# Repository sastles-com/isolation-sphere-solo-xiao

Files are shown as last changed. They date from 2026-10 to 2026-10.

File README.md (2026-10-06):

# isolation-sphere solo (XIAO ESP32S3 版)

> M5AtomS3R 版 ([isolation-sphere-solo](https://github.com/sastles-com/isolation-sphere-solo)) から分岐した、
> **XIAO ESP32S3 向けのリポジトリ**。LCD・本体ボタン・M5 ライブラリを持たない。本体の操作は iPhone の
> Web UI と IMU のトリプルシェイクで行い、今後は北極のホール素子をボタンにする (計画)。
> 共通部品の修正は AtomS3R 版から手動で取り込む。

球体 LED ディスプレイのファームウェア。**server なし (solo) と server あり (配信) の両方を 1 つの
バイナリで動かす**。

- **solo**: ESP32-S3 が SoftAP を立て、LittleFS に保存した 1 本の動画 (320×160 / 10fps) を電源投入だけで
  自動ループ再生する。動画の差し替えと再生操作は、個体シールの QR から iPhone を接続して
  Web UI (`http://192.168.4.1/`) で行う。MQTT ブローカー・配信 server・ルーター・インターネットは不要。
- **server モード** (`config.json` の `wifi{}` を有効にする、または Web UI の「サーバ接続 ON」): 同じ
  ファームが配信 server の P2P 網にも STA で入り、UDP で届く JPEG を優先して表示し、MQTT で操作を
  受ける。配信が 2 秒途切れると本体の動画に戻る。AP と Web UI はどちらのモードでも使える。

IMU による姿勢補正は描画側で動作し、球体を回しても映像の向きが保たれる。

> 派生元: [sastles-com/sastle-isolation-sphere](https://github.com/sastles-com/sastle-isolation-sphere)
> (server + core 構成)。本リポジトリは core の後継 (superset)。IMU スタック・OTA パーティション・
> 起動耐性は本リポジトリの方が新しく、MQTT / UDP のプロトコルは派生元の Python server と互換
> (server 側の変更は不要)。

---

## クイックスタート

```bash
# 1. ファームウェアと LittleFS を書き込む (初回は USB 必須: パーティション表を更新する)
pio run -e xiao_esp32s3 -t upload
pio run -e xiao_esp32s3 -t uploadfs

# 2. 動画を変換する (ffmpeg / ffprobe が必要)
tools/make_solo_video.sh input.mp4 video.mjpg -q 6

# 3. 電源投入 -> 個体シールの QR (tools/make_wifi_qr.py) を iPhone のカメラで読む -> AP に接続
#    -> 自動で開く画面、または Safari で http://192.168.4.1/ を開く
#    -> video.mjpg をアップロード
```

以降は電源を入れるだけで自動再生する (iPhone も PC も不要)。

## 動作の流れ

```
                  ┌──────────────── ESP32-S3 (XIAO) ────────────────────┐
                  │                                                      │
 iPhone ──Wi-Fi──▶│ SoftAP  ─▶ httpd (Web UI / アップロード)  [Core 0]    │
   │              │              │                                       │
   │ シールの QR   │              ▼                                       │
   └──個体シール───│         LittleFS  /video.mjpg                        │
                  │              │                                       │
 server ──STA────▶│ UDP (JPEG チャンク) ─▶ キュー   MQTT (操作/telemetry)  │
 (任意)           │              │                                       │
                  │    FramePump (1 タスク: 配信優先 / 100ms 締切) [Core 0] │
                  │      UDP 再構成 or ファイル読み ─▶ JPEG デコード ─▶ RGB565│
                  │              │                                       │
                  │      トリプルバッファ (display/ready/decode)           │
                  │              │                                       │
                  │    LEDManager (IMU 姿勢で毎パス再マッピング) [Core 1]   │
                  │              ▼                                       │
                  │        WS2812 ×800 (5ストリップ, RMT 並列出力)         │
                  └──────────────────────────────────────────────────────┘
```

- 再生は 10fps 固定。描画は ~50-60Hz で連続駆動し、IMU (100Hz) の最新姿勢で毎パス再マッピングする
  ため、動画のフレームレートと追従性は独立している。
- 締切は単調クロック (`esp_timer`) で管理し、遅れた締切は捨てる (遅延を溜め込まない)。

## リポジトリ構成

```
platformio.ini            ビルド設定 (xiao_esp32s3 / *_ota / native)
partitions.csv            フラッシュ配分 (OTA 2MB×2 + LittleFS 3.94MB)
src/                      ファームウェア
  main.cpp                起動順・タスク構成・loop (OTA / ネットワーク / MQTT / ログ)
  FramePump.{h,cpp}       フレーム供給の単一タスク (UDP 再構成 or ローカル再生 → デコード)
  SourceArbiter.h         配信 / ローカルの調停ポリシー (純粋、PC でテスト)
  SoloPlayer.{h,cpp}      ローカル MJPEG 再生の状態管理と 1 フレーム供給
  UdpReceiver.{h,cpp}     AsyncUDP → PSRAM キュー / FrameReassembler.h (16B ヘッダのチャンク再構成)
  DeviceController.{h,cpp} 操作の共通窓口 (HTTP / MQTT / コンソールが呼ぶ。γ2.2 明るさ、NVS 保存)
  SoloWebServer.{h,cpp}   Web UI・制御 API・アップロード・キャプティブポータル
  MQTTManager.{h,cpp}     MQTT (PubSubClient)。CommandHandler / Telemetry / TimeSync / RemoteLog
  MjpegReader.{h,cpp}     raw MJPEG の逐次読み出しと全件検証
  JpegScan.h              JPEG マーカー追跡によるフレーム境界判定 (PC でテスト可)
  ImageManager.{h,cpp}    JPEG デコード + トリプルバッファ
  LEDManager.{h,cpp}      球面 UV マッピング (SphereMap.h) / IMU 再投影 / FastLED 出力
  IMUManager.{h,cpp}      BNO055 (imu/*.h: 化け値検出・平滑・診断) 100Hz
  NetworkManager.{h,cpp}  SoftAP + STA (NVS の LAN > config の P2P 網)、Wi-Fi QR 文字列
  ...                     ConfigManager, Settings (NVS), FileManager, GestureManager, SoundManager, OtaManager
data/                     LittleFS に書き込む内容 (config.json, LED レイアウト CSV)
test/                     PC 上の単体テスト (JPEG 境界 / MJPEG 組み立て / IMU / 球面写像 / 調停 / 再構成)
tools/                    動画変換 / QR 生成 / OTA (ota.sh) / UDP 配信テスト (stream_to_sphere.py)
docs/solo_mode.md         設計と運用の詳細 (仕様・API・実機チェック手順)
docs/handoff.md           実装依頼時の仕様書
```

## 対応ボード

| env | ボード | 構成 |
| --- | --- | --- |
| `xiao_esp32s3` (既定) | Seeed XIAO ESP32S3 | 5ストリップ×160 LED (GPIO 1/2/3/4/44)、ブザー (GPIO43)、外部 BNO055、LCD なし。接続案内の QR は個体シール。ピンは `src/BoardConfig.h` に集約 |

## 動画の要件

- raw MJPEG: Baseline JPEG (SOF0) を区切りなしで連結したもの
- 320×160、10fps、音声なし、1 フレーム 64KiB 以下
- progressive JPEG・解像度違い・途中で切れたファイルは受理しない

`tools/make_solo_video.sh` が ffmpeg で変換し、ffprobe で解像度・フレーム数・最大フレームサイズを検査する。

容量: LittleFS 3.94MB のうち動画に使えるのは約 3.8MB。平均 10KiB/フレームなら約 38 秒。

## 操作

| 手段 | できること |
| --- | --- |
| Web UI (`http://192.168.4.1/`) | 状態確認、再生/一時停止/停止、明るさ、動画の変換とアップロード/削除、表示パターン、IMU 平滑、映像ソース、サーバ接続 ON/OFF、LAN 接続、再起動 |
| HTTP API | `GET /api/status`、`POST /api/play|pause|stop`、`/api/brightness`、`/api/led`、`/api/imu`、`/api/source`、`/api/server`、`/api/power`、`/api/wifi`、`/api/video`、`/api/video/delete`、`/api/reboot` |
| MQTT (server モード) | `sphere/all|<id>/command/{params,playback,led,system}` を受信、`sphere/<id>/{status,state,imu,log,gesture}` を送信 (派生元と同じ) |
| シリアルコンソール (115200) | `help` / `status` / `play` / `pause` / `stop` / `led sphere|test|off` / `bri N` / `server on|off` / `ap on|off` / `ap idle N` / `msleep on|off` / `power` (AP 切替) / `reboot` |

設定は `data/config.json` (`solo.ap.*`、`wifi{}` = server の P2P 網と broker、`source{}` = 調停、
`spheres[]` = MAC → 自機 ID / 固定 IP)。書き込みは `pio run -t uploadfs` (USB)。**サーバ接続の ON/OFF
だけは Web UI / コンソールから球体上の config.json を書き換えて再起動できる** (OTA では LittleFS を
更新できないため)。明るさ・軸表示・IMU 平滑・LAN の資格情報は NVS に保存される。

`solo.ap.ssid` は SSID の接頭辞です。実際の SSID は基板の MAC を付けた
`isolation-sphere-F09E9E3267D0` のような名前になり、複数台でも区別できます。
最大 32 bytes に収まるよう接頭辞を短縮し、Web 画面にも同じ名前を使います。
更新後は新しい SSID に接続し直してください。server モードの機器 ID・固定 IP は
`spheres[]` の MAC 登録で割り当てるため、追加基板には重複しない ID と IP を登録してください。

## 省電力 (AP / モデム)

球体の消費電力は WS2812 800 個が支配的ですが、デモ中は AP が不要なので止められるようにしてあります。
**電源投入時は常に AP 起動** で始まります。

| 機能 | 内容 |
| --- | --- |
| AP 自動停止 | 接続端末が 0 台のまま設定時間 (既定 10 分。しない/5/10/30/60) が経つと AP を止める。LAN (STA) が無ければ無線ごと止まる。設定は NVS に保存 |
| AP の ON/OFF | Web UI の「今すぐ停止」、`ap on|off`、MQTT `system` の `ap` |
| モデム省電力 | STA 接続中のビーコン間スリープ (WIFI_PS_MIN_MODEM)。既定 OFF。**AP だけの構成ではほぼ効かない** (AP は眠れない)。ON だと応答が鈍り UDP 映像を取りこぼしうる |
| トリプルシェイク | AP の ON/OFF を切り替える。従来の UI モード (回転アクション) は未実装だったため置き換え |

AP が止まっても再生は続きます。復帰は、シェイク / シリアル / MQTT / 電源の入れ直しのいずれかです。

## 開発

```bash
pio run -e xiao_esp32s3      # ビルド
pio test -e native            # 単体テスト 67 件 (実機不要)
pio device monitor            # シリアルログ (115200)
pio run -e xiao_esp32s3_ota -t upload   # OTA 書き込み (先に PC を AP へ接続)
tools/ota.sh                  # LAN / P2P 網経由の OTA (STA の IP を解決して直指定)
python3 tools/stream_to_sphere.py --target <STA の IP> --fps 15   # UDP 配信テスト (Pillow が必要)
```

詳細・設計判断・実機チェック手順は [docs/solo_mode.md](docs/solo_mode.md) を参照。

Mac で AP 経由の OTA を行う場合は、インターネット接続中に `xiao_esp32s3` をビルドし、
`tools/ota-ap.command` をダブルクリックしてください。ターミナルの案内に従って対象 core の
AP に接続し、Enter を押すとビルド済みファームを転送します。転送中のインターネット接続は不要です。
再起動後は新しい SSID に接続して Enter を押すと起動状態を確認できます。

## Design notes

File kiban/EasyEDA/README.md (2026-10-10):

# Isolation Sphere 電源システム — 基板A / 基板B

## 目的

次期 Isolation Sphere 電源システムの基本アーキテクチャを定義する。
別の LLM / 技術者がチャット履歴から判断を再構成せずに、EasyEDA で回路図と PCB を実装できるようにするためのパッケージである。

2026-10-07、本パッケージを電源系の正式案として採用した。
`kiban/power-2s`（IP2326 + MP1584、5V LED）は参考資料扱いとする。

設計は意図的に、40 mm × 40 mm の基板2枚を重ねる構成としている。

- **基板A — システム電源 / mother-ring インターフェース**
- **基板B — 電池 / 充電 / BMS**

基板Aは上側で MCU / 北極側を向く。基板Bは下側で LiPo パックを向く。

## システム要件

- 電池：**2S LiPo、2000 mAh × 2 直列**（40 × 40 × 10 mm を北と南に 1 個ずつ。重ね順は `docs/easyeda_workflow.md` §5.5、実機で収納確認済み）
  - 公称電圧：7.4 V（`VSYS` の公称値もこれに従う）
  - 満充電：8.4 V
  - 容量は 2000 mAh のまま（公称約 14.8 Wh）
- 充電入力：**南極のマグネット充電端子から 5〜12 V（推奨 12 V）**（`docs/hardware_spec.md` §3）
- 充電中の動作：**必須**
- 表示：アドレス指定型 LED 約 800 個
- 使用 LED：**WS2812C-2020-V6**（確定）を **3.3 V LED レール**で駆動
- LED レール：**想定 3 A、システムとして 4 A を確保。変換器は余裕のある品種を選ぶ**
- MCU レール：独立した **3.3 V レール**、**1〜2 A クラス**
- MCU：北極付近の別基板上の ESP32-S3（XIAO ESP32S3）
- 主制御バス：MCU 側からの I²C
- 基板サイズ：**各 40 mm × 40 mm**（基板Aは左右にソケット用の張り出し。基板Bは 37 mm 角または隅を面取りする案を検討中。`docs/easyeda_workflow.md` §5.5）
- 基板Aは両面実装可
- **基板Bの裏面は部品禁止**（LiPo パウチに面するため）
- 基板Bと LiPo の間に電気的・機械的な絶縁フィルムを挟む
- LiPo 側の面では、突起・露出パッド・鋭い基板角・不要な露出ビアを避ける

## 現在の基本アーキテクチャ

### 基板A — システム電源

mother-ring へ配る電源レールを生成し、電源 ON/OFF 制御を行う。

主な機能：

- LTC2954-1 電源 ON/OFF コントローラ
- 北極ホール起動センサ用の常時オン低 Iq レギュレータ
- LED 用 3.3 V 降圧コンバータ（4 A 必須、5〜6 A クラス推奨）
- MCU 用 3.3 V 降圧コンバータ（1〜2 A クラス）
- mother-ring との接続：1×6、2.54 mm コネクタ 2 個
- ESP32 からの `LED_EN` で LED 降圧を制御
- MCU 降圧は LTC2954 が制御
- ESP32 からの `PWR_KILL` で通常シャットダウン
- DRV5032FC からの `HALL_WAKE` で起動 / ハードウェア長押しを行う

### 基板B — 電池 / 充電 / BMS

2S LiPo と充電インターフェースに直結する。

主な機能：

- BQ25792 2S 充電 / パワーパス IC（昇降圧、入力 3.6〜24 V、LCSC C2862876）
- BQ28Z620 1〜2S 残量計 + パック保護 + セルバランス（BQ28Z610-R1 の後継、ピン互換）
- BQ28Z620 リファレンス設計どおりの外付け保護 FET と電流検出シャント
- 2S 電池接続：セルごとに JST XH 2P。直列接続とセル中点（BM）は基板B上で作る
- 南極マグネット充電端子からの充電入力
- 基板Aへの保護済み / システム電池出力
- 基板A / mother-ring 経由で ESP32 と I²C 接続

### 置き換え対象の旧モジュール

以下は現行 / 旧ハードウェアのもので、**新設計の基本構成ではない**。

- IP2326 充電モジュール
- BQ25883（旧案。12 V 入力に対応できないため BQ25792 に変更）
- XR-2S-30A BMS 基板
- MP1584 5 V 変換モジュール
- MAX16054 電源スイッチコントローラ
- MAX17049 残量計

実績のある動作や特性は検証時の参考にしてよいが、新設計はゼロベースで行う。

## 北極のデバイス

北極には以下がある。

- **DRV5032FC**：常時オンのデジタルホールスイッチ（全極性・オープンドレイン・20 Hz）。電源 ON と、LTC2954 へのハードウェア長押し経路に使う。
- **WS2812C-2020-V6 ×1**：北極の LED。XIAO の D5 から直接駆動する 6 本目のストリップ（1 個）。電源は `3V3_MCU` なので、`LED_EN` と関係なく起動・状態表示に使える。
- 動作確認用の赤 LED：DRV5032FC が磁石を検出している間だけ点く（`3V3_AON` から約 1.4 mA。確認後は抵抗を外す）。

北極基板（`kiban/core-XIAO-04` の north-pole-04）と MCU 基板の間は 5 本（`3V3_AON`、`HALL_WAKE`、GND、`LED_D6`、`3V3_MCU`）。
I²C は北極へ行かない。ジェスチャ（通常 OFF を含む）は磁石ではなく、MCU 基板の IMU（BNO055）によるシェイクで判定する（2026-10-10 決定。TMAG5273 は廃止）。
- 任意の小型インジケータ LED：ホール / コマンドの受付表示のためだけに追加してよい。OFF 中に動作する必要は**ない**。

## 電源制御の動作

### 電源 ON

1. システムは OFF。
2. DRV5032FC は `3V3_AON` で常時動作している。
3. 北極に磁石を近づけて保持する。
4. LTC2954 が長押し（約 2 秒）を確認し、MCU 降圧を有効にする。
5. ESP32-S3 が起動する。
6. 表示電源が必要になった時点で、ESP32 が明示的に `LED_EN` をアサートする。

ON のために近づけた磁石を保持し続けても、OFF 操作とは扱わない。LTC2954 は起動後 512 ms は PB を無視し、その後は「一度離してから再び押す」ことで初めて OFF シーケンスを開始する。

### 通常の電源 OFF

1. システムは ON。
2. ESP32 が IMU（BNO055）で、OFF 用のシェイク動作を検出する。
3. ESP32 がブザーや北極 LED で予告し、取り消しがなければ OFF に進む。
4. ESP32 が最初に `LED_EN` をデアサートする。
5. ESP32 が必要な状態保存 / 終了処理を行う。
6. ESP32 が `PWR_KILL` を Low にして LTC2954 へ伝える。
7. LTC2954 が MCU システム電源を切る。

### 強制 OFF

ESP32 がハングしていても、磁石を十分長く保持すれば、LTC2954 の独立したハードウェアタイマでシステム電源を強制的に切れなければならない。

タイミングは LTC2954 データシートの式から以下とする（詳細は `docs/hardware_spec.md` §5）。

| 操作 | コンデンサ | 公称 | 部品ばらつき込みの範囲 |
| --- | --- | ---: | ---: |
| ON 長押し | C_ONT = 0.33 µF | 約 2.15 s | 約 1.5〜2.8 s |
| 強制 OFF 長押し | C_PDT = 1.2 µF | 約 7.8 s | 約 5.5〜10 s |

正式リリース前に実機で確認する。

## mother-ring 接続

基板Aには mother-ring と接続する **1×6、2.54 mm コネクタ**が左右に1個ずつある。

論理ピン割り当ては `docs/interfaces.md` にまとめている。

最大約 4 A の LED 電流が 1 本のピンに集中しないよう、LED 電源は左右の2系統に分けて給電する。

## 実装状況

アーキテクチャと各基板の役割は、回路図作成を始められる程度に確定している。ただし、部品レベルではまだ最新のデータシートとリファレンス設計との照合が必要な項目がある。それらは `docs/handoff.md` と `docs/hardware_spec.md` にまとめている。

回路図、パワーパス構成、保護構成、ピン割り当て、EasyEDA ライブラリ部品のレビューが終わるまで、製造用ファイルは作らない。

## 本パッケージのファイル

- `README.md`：プロジェクト概要と確定アーキテクチャ
- `docs/handoff.md`：実装担当（LLM / 技術者）への指示
- `docs/hardware_spec.md`：電気・機械・安全要件
- `docs/interfaces.md`：ネット、コネクタ、信号方向、電源ドメイン、ファームウェア要件
- `docs/design_spec.yaml`：スクリプト / 整合性チェック用の機械可読サマリ
- `docs/sources.md`：一次データシートへのリンクと確認チェックリスト
- `docs/easyeda_workflow.md`：EasyEDA での設計の進め方、基板間接続、LiPo 接続、コア内の収納検討
- `docs/cad/`：配置検討に使ったコアの STL と説明

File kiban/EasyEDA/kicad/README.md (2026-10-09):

# kicad/ — 回路図の KiCad 版（自動生成）

**このフォルダの回路図は自動生成物。手で編集しない。** 正本は EasyEDA Pro のプロジェクト `power-2s-xiao`。
KiCad で回路図を見る・レビューするためのスナップショット。

| フォルダ | 親シート | 子シート |
| --- | --- | --- |
| `boardA/` | `boardA.kicad_sch`（1 枚、`kicad_flat.py` で生成） | なし |
| `boardB/` | `boardB.kicad_sch`（1 枚に統合） | なし |

KiCad で `boardA/boardA.kicad_pro`（または `.kicad_sch`）を開き、親シートの四角をダブルクリックして各ページへ入る。

## 作り直し方

EasyEDA で回路図を変えたら、ブリッジを起動して EasyEDA を接続した状態で：

```sh
python3 tools/kicad/kicad_export.py          # 両方の基板
```

1. 各ページを開いて保存し、全要素を取り出す（`dump_<PAGE>.json`）
2. KiCad 10 形式の階層回路図に変換する
3. **kicad-cli で KiCad 本体にネットリストを書き出させ、EasyEDA のネットリストとピン集合で比べる**。`✅ ネットリスト一致` が出ることを毎回確認する

作業中は EasyEDA のタブを切り替えない（別のページを取り出してしまう）。

## 変換の仕組み

| 項目 | 内容 |
| --- | --- |
| 接続 | EasyEDA の「ネット名を付けた線」を、つながった線の島ごとに KiCad のラベルへ置き換える |
| ラベルの種類 | 2 ページ以上に出てくるネット（`VSYS`、`GND`、`I2C_SDA` など）はグローバルラベル、それ以外はローカルラベル |
| シンボル | EasyEDA と同じピン位置を持つ矩形のシンボルを生成する（抵抗もジグザグにならない） |
| 文字・枠 | 注釈の文字と破線の枠をそのまま移す。ネット名を表すための文字は、ラベルと重複するので移さない |
| 座標 | EasyEDA 回路図 1 単位 = 0.254 mm。KiCad の標準グリッドに一致する |
| 部品の情報 | `LCSC`、`MPN` フィールドに保持する |

道具は `tools/kicad/`。座標変換・シンボル生成は、FPC-isolation-sphere の power-2S-02 で作った変換ツール（`eda2kicad_core.py`）を取り込んだもの。

## LCSC のシンボル・フットプリント（`kicad/lib/`）

`easyeda2kicad` で、LCSC 番号からシンボル・フットプリント・3D モデルを取得して使う。

```sh
pipx install --backend pip easyeda2kicad      # 初回だけ
python3 tools/kicad/lcsc_lib.py                # 未取得の部品を取得して整える
python3 tools/kicad/kicad_export.py            # 取得したシンボルで作り直す
```

- `kicad/lib/lcsc.kicad_sym`、`lcsc.pretty/` は Git に入れる。`lcsc.3dshapes/`（1 部品 2〜3 MB）は入れない。必要なら `lcsc_lib.py` で取得し直す
- 各プロジェクトの `sym-lib-table` / `fp-lib-table` に `lcsc` ライブラリを登録済み
- 取得したシンボルは、EasyEDA の回路図とピン位置が一致する向き（0/90/180/270°）を自動で探して使う。合わない部品と未取得の部品は、従来の矩形シンボルにする
- **EasyEDA の API は、続けて 30 部品ほど取得すると 403 を返す**（一時的なブロック）。時間を置いて `lcsc_lib.py` を再実行すると、未取得の部品だけを取得する

## 限界

- 未取得の部品は矩形シンボルで、フットプリントは空
- **ERC は通らない。** 電源フラグ（`PWR_FLAG`）がないため
- 取得したフットプリント（特に QFN の熱パッドとピン番号）は、データシートと照合していない

## 検証結果（2026-10-08）

| 基板 | 部品 | 2 ピン以上のネット | 結果 |
| --- | ---: | ---: | --- |
| 基板A | 44 | 23 | ✅ 一致 |
| 基板B | 67 | 43 | ✅ 一致 |

## 基板B は KiCad 側で統合した（2026-10-09）

基板B の回路図は、CHARGER と PROTECTION を手で 1 枚（`boardB/boardB.kicad_sch`）に統合し、**KiCad 側が元データ**になった。
EasyEDA からの自動生成（`kicad_export.py boardB`）は、統合前の 2 枚構成を作り直して上書きするので、**もう実行しない**。
フットプリントと LCSC 品番の割り当ては `python3 tools/kicad/assign_footprints.py`（L2 は `lcsc_lib.py` で C87572 を取得してから）。

## 基板A も 1 枚にした（2026-10-09）

基板A は、EasyEDA のダンプとネットリストから、基板B と同じ書き方で 1 枚の回路図に作り直した。

```
python3 tools/kicad/kicad_flat.py      # → kicad/boardA/boardA.kicad_sch、refmap.json
```

- ルール：階層なし 1 枚（A3）、機能ごとの点線の枠と日本語の見出し、接続は短い線 + グローバルラベル、GND は部品ごとに GND 記号、
  標準の抵抗・コンデンサ・インダクタ記号、通し番号の部品名（旧名は `refmap.json` と、部品の `EasyEDA` プロパティ）
- 生成の直後に kicad-cli のネットリストを、EasyEDA のネットリスト（`outputs/schematic/boardA_nets.txt`）と照合する
- 基板A の元データは EasyEDA のまま。回路を変えたら、EasyEDA を直し、ダンプとネットリストを更新して、`kicad_flat.py` を実行する。
  KiCad 側で手直しすると、次の生成で上書きされる（基板B と違い、基板A は KiCad を元データにはしていない）

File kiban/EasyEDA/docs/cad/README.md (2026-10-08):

# コアの STL（配置検討に使ったもの）

`tools/fit_check.py` が基板とセルの収まりを調べるときに読む STL。2026-10-08 に保存した。

| ファイル | 内容 | 三角形数 | SHA-256 |
| --- | --- | ---: | --- |
| `core-north-03_fixed.stl` | コア北半球（z = 0.8〜35.9） | 128,060 | `1618eacb0b87b0c43ef1db8b81d28fb9e6e38664ddcd4a09068b4914f9f9daea` |
| `core-south-03_fixed.stl` | コア南半球（z = 0.8〜44.9） | 139,892 | `1d71c652ab1ce8d9f98553ca6e833371c4f80c63eadead569d67c85ce4b5a66a` |

- 元のファイル：`FPC-isolation-sphere/shell-cad/output/` の同名ファイル（2026-06-17 / 06-18 作成）。
  元のリポジトリではこのフォルダ全体が `.gitignore`（`*`）で除外されているため、ここに保存しないと再現できない。
- 単位は mm、バイナリ STL。北半球・南半球とも、軸を z、極側を +z としてモデル化されている。
  南半球は赤道軸まわりに 180° 回して（y → −y、z → −z）南側に置く。
- mother-ring の STL は使っていない（作り直すため）。現行の `kiban/mother-ring/kiban-mother-ring.stl` は別にある。

## 断面が「島状」になるとは

コアを z 一定の平面で切ると、断面は 1 本の輪ではなく、円周に沿って並んだ**ばらばらの小さな塊**になる（`outputs/fit/section_z*.svg` の黒い線）。
塊は柱やボス（ねじ止め用の突起）で、塊と塊のあいだは空いている。さらに左右（±x）には、U 字の溝や四角い塊がある。

そのため、基板やセルが収まるかは、「軸から最も近い塊までの距離」ではなく、**塊の一つひとつに当たるか**で調べる必要がある。

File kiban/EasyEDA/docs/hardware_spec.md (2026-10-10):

# ハードウェア仕様

## 1. 機械的制約

### 基板A

- サイズ：40 mm × 40 mm
- 位置：上側。MCU / 北極 / mother-ring に近い側
- 部品：両面実装可
- 1×6、2.54 mm の mother-ring コネクタ 2 個を対向する辺に配置
- 大電流の 3.3 V 出力を基板Aから mother-ring へ配る

### 基板B

- サイズ：40 mm × 40 mm
- 位置：下側。LiPo パウチの直上
- **裏面：部品禁止**
- 裏面の突起、テストピン、露出したはんだ盛り、鋭い機械的形状を避ける
- LiPo 側の面のビアは、可能な範囲でテンティングする
- 基板の角を丸め、LiPo 付近の鋭いエッジを避ける
- 基板と LiPo の間に薄い絶縁 / 保護フィルムを入れる
- 損失の大きい充電・FET・シャント部品は部品面に置き、可能ならパウチ中央直上の最も熱い領域を避ける

## 2. 電池

- 2S LiPo
- 1 セル 2000 mAh を 2 直列
- 公称 7.4 V
- 満充電 8.4 V
- 公称エネルギー 約 14.8 Wh
- セル中点（`BM`）は取り出し可能で、現行設計でも使用している
- 接続：セルごとに JST XH 2P。直列接続と中点は基板B上で作る（`easyeda_workflow.md` §5）
- 放電終止：1 セル 3.2 V 以上（パック 6.4 V 以上）。XH の 3 A を超えないための条件
- 配置：セルは北と南に 1 個ずつ。重ね順（北から）MCU – セル – mother-ring – セル – 基板A – 基板B は、実機で収納を確認済み（`easyeda_workflow.md` §5.5）

## 3. 充電

要件：

- 南極のマグネット充電端子から入力
- 充電中もシステムが動作できること
- 充電 / システムのパワーパスがパック保護を迂回しないこと
- 小型の球体筐体であるため熱制限を考慮すること
- MCU が OFF でも充電できること
- 充電電流はセル仕様・入力電力の予算・熱性能から決める。IC が対応しているからといって 2 A を前提にしない

充電 IC：**BQ25792**（BQ25792RQMR、LCSC C2862876、2026-10-08 確定）

| 項目 | 値 |
| --- | --- |
| 方式 | 昇降圧、NVDC パワーパス、FET 4 個と BATFET を内蔵 |
| 入力動作範囲 | 3.6〜24 V（絶対最大 30 V）。入力過電圧保護の初期値は 26 V |
| 充電電流 | 最大 5 A（10 mA 刻み） |
| 電池からの放電電流 | 6 A RMS 連続、10 A ピーク（1 s 以内） |
| 電池のみで動作中の静止電流 | 17 µA typ（ADC 無効時） |
| I²C アドレス | 0x6B |
| パッケージ | VQFN-29（4 mm × 4 mm） |
| 互換品 | BQ25798（MPPT とバックアップ機能を追加、ピン配置は同じ） |

選定理由（比較は §3.3）：

- 5 V と 12 V のどちらの入力でも充電できる
- PROG ピンの抵抗で 2 セルを選ぶと、ホストなしで 8.4 V・1 A の充電を開始する（初期値）。MCU が OFF でも充電できる
- 入力過電圧保護の初期値が 26 V なので、12 V 入力でもホストの設定なしで充電が始まる
- BATFET の連続放電 6 A は、`VSYS` 最大約 3.1 A に十分な余裕がある

実装時の注意：

- PROG ピン：2 セルの抵抗値を使う（1.5 MHz なら 6.04 kΩ、750 kHz なら 8.2 kΩ）。周波数はインダクタの大きさと効率で決める
- ILIM_HIZ ピン：入力電流の上限を分圧抵抗で決める（`V = 1 V + 0.8 Ω × IINDPM`）。使う充電器の定格に合わせる
- ウォッチドッグ：初期値は 40 s。ファームから設定を変える場合は定期的に更新するか、ウォッチドッグを無効にする。放置すると設定が初期値に戻る
- 2 系統の入力切り替え（ACFET / RBFET）は使わない。入力は VAC1 / VBUS の 1 系統とする
- TS ピン：103AT-2（10 kΩ NTC）を推奨

実装は最新の TI データシートとリファレンス回路（BQ25792EVM）に従うこと。

### 3.1 電力予算

| 項目 | 値 |
| --- | ---: |
| LED 出力 3.3 V × 4 A | 13.2 W |
| MCU 出力 3.3 V × 1 A | 3.3 W |
| 出力合計 | 16.5 W |
| `VSYS` 入力（降圧効率 90% と仮定） | 約 18.3 W |

`VSYS` の公称は 7.4 V とする。電流は電池電圧に反比例するため、コネクタ・FET・銅箔は最低電圧で見積もる。

| `VSYS` | 電流（18.3 W） |
| --- | ---: |
| 8.4 V（満充電） | 約 2.2 A |
| 7.4 V（公称） | 約 2.5 A |
| 6.0 V（放電終止付近） | 約 3.1 A |

基板A↔B 間のコネクタ、BQ28Z620 の保護 FET、シャント、充電 IC の SYS/BATFET 経路は **3 A 以上の連続電流**を前提に選定する。
全負荷時の連続動作時間は 14.8 Wh ÷ 18.3 W ≈ **約 48 分**（変換損失以外の余裕は見ていない）。

### 3.2 充電入力電圧

全負荷で動作しながら 1 A（8.4 V）で充電するには、充電器の入力として概算で以下が必要になる。

- システム負荷：18.3 W ÷ 充電器効率 93% ≈ 19.7 W
- 充電：8.4 W ÷ 93% ≈ 9.0 W
- 合計：**約 29 W**

| 入力電圧 | 必要電流（29 W） | 判断 |
| --- | ---: | --- |
| 5 V | 約 5.8 A | 全負荷中の充電は不可。マグネット接点にも厳しい |
| 9 V | 約 3.2 A | 接点の定格次第で可 |
| 12 V | 約 2.4 A | 現実的 |

**方針**：BQ25792 は 3.6〜24 V を受けられるため、入力は **5〜12 V 対応、推奨 12 V** とする。

- 5 V の充電器も使える。ただし入力電力が小さいため、全負荷時は電池から不足分を補い、電池は減り続ける。充電が進むのは表示負荷が小さいときだけ。
- 12 V の充電器なら、全負荷中も充電できる。
- 12 V から 8.4 V へ下げるときの損失は約 1.5 W（効率 95% と仮定）。基板Bの熱設計に含める。

未決事項：

- 南極のマグネット接点と配線の電流定格を、12 V × 2.5 A で確認する
- 12 V の供給方法（12 V アダプタ、または USB-PD トリガ）
- ILIM_HIZ で設定する入力電流の上限

### 3.3 充電 IC の比較（2026-10-08）

| 項目 | BQ25883（旧案） | **BQ25792（採用）** | BQ25798 | MP2762A（MPS） |
| --- | --- | --- | --- | --- |
| 方式 | 昇圧のみ | 昇降圧 | 昇降圧 | 昇降圧（2 相） |
| 入力 | 3.9〜6.2 V | 3.6〜24 V | 3.6〜24 V | 約 4〜21 V（5.75〜8.5 V は不可） |
| 12 V 入力 | 不可 | 可 | 可 | 可 |
| 充電電流 | 2 A | 5 A | 5 A | 6 A |
| MPPT / バックアップ | なし | なし | あり（不要） | なし |
| 入力過電圧保護の初期値 | — | 26 V | 26 V | — |
| パッケージ | QFN-24 4×4 | QFN-29 4×4 | QFN-29 4×4 | QFN-30 4×5、インダクタ 2 個 |
| LCSC | C544362 | C2862876 | C2876593 | 在庫を確認できず |
| LCSC 100 個単価 | $2.10 | $1.35 | $2.00 | $2.4〜4.2（他の代理店） |

不採用の理由：

- BQ25883：12 V 入力に対応できず、5 V では入力が約 15 W に制限される
- BQ25798：BQ25792 の機能に MPPT とバックアップを加えたもの。本設計では不要で、価格が高い。ピン配置が同じなので、必要になれば差し替えられる
- MP2762A：インダクタが 2 個必要で、40 mm 角の基板Bでは面積が不利。LCSC の在庫を確認できない
- BQ25790（同系統）：入力過電圧保護の初期値が 7 V のため、12 V 入力ではホストが設定するまで充電しない

## 4. パック保護 / 残量計

残量計 / 保護 IC：**BQ28Z620**（BQ28Z620DRZR、VSON-12、2026-10-08 確定）

このサブシステムに求める機能：

- 1〜2S の残量計測
- パック保護
- 設定したしきい値による過電圧 / 低電圧 / 過電流 / 短絡保護
- シャントによる電流測定
- IC / リファレンス設計が対応する範囲でのセルバランス
- ESP32 への I²C 報告

外付けの保護 FET、電流検出シャント、サーミスタ、各種設定は、リファレンス設計（BQ28Z620EVM）の指示どおりに用意する。

このサブシステムは、旧構成の XR-2S-30A + MAX17049 を置き換える。

重要：ESP32 が OFF またはクラッシュしていても、保護は自律的に働くこと。

### 4.1 BQ28Z610 / BQ28Z610-R1 / BQ28Z620 の違い

| 項目 | BQ28Z610（無印） | BQ28Z610-R1 | **BQ28Z620（採用）** |
| --- | --- | --- | --- |
| 位置づけ | 初版 | 無印の I²C タイムアウト不具合をシリコンで修正。ファームウェアは無印と互換なし | R1 の後継。TI が新規設計に推奨 |
| パッケージ | VSON-12（DRZ） | 同じ | 同じ（ピン互換） |
| I²C | — | — | 1.2 V ロジックの I/O。VIH 0.78 V、SDA/SCL 推奨上限 5.5 V なので 3.3 V プルアップで使える |
| その他（620 の変更点） | — | — | 保護 FET のゲート駆動に 5.75 V を追加（SLEEP 時の消費電流を削減）、1 mΩ 未満のシャントに対応、BTP 機能を削除 |
| LCSC / JLC | C157573（在庫あり） | 見つからない | **C20345237**（LCSC、64 個）。JLC 登録 C22395771 は購入不可 |

無印は新規設計に推奨されないため使わない。フットプリントは 3 品種で共通なので、入手経路が決まらなくても回路図と PCB の作業は進められる。

### 4.2 設定の注意

- **ブロードキャスト（Master Mode）は無効にする。** スマートチャージャー向けに充電電流・電圧を I²C で送る機能で、BQ25792 は受け取らない。データシートの設計例では有効になっている
- 低電圧保護（CUV）は 3200 mV / セル以上にする（XH の電流定格のため、§2）
- I²C バスが約 2 秒 Low に保持されると、BQ28Z620 はバスを解放する（ハードウェアの初期値）
- 2S の設定、容量、化学特性（Chem ID）は bqStudio で書き込む。手順は BQ28Z620 テクニカルリファレンスマニュアルに従う

## 5. システム電源制御

基本構成：**LTC2954-1 + DRV5032FC**

### LTC2954（選定：LTC2954-1）

- 基板Aに配置
- `VSYS` から直接給電（動作範囲 2.7〜26.4 V、静止電流 6 µA typ）
- MCU 電源レールのイネーブルを制御
- 意図的に遅延させた電源 ON
- KILL による MCU 主導のクリーンなシャットダウン
- MCU が応答しない場合のハードウェア強制 OFF 経路

**バリアント**：**LTC2954-1**（EN はハイアクティブ、低リークのオープンドレイン）。MCU 降圧の EN（ハイアクティブ）に直結する。プルアップは降圧 IC 内蔵のものを使うか、外付けする。外付けする場合は、降圧 IC の EN 絶対最大定格を超えない電源へつなぐ。
パッケージは TSOT-23-8（LTC2954CTS8-1 / LTC2954ITS8-1）。LCSC の在庫は要確認。

**タイミング**（データシートの式 `C [µF] = 1.56×10⁻⁴ × (t[ms] − 1)`。ONT/PDT の内部電流 ±20%、コンデンサ ±10% で見積もった）：

| 項目 | 部品 | 計算 | 公称 | 範囲 |
| --- | --- | --- | ---: | ---: |
| ON 長押し | C_ONT = 0.33 µF | 32 ms + 2.12 s | 約 2.15 s | 約 1.5〜2.8 s |
| 強制 OFF 長押し | C_PDT = 1.2 µF | 64 ms + 7.69 s | 約 7.8 s | 約 5.5〜10 s |
| KILL ブランキング | 内部固定 | — | 512 ms | 400〜650 ms |
| OFF 後の再 ON 禁止 | 内部固定 | — | 256 ms | 200〜325 ms |

- コンデンサは X7R 以上、±10% 以内。ONT/PDT ピンは 2.7 V 以下で動作するため、DC バイアスによる容量低下は小さい。
- 起動直後の 512 ms は PB と KILL を無視する。その後、PB を「一度離してから押し直す」まで OFF シーケンスは始まらない。ON に使った磁石をそのまま保持しても OFF にはならない。
- システム ON 中に PB が 32 ms 以上 Low になると、INT 出力（オープンドレイン）が Low になる。INT は mother-ring コネクタに割り当てていない。使う場合は基板Aのテストパッドから引き出す（任意）。
- **`PWR_KILL` は基板A上で 100 kΩ を `3V3_MCU` へプルアップする。** MCU レールが立ち上がると KILL が自動で High になり、512 ms 以内の KILL 解除を満たす。ESP32 のリセット中（OTA 後の再起動やパニック）は GPIO がハイインピーダンスになるが、プルアップのため電源は切れない。プルダウンにすると、ESP32 がリセットするたびに電源が落ちる。ファームウェア要件は `interfaces.md` §7。

### DRV5032（選定：DRV5032FCDBZR）

- 北極に配置
- 常時オンの 3.3 V から給電（VCC 1.65〜5.5 V）
- 常時オンの磁気起動検出に使用
- **DRV5032FCDBZR**（SOT-23）を選ぶ。

| 項目 | FC の仕様 | 選定理由 |
| --- | --- | --- |
| 磁気応答 | 全極性（N/S どちらでも反応） | 磁石の向きを気にせず操作できる |
| 出力 | オープンドレイン、磁界検出時 Low | LTC2954 の PB（アクティブ Low、内部 100 kΩ で 1.9 V へプルアップ）に直結できる。プッシュプル品は PB の内部プルアップと競合するため不可 |
| サンプリング | 20 Hz（最大 50 ms の検出遅れ） | 2 秒の長押し判定には十分 |
| 平均消費電流 | 1.3 µA | OFF 中の電池消費が小さい |
| しきい値 B_OP | 最大 4.8 mT | 高感度 |

- 外付けプルアップは不要。PB の内部プルアップを使う。
- 北極から基板Aまで配線が長いため、LTC2954 データシートの推奨に従い、PB 直近に直列 5.1 kΩ と PB–GND 間 0.1 µF を置く。磁石検出時の PB 電圧は 1.9 V × 5.1k / 105.1k ≈ 0.09 V で、しきい値（0.6 V 以上）を十分下回る。
- 誤検出が問題になる場合の代替：**DRV5032AJ**（全極性・オープンドレイン、B_OP 最大 9.5 mT、同じピン配置）。
- 磁石の種類と、北極外殻からセンサまでの距離で磁束密度を確認する（未実施）。

### TMAG5273（廃止、2026-10-10）

- 当初は北極に置き、磁気ジェスチャと通常 OFF の検出に使う予定だった
- 北極への配線（7 本）を減らすため廃止した。I²C を北極へ通さず、配線は 5 本になった
- ジェスチャ（通常 OFF を含む）は、MCU 基板の IMU（BNO055）によるシェイクで判定する
- 磁石の役目は、ON（約 2.15 s）と強制 OFF（約 7.8 s）だけになった。どちらも DRV5032FC と LTC2954 のハードウェアで動く

### 北極の動作確認用 LED

- `3V3_AON` → 1 kΩ → 赤 LED → `HALL_WAKE`。DRV5032FC が磁石を検出して OUT が Low の間だけ点く（約 1.4 mA）
- 磁石がないときは LED に 3.3 − 1.9 = 1.4 V（PB の内部プルアップ）しかかからず、ほぼ流れない
- 確認が済んだら抵抗を外す

## 6. 常時オンレール

基板Aには、DRV5032FC と、本当に常時動作が必要な最小限の回路だけに `3V3_AON` を供給する専用の低静止電流レギュレータが必要。

設計目標：

- 超低 Iq
- 2S / `VSYS` の入力範囲に対応
- DRV5032FC（平均 1.3 µA）に少しの余裕を持たせた出力電流
- 選定したコンデンサで安定

明確な理由がない限り、残量計や大きなシステム負荷を AON レールに載せない。

OFF 中に電池から流れる電流の目安（レギュレータの Iq を除く）：LTC2954 6 µA + DRV5032FC 1.3 µA + BQ25792 17 µA + BQ28Z620 の待機電流。

## 7. 3.3 V コンバータ

独立した DC/DC コンバータを 2 個使う。

### LED 用コンバータ

- 入力：基板Aの `VSYS`
- 出力：3.3 V
- 想定最大負荷：約 3 A
- システムとしての設計能力：約 4 A
- 電流と熱の余裕のため **5〜6 A クラスの同期整流降圧**を推奨
- EN 入力が必須
- EN は ESP32 から `LED_EN` で制御
- MCU が未接続または起動中のときはデフォルト OFF
- `3V3_LED_L` と `3V3_LED_R` に供給

以前に検討した候補：TPS56637（6 A クラス）。レイアウト、入手性、効率、熱、EasyEDA / JLC 実装の制約を確認するまで、最終品種は**確定しない**。

### MCU 用コンバータ

- 入力：基板Aの `VSYS`
- 出力：3.3 V
- 目標：1〜2 A クラス
- LTC2954-1 の EN（ハイアクティブ、オープンドレイン）と互換の EN 入力を持つこと
- ESP32-S3 と、システム ON 中に動くロジック / センサに供給
- ESP32 の Wi-Fi 送信時の過渡電流に余裕を持って耐えること
- 立ち上がり時間は KILL ブランキングの最小値 400 ms より十分短いこと（通常の降圧のソフトスタートは数 ms なので問題ない見込み）

以前に検討した候補：TPS62162 は 1 A 品のため参考候補にとどめる。1 A を超える余裕が必要なら最終候補にはしない。

## 8. LED サブシステム

- 使用 LED：**WS2812C-2020-V6**（確定）
- LED レール：3.3 V
- 個数：約 800
- 北極の WS2812C-2020-V6 は、XIAO の D5 から直接駆動する 6 本目のストリップ（1 個）。電源は `3V3_MCU`（北極への配線を減らすため。最大 15 mA）
- LED 電源が OFF のときもデータ線を安全な状態に保つ。MCU 出力からデータピンを通して LED レールへ実質的に逆給電しないようにする

### 8.1 WS2812C-2020-V6 の仕様（Worldsemi データシート V1.0、2026-05-21）

LCSC C55109522（SMD2020-4P）。

| 項目 | 値 | 本設計への影響 |
| --- | --- | --- |
| 電源電圧 VDD | +3.3〜+5.3 V（「3.3 V で安定供給可能」と明記） | 3.3 V レールは保証範囲内。ただし下限ちょうど |
| 入力 High レベル VIH | 0.55 × VDD 以上（3.3 V 時 1.82 V） | ESP32 の 3.3 V 出力をレベル変換なしで直結できる |
| 入力 Low レベル VIL | 0.7 V 以下 | — |
| ロジック入力電圧 VI | −0.3 V〜VDD + 0.7 V | LED 電源 OFF 中にデータ線を High にすると定格外。FW-2 で Low に固定する |
| 各色の動作電流 | 5 mA（1 LED あたり最大 15 mA） | 下記の電流予算を参照 |
| 静止電流 | 1 µA 以下 | 800 個で 0.8 mA 以下 |
| 静電容量 / デカップリング | 各 LED の VDD に 100 nF 推奨 | mother-ring 側の設計事項 |

**電圧降下の余裕がない**：3.3 V は VDD の下限である。降圧の出力を 3.3 V ちょうどにすると、mother-ring のコネクタ・配線・ストリップの抵抗で電圧が下がり、末端の LED は保証範囲を外れる。
LED 降圧の出力は**分圧抵抗で 3.4〜3.5 V に設定できる構成**にしておき、実機で末端電圧を測ってから値を決める。
3.5 V にしても VIH は 1.93 V なので、ESP32 の 3.3 V 出力で駆動できる。

**電流予算**：全点白の最大輝度では 800 × 15 mA = 12 A になり、LED レールの設計値 4 A を大きく超える。
ファームウェアで全体の電流を 4 A 以下（1 LED あたり平均 5 mA 相当）に制限すること（例：FastLED の電力制限）。

## 9. I²C

I²C は ESP32-S3 の MCU 基板から出る。

接続予定のデバイス：

| デバイス | 位置 | 7 ビットアドレス |
| --- | --- | --- |
| BQ25792 | 基板B | 0x6B（データシートで確認済み） |
| BQ28Z620 | 基板B | 0x55（TI 残量計の標準。テクニカルリファレンスマニュアルで要確認） |
| BNO055（秋月 AE-BNO055-BO） | MCU 基板 | 0x28（出荷時） |

要件：

- デバイスアドレスの衝突を確認する
- プルアップの位置を意図して決める
- `3V3_MCU` が OFF のとき、プルアップを通じて逆給電しないこと
- 立ち上げ時のバス速度は控えめにする（例：100 kHz）。mother-ring / 積層基板経由の信号品質を確認してから上げる

## 10. 熱の優先度

発熱が大きいと予想される部品：

- LED 降圧コンバータとインダクタ
- 充電器の電力段とインダクタ
- 高負荷時のパック保護 FET / シャント

要件：

- 損失の大きい部品を LiPo 側の面から離す
- 機械設計が許す範囲で十分な銅箔面積 / サーマルビアを確保する
- 充電器と LED 降圧の熱を同じ場所に集中させない
- 開放したベンチだけでなく、閉じた球体の中で連続動作を確認する

## 11. 安全 / 検証

量産用の LiPo セルを接続する前に：

- 可能ならベンチ電源 / 電池シミュレータで充電動作を確認する
- セルごとの過電圧 / 低電圧動作を確認する
- 過電流 / 短絡保護を確認する
- 保護からの復帰動作を確認する
- 充電と負荷の同時動作を確認する
- ESP32 を意図的に応答不能にした状態で強制シャットダウンを確認する
- データ / 制御信号から無効化したレールへの逆給電がないことを確認する
- LED 負荷を連続でかけたときのコネクタ温度を確認する
- ON / 強制 OFF の長押し時間を実測し、§5 の範囲に収まることを確認する

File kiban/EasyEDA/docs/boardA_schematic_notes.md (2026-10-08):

# 基板A 回路図ノート（電源制御・3.3 V 電源・コネクタ）

2026-10-08 時点。EasyEDA の `power-2s-xiao` → `BoardA`。描き直しは `python3 tools/layout_boardA.py`。ネットリストは `outputs/schematic/boardA_nets.txt`。

## 1. ページ

| ページ（UUID） | 内容 |
| --- | --- |
| `P1`（`e671a2341d4b3a66`）→ 名前は POWER にする | U3 LTC2954-1（電源 ON/OFF）、U4 TPS70933（常時オン 3.3 V）、U5 TPS62933（MCU 用 3.3 V） |
| `P2`（`a9ace616ca30334c`）→ 名前は LED_IO にする | U6 TPS566238P（LED 用 3.3 V）、プルアップ、mother-ring 接続、基板B 接続 |

ページ名の変更（`modifySchematicPageName`）は、BoardA では API で反映されなかった。EasyEDA の画面で変える。

## 2. 主要部品（2026-10-08 決定）

| 記号 | 型番 | LCSC | 役割 |
| --- | --- | --- | --- |
| U3 | LTC2954-1（ADI、TSOT-23-8） | C683782 | 電源 ON/OFF。`EN` はハイアクティブのオープンドレイン |
| U4 | TPS70933（TI、SOT-23-5） | C89347 | 常時オン 3.3 V。入力最大 30 V、待機電流 1.4 µA、150 mA |
| U5 | TPS62933（TI、SOT-583-8） | C3200405 | MCU 用 3.3 V、3 A、入力 3.8〜30 V、OFF 中 2 µA |
| U6 | TPS566238P（TI、VQFN-HR-9 1.5 × 2 mm） | C2876603 | LED 用 3.3 V、6 A、入力 3〜18 V。P 付きは 9 番がパワーグッド（ソフトスタートは内部固定） |

不採用：TPS56637（$1.67、3 × 3 mm）、P なしの TPS566238（在庫 930 個）、TPS563201（OFF 中の電流が大きい）、TPS62162（1 A）。

## 3. 回路の要点

### 3.1 電源 ON/OFF（U3 LTC2954-1）

| ピン | 接続 |
| --- | --- |
| VIN | `VSYS`（0.1 µF） |
| PB# | `HALL_WAKE` → 5.1 kΩ → `PB_F`、`PB_F`–GND に 0.1 µF（長い配線のため。LTC2954 データシートの推奨） |
| ONT | 0.33 µF（C159798）→ ON 長押し 約 2.15 s |
| PDT | 1 µF + 0.22 µF（並列 1.22 µF）→ 強制 OFF 約 7.9 s |
| KILL# | `PWR_KILL`。`3V3_MCU` へ 100 kΩ でプルアップ（ESP32 のリセット中も電源を保つ） |
| EN | `MCU_EN` → U5 の `EN` に直結 |
| INT# | `PWR_INT` → テストパッド（任意） |

**U5 の `EN` を `VSYS` にプルアップしてはいけない。** TPS62933 の `EN` の絶対最大は 6 V。U5 の `EN` には内部プルアップ（0.7 µA）があり、開放で ON になる。LTC2954-1 の `EN` が L に引くと OFF。OFF 中の電流は 0.7 µA だけ。

### 3.2 常時オン 3.3 V（U4 TPS70933）

`IN` と `EN` を `VSYS` に。入力 1 µF、出力 2.2 µF。`3V3_AON` は北極の DRV5032FC だけに給電する（mother-ring の J_ML 6 番）。

### 3.3 MCU 用 3.3 V（U5 TPS62933）

- `RT` を GND：1.2 MHz
- 出力 = 0.8 V × (1 + 31.6 kΩ / 10 kΩ) = 3.33 V
- インダクタ 2.2 µH（SWPA4030S2R2NT、C279948、4 × 4 mm）。TI の推奨（1.2 MHz で 2.2 µH、実効 30 µF）
- 出力 22 µF × 2（C45783、0805 10 V）、入力 10 µF + 0.1 µF、ソフトスタート 10 nF（6.8 nF 以上が必須）、ブートストラップ 0.1 µF

### 3.4 LED 用 3.3 V（U6 TPS566238P）

- 出力 = 0.6 V × (1 + 93.1 kΩ / 20 kΩ) = **3.39 V**。WS2812C-2020-V6 の下限 3.3 V に余裕を持たせた。実測後に 93.1 kΩ を変えて調整する（3.46 V にするなら 95.3 kΩ）
- フィードフォワード 47 pF（TI の推奨 10〜100 pF）
- インダクタ 2.2 µH（SPM6530T-2R2M、C76855、7.1 × 6.5 mm）。TI の推奨は 1.5〜4.7 µH
- 出力 22 µF × 4、入力 10 µF × 3 + 0.1 µF、`VCC` 1 µF、ブートストラップ 0.1 µF
- `EN` = `LED_EN`、GND へ 100 kΩ（MCU が起動するまで OFF）
- `PG` = `L_PG` → テストパッド（任意）
- 電流：電池電流 2 A 制限のため、LED は最大 約 3.6 A（`interfaces.md` FW-2）

### 3.5 プルアップ（`3V3_MCU`、基板A に集約）

| ネット | 値 |
| --- | --- |
| `I2C_SDA`、`I2C_SCL` | 4.7 kΩ |
| `CHG_INT`（BQ25792 の INT） | 10 kΩ |
| `PWR_KILL` | 100 kΩ（POWER ページ） |

`3V3_MCU` は電源 OFF 中に 0 V なので、基板B の IC へプルアップを通じて逆給電しない。

### 3.6 コネクタ

| 記号 | ピン 1〜6 |
| --- | --- |
| J_ML（mother-ring 左） | `3V3_LED` / `GND` / `3V3_MCU` / `I2C_SDA` / `I2C_SCL` / `3V3_AON` |
| J_MR（mother-ring 右） | `3V3_LED` / `GND` / `GND` / `HALL_WAKE` / `PWR_KILL` / `LED_EN` |
| J_BA1（基板B 電源） | `VSYS` × 3 / `GND` × 3 |
| J_BA2（基板B 信号） | `I2C_SDA` / `GND` / `I2C_SCL` / `CHG_INT` / NC / `GND` |

`interfaces.md` の `3V3_LED_L` / `3V3_LED_R` は `3V3_LED`、`GND_L` / `GND_R` / `GND_SYS` は `GND` として 1 つのネットにした。

## 4. 確認・未決事項

1. **L3（SPM6530T-2R2M）の飽和電流**：U6 の過電流のしきい値（谷電流）は 6.1〜8.9 A。インダクタの飽和電流が、ピーク電流（約 9 A 以上）を上回るか、TDK のデータシートで確認する
2. **基板A↔B のピン 1 の向き**：基板A のピンヘッダは下向きに基板B の穴へ刺さる。PCB で、基板A の J_BA1 / J_BA2 のピン 1 と、基板B の J_AB1 / J_AB2 のピン 1 が重なるように配置する（片方は裏から見た配置になる）
3. テストパッド（`PWR_INT`、`L_PG`、主要な電源）を PCB で追加する
4. `VSYS` の入口（J_BA1 の近く）に、まとめのコンデンサを置くか（U3〜U6 の入力コンデンサで足りるかを PCB で判断）
5. mother-ring と MCU 基板側の回路は、KiCad から移植するときに、このピン配置に合わせて改版する

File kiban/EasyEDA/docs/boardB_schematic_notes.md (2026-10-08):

# 基板B 回路図ノート（充電・保護）

2026-10-08 時点。基板Bの回路図を EasyEDA で描くために、TI の一次資料から読み取った値をまとめる。
**電池の安全に関わる回路なので、描く前に §4 の決定が必要。値は TI の評価ボードの部品表を出発点にし、ゲート2のレビューで確認する。**

## 1. EasyEDA の状態

- プロジェクト `power-2s-xiao`（ユーザーが作成、2026-10-08）
- ボード：`BoardB`（回路図 `5ebeb43e1231a20b`、PCB `9fbb35c6f73cc004`）と `BoardA`（回路図 `5e620f3e36bb6729`、ページ p1 `e671a2341d4b3a66`、PCB `44537a4eae4b3566`）
- BoardB の回路図は 2 ページ：
  - `CHARGER`（`94446b1a98d03840`）：充電入力、BQ25792、出力、電力段、設定
  - `PROTECTION`（`3c04743d7cb514cc`）：主電流路、BQ28Z620、ゲート駆動、シャント、I2C、基板A 接続
- 描き直しは `python3 tools/layout_boardB.py`（両ページを消してから描く）。ネットリストは `outputs/schematic/`

### 描き方と、API の制約（2026-10-08 実測）

- 接続はすべて「ネット名を付けた線」。同じ名前の線は、ページをまたいでもつながる。ネット名は線の端に**文字**で表示している
- **API で作った GND 記号・電源記号（`createNetFlag`）とネットポート（`createNetPort`）は使えない。** 1 つでもあると `getNetlistFile()` が null を返し、DRC に致命的エラーが出る。同じ名前のネットポートが 2 つあるだけでも失敗した
- 部品を置く処理の途中で EasyEDA のタブが切り替わると、別のページに置かれる。道具は、部品・線ごとにページを確認する。**描いている間は EasyEDA のタブを切り替えない**
- `getNetlistFile()` は、開いているページが属するボードの回路図全体を返す
- 部品の回転は `create()` に渡した値と違って返ることがあるので、ピンの位置は必ず読み直す。ピンの回転（180 = 左、0 = 右、90 = 上、270 = 下）が、ピンの外向きの方向を表す

## 2. 充電部（BQ25792）

TI の BQ25798 データシート Figure 8-1（単一入力、シップ FET なし）より。BQ25792 は同じピン配置。

| 項目 | 値 |
| --- | --- |
| 入力の接続 | `VAC1` と `VAC2` を `VBUS` につなぐ。`ACDRV1` と `ACDRV2` は GND。外付けの入力 FET なし |
| インダクタ L1 | 1 µH（1.5 MHz 用、TI 例 SPM6530T-1R0M120）。飽和電流 2 A 以上、実際には入力電流の上限（3 A 以上）より大きいもの |
| `PROG` | 6.04 kΩ → GND（2 セル、1.5 MHz）。750 kHz なら 8.2 kΩ と 2.2 µH |
| `ILIM_HIZ` | `REGN` から 127 kΩ、GND へ 100 kΩ の分圧（TI 例）。入力電流の上限は `V = 1 V + 0.8 Ω × I`。使う 12 V アダプタに合わせて決める |
| `VBUS` | 10 µF × 2 + 0.1 µF（25 V 以上） |
| `PMID` | 10 µF × 3 + 0.1 µF（25 V 以上） |
| `SYS` | 10 µF × 5 + 0.1 µF |
| `BAT` | 10 µF × 2 |
| `BTST1` / `BTST2` | 各 47 nF（`SW1` / `SW2` との間） |
| `REGN` | 4.7 µF |
| `STAT` | 2.2 kΩ で `REGN` へ（TI 例）。LED 表示にするかは別途 |
| `TS` | `REGN` から 5.24 kΩ、GND へ 30.31 kΩ の分圧に 10 kΩ NTC（103AT-2）を並列。標準品に近い値（5.23 kΩ / 30.1 kΩ）で代用できるか確認 |
| `SDRV` | 1 nF → GND（シップ FET なし） |
| `QON#` | 使わない場合の処理をデータシートで確認 |
| `CE#`、`INT#` | `CE#` は GND（充電有効）か MCU 制御。`INT#` は基板A へ（`CHG_INT`） |

I²C のプルアップは、MCU 側（基板A）に置くか、基板B に置くかを決める（`interfaces.md` §3）。

### 2.1 充電入力（2026-10-08）

| 部品 | 内容 |
| --- | --- |
| J_CHG | 導線をはんだ付けする 2 穴。ピンヘッダ 2P（C492401）のフットプリントを使い、部品は載せない（BOM から除外）。1 = `VBUS`、2 = `GND`。線の先に PH 2P コネクタを付ける |
| D_TVS | SMF15A（BLUE ROCKET、C2900732、SOD-123FL、在庫 7,040 個） |

TVS の検討：

- 12 V アダプタの最大電圧（約 12.6 V）より遮断電圧が高く、BQ25792 の `VBUS` 絶対最大 30 V より低い電圧で抑えるものを選んだ
- SMF15A：遮断電圧 15 V、降伏電圧 16.7 V 以上、クランプ電圧 24.4 V（8.2 A）、200 W
- マグネット端子を抜き差しすると、配線のインダクタンスと入力コンデンサで電圧が跳ねる。TI は、15 V を超えるアダプタを抜き差しする場合に、入力の 2 Ω + 2.2 µF の RC を推奨している（BQ25798 データシート Figure 8-1 の注 1）。12 V では必須ではないが、試作で `VBUS` の跳ね上がりを測って判断する
- **未確認：** シンボルのピン名が `1` / `2` で、どちらがカソードかを名前で確認できていない。1 番をカソード（`VBUS` 側）として接続している。フットプリントの極性マークで確認する
- 逆接続の保護は入れていない。PH コネクタは向きが決まっているので、逆に挿さらない前提

## 3. 保護部（BQ28Z620）

TI の BQ28Z620 データシート Figure 10-1（2 直列）と、BQ28Z620EVM（SLUUCQ5）の部品表より。

構成：

- 保護 FET 2 個（充電用と放電用）を、セルのプラス側（高い側）に、向かい合わせに直列で入れる。ゲートは `CHG`（9 番）と `DSG`（7 番）から駆動する。
- 電流検出のシャントは、セルのマイナス側（低い側、`PACK−` との間）に入れる。`SRP` と `SRN` に各 100 Ω + 0.1 µF のフィルタ。
- `VC2`：スタック全体（BAT）の測定と電源。`VC1`：セル 1 とセル 2 の中点。各 100 Ω + 0.1 µF。`PBI` は 2.2 µF → GND。
- `PACK`（8 番）：パック電圧の測定。10 Ω を通して `PACK+` へ。
- `TS1`（4 番）：10 kΩ NTC（103AT-2）。
- `SCL`、`SDA`：100 Ω の直列抵抗と、5.6 V ツェナー（MM3Z5V6C）で保護。

EVM の部品表（抜粋）：

| 部品 | 値・型番 |
| --- | --- |
| 保護 FET（Q2、Q3） | CSD16412Q5A（Nch、30 V、SON 5×6） |
| シャント（R24） | 1 mΩ、1206（CSNL1206FT1L00）。データシートの推奨範囲は 1〜3 mΩ |
| NTC（RT1） | 10 kΩ（103AT-2） |
| 二次保護 IC（U1） | BQ294502DRV（過電圧の最大値 4.35 V） |
| ヒューズ溶断回路 | Q1（SI1416EDH）と Q4（2N7002K）、10 MΩ × 2 |
| ツェナー | MM3Z5V6C × 2（`SCL`、`SDA` 用） |
| 抵抗 | 100 Ω × 8、5.1 kΩ × 4、10 MΩ × 2 ほか |

EVM の電流定格は、BQ28Z620 の設計例で 6 A（過電流の閾値）。本設計の電池電流は最大約 3 A なので、シャントは 2 mΩ 前後でも足りる。値は、測定の精度と損失（3 A で 3 mΩ なら 27 mW）で決める。

## 4. 電池（実物）と保護の構成

電池は 104040（10 × 40 × 40 mm）、3.7 V 2000 mAh のポリマーセル（写真、2026-10-08）。

販売ページの記載（ユーザー提供、2026-10-08）：10 個入りセット、3.7 V 2000 mAh、10 × 40 × 40 mm、1 個 35 g。
**最大放電電流、保護基板（PCM）の過電流しきい値、充電電流の記載はない。** PCM の有無も記載にはなく、写真で確認できるだけ。仕様は、販売元への問い合わせか実測で確認する。

- **セルに保護基板（PCM）が付いている。** 側面に保護 IC とデュアル FET があり、リード線は赤（＋）と黒（−）の 2 本。
- PCM はセルのマイナス側に入っている。2 セルを直列にすると、保護が 3 層になる（セルの PCM、BQ28Z620 の保護 FET、必要なら二次保護）。

PCM があることで生じる問題：

1. **PCM の過電流保護のしきい値が不明。** 同種のセルでは 3 A 前後のことが多く、本設計の電池電流（全負荷で最大約 3 A）とほぼ同じ。全負荷で PCM が働いて、突然電源が落ちる恐れがある。
2. **2000 mAh のセルで 3 A は 1.5C。** 多くのセルの連続放電定格（1C 前後）を超える。セルの仕様書で、最大連続放電電流を確認する。
3. 2 本の PCM が直列に入るため、どちらかの PCM が働くと、電池全体が切れる。セル間のバランスは PCM では取れない。
4. PCM の FET の電圧降下で、電池電圧が約 0.1 V ずつ下がる（3 A で、1 セルあたり）。

対策（案）：

- 電池電流を **2 A 以下に制限する（ユーザー決定、2026-10-08）**。電池電圧ごとの LED 電流の目安は `interfaces.md` FW-2。
- セルの仕様書で、PCM の過電流しきい値と最大放電電流を確認する。確認できなければ、電流制限を設けて実測する。
- BQ28Z620 は、残量計とセルバランス、パック全体の保護に使う。PCM は、各セルの最後の保護として残す。

## 5. 保護 FET の選定

BQ28Z620 の標準回路（データシート Figure 10-1）の FET は、**共通ドレインの向かい合わせ直列**：

- 放電用（`DSG` で駆動）はパック側、充電用（`CHG` で駆動）は電池側に置く
- 2 つの FET のドレインを中央で共通にする。各ゲートは 5.1 kΩ を通して `DSG` / `CHG` へ。ゲートとソースの間に 10 MΩ

必要な条件：

| 項目 | 条件 | 理由 |
| --- | --- | --- |
| 構成 | 共通ドレインのデュアル N-ch（ゲートは別々） | 上記 |
| ゲート電圧の上限 | **±12 V 以上** | BQ28Z620 のゲート駆動は、初期設定（PMPDRV = 0）で約 9.5 V（最大 10.25 V）。5.75 V の設定もある |
| 耐圧 | 20 V 以上 | パック電圧は最大 8.4 V |
| 電流 | 連続 3 A 以上 | 電池電流（2 A 以下に制限、設計上は 3 A まで） |
| オン抵抗 | 1 個あたり 25 mΩ 以下（4.5 V） | 2 個で約 40〜50 mΩ。3 A で約 0.13 V、0.4 W |

注意：5.75 V に下げるビットの記述が、データシートの表（PMPDRV = 1 で 5.75 V）と本文（PMPDRV = 0 で 5.75 V）で食い違っている。ファームウェアで設定するときは、TRM で確認する。

候補（EasyEDA のライブラリで確認、LCSC）：

| 型番 | LCSC | パッケージ | Vds / Vgs / Id | Rds(on) | 在庫（2026-10-08） | 判定 |
| --- | --- | --- | --- | --- | --- | --- |
| **FS8205A（FUXINSEMI）** | **C908265** | SOT-23-6 | 20 V / ±12 V / 6 A | 18 mΩ（4.5 V、6 A）、最大 25 mΩ | 19,060 個、$0.058（10 個〜） | **採用候補。** 共通ドレイン（G1、D1/D2、G2、S1、S2）。ゲート ±12 V は、9.5 V 駆動に対して余裕 1.75 V。最大消費 1.5 W |
| FS8205A（TECH PUBLIC） | C2830320 | SOT-23-6 | 20 V / ±10 V / 6 A | 31.5 mΩ（2.5 V） | 33,710 個 | 不可：ゲート ±10 V は 9.5〜10.25 V 駆動に足りない |
| AO8810（AOS） | C21426 | TSSOP-8 | 20 V / ±8 V / 7 A | 20 mΩ（4.5 V） | 12,175 個 | 不可：ゲート ±8 V（5.75 V 駆動にしない限り使えない） |
| CJS2013 | C504157 | TSSOP-8 | 20 V / ±10 V / 6 A | 10.5 mΩ（4.5 V） | なし | 不可：在庫なし、ゲート ±10 V |
| FS8205A（Fortune） | C16052 | TSSOP-8 | 20 V / ±12 V / 9 A | 25 mΩ（4.5 V） | なし | 在庫なし |
| DMT3020LSD-13 | C268033 | SO-8 | 30 V / — / 16 A | 32 mΩ（4.5 V） | なし | 在庫なし |
| CSD16412Q5A（TI、評価ボード） | — | SON 5×6 | 25 V | — | 未確認 | 3 A には大きすぎる |

熱：SOT-23-6 の FS8205A は、3 A でも 1 個あたり約 0.2 W（2 個で約 0.4 W）。PCB の銅箔で逃がす。基板Bの裏面は部品禁止なので、部品面側に置き、LiPo の中央の真上を避ける。
より余裕が欲しければ、Vgs ±12 V 以上で TSSOP-8 の共通ドレイン品を、ほかのメーカーから探す。

## 6. ヒューズ

**入れる空間はある。** 1206 のヒューズは、本体が 3.2 × 1.6 mm、ランドを含めても約 4.4 × 1.8 mm。基板B（40 mm 角、隅を面取りして約 1,470 mm²）の面積に対して、ごくわずか。

置く場所：電池の＋（`B+`）から保護 FET へ向かう経路に直列。電池コネクタ（J_CELL2）の近く。
化学ヒューズ（BQ294502 による溶断）は入れない。セルの PCM と BQ28Z620 の保護がすでにあり、部品も増えるため。

### 6.1 使い切り型（不採用）

| 型番 | LCSC | 定格 | 在庫 | 判定 |
| --- | --- | --- | --- | --- |
| SF-1206S500-2（Bourns） | C913282 | 5 A、32 V DC、遅断型、遮断容量 50 A | 5,373 個、$0.28 | 不採用（リセッタブルを選んだため） |
| SF-1206S400-2（Bourns） | C1972812 | 4 A、32 V DC、遅断型 | 4,345 個、$0.27 | 4 A は、周囲温度の定格低減で 3 A がぎりぎり |

### 6.2 リセッタブル型（PPTC）の評価（2026-10-08、LCSC の在庫とデータシート）

電池電流は 2 A 以下に制限する（§4）。PPTC の保持電流は温度で下がるため、**閉じた球体の中の高温（60 °C 前後）でも 2 A を流せるか**が条件。

| 型番 | LCSC | サイズ | 保持 / 動作 / 耐圧 | 抵抗 | 在庫 | 保持電流 40 / 60 / 85 °C | 判定 |
| --- | --- | --- | --- | --- | --- | --- | --- |
| **SMD2920P500TF/16（PTTC）** | **C108585** | 2920（8.0 × 5.4 × 1.6 mm） | 5 A / 10 A / 16 V | 5 mΩ〜25 mΩ（動作後） | 4,380 個、$0.32 | 4.15 / 3.30 / 2.25 A | **成立する唯一の候補。** 85 °C でも 2 A を流せる |
| SMD1812P300SLR/24（PTTC） | C2892380 | 1812（4.7 × 3.4 mm） | 3 A / 6 A / 24 V | 1〜30 mΩ | 46,390 個、$0.39 | 2.45 / 1.85 / 1.05 A | 不可：60 °C で 1.85 A となり、2 A で切れる |
| SMD2920P300TF/16（RUILON） | C167318 | 2920 | 3 A / 6 A / 16 V | 12〜48 mΩ | 230 個 | 2.52 / 1.99 / 1.34 A | 不可：60 °C で 2 A を割る。在庫も少ない |
| SMD2920P400TF（PTTC） | C495360 | 2920 | 4 A / 8 A / 15 V | 10〜40 mΩ | 25 個 | — | 不可：在庫が少ない |
| JK-NSMD300L-12V（金科） | C516068 | 1206 | 3 A / 6 A / 12 V | 4〜20 mΩ | 10,080 個、$0.10 | 未確認（1206 は定格低下が大きい） | 保留：データシートで温度特性を確認できていない |
| MF-MSMF260-2（Bourns）、SMD1812P300TF（RUILON） | C89651、C21004 | 1812 | 耐圧 6 V、8 V | — | あり | — | 不可：耐圧がパック電圧 8.4 V より低い |

### 6.3 使い切り型とリセッタブル型の比較

| 項目 | 使い切り（SF-1206S500-2） | リセッタブル（SMD2920P500TF/16） |
| --- | --- | --- |
| 面積（本体） | 3.2 × 1.6 mm | 8.0 × 5.4 mm（約 5 倍） |
| 動作後 | 切れたまま。交換が必要 | 冷えると復帰する |
| 故障が残っているとき | 電流を完全に止める | 高抵抗のまま、約 2 W を消費し続ける（動作後の電力 Pd）。8.4 V では約 0.24 A が流れ続け、**熱が LiPo の近くで続く** |
| 動作の速さ | 速い | 遅い（20 A で最大 5 秒、5〜10 A では数十秒以上） |
| 通常動作での電圧降下（2 A） | — | 10〜50 mV、0.02〜0.1 W |
| 球体を開けずに復帰できるか | できない | できる |

どちらも、保護できるのは「5 A を超える異常」だけ。通常の過電流は、セルの PCM と BQ28Z620 の保護 FET が止める。

### 6.4 決定（2026-10-08）

**リセッタブルヒューズ SMD2920P500TF/16（PTTC、LCSC C108585）を使う**（ユーザー決定）。球体を開けずに復帰できることを優先する。

| 項目 | 値 |
| --- | --- |
| 型番 | SMD2920P500TF/16（PTTC、Polytronics） |
| サイズ | 2920（本体 8.0 × 5.4 × 1.6 mm）。ランドを含めて約 10 × 6 mm |
| 定格 | 保持 5 A、動作 10 A、耐圧 16 V、最大電流 40 A |
| 抵抗 | 初期 5 mΩ、動作後 25 mΩ（最大） |
| 動作後の電力 | 2 W（23 °C） |
| 保持電流の温度特性 | 40 °C：4.15 A、50 °C：3.75 A、60 °C：3.30 A、70 °C：2.90 A、85 °C：2.25 A |
| 在庫 | 4,380 個、$0.32（2026-10-08） |

設計上の注意：

- **動作後に 2 W を消費し続ける。** 故障が残っている間、約 0.24 A（8.4 V）が流れ続け、熱を出す。LiPo の近くに置かない。電池コネクタの近くで、セルから離れた基板の端に置き、周囲に銅箔の逃げと、部品の空き（約 2 mm）を設ける。
- 通常動作の電圧降下は、2 A で 10〜50 mV（0.02〜0.1 W）。`B+` 側に直列に入れる（電池の＋ → ヒューズ → 保護 FET）。
- 5 A 保持なので、保護できるのは 5 A を大きく超える異常だけ。通常の過電流は、セルの PCM と BQ28Z620 の保護 FET が止める。
- 高温でも 2 A を流せる（85 °C で 2.25 A）。これが、3 A 保持品を使わない理由。

## 7. 基板Bの外形

**隅を面取りした 40 mm 角にする**（ユーザー決定、2026-10-08）。A↔B 間隔 7 mm で、コアの内殻に当たらない大きさ（`tools/fit_check.py`）：

| 面取り | すき間 | 面積 |
| ---: | ---: | ---: |
| 7 mm | 0.6 mm | 94% |
| **8 mm** | **1.3 mm** | **92%** |
| 9 mm | 1.8 mm | 90% |
| 10 mm | 2.3 mm | 88% |

8 mm を初期値にする。コアの内殻を再設計するなら、面取りは小さくできる。

## 8. まだ決めること

1. PCM の過電流しきい値とセルの最大放電電流（セルの仕様書、または実測）
3. FS8205A（SOT-23-6）の熱の確認。気になる場合は TSSOP-8 の代替を探す
4. 充電 IC の `BAT` を、保護 FET の**パック側**（`PACK+`）につなぐ構成でよいか
5. 基板Bの `VSYS` の出力は、充電 IC の `SYS` から出す

## 9. 描く順序（案）

1. 充電部（BQ25792）：§2 の値で。部品の LCSC 番号を決めてから配置する。
2. 保護部（BQ28Z620、FS8205A、ヒューズ、シャント）：§5、§6。
3. 電池コネクタ（XH 2P × 2）、基板A との接続（ピンヘッダ 1×6 × 2）、テストポイント。

## 10. 回路図のレビュー観点（ゲート2）

EasyEDA で BoardB の回路図を開き、次の順に確認する。

### CHARGER ページ

1. **充電入力**：J_CHG の 1 番が `VBUS`、2 番が `GND`。TVS のカソードが `VBUS` 側（§2.1 の未確認事項）
2. **BQ25792 のピン**：`VAC1` / `VAC2` が `VBUS`、`ACDRV1` / `ACDRV2` が `GND`（入力 FET なし）。`D+` / `D−` / `QON` は未接続
3. **設定**：`PROG` 6.04 kΩ（2S、1.5 MHz）、`ILIM_HIZ` の分圧（127 kΩ / 100 kΩ = 入力 約 1.5 A）、`TS` の分圧と NTC、`CE` のプルダウン
4. **電力段**：L1 が `SW1` と `SW2` の間、ブートストラップ 47 nF が `BTST1`–`SW1`、`BTST2`–`SW2`
5. **出力**：`SYS` → `VSYS`（コンデンサ 10 µF × 5）、`BAT` → `PACK_P`、`BATP` が 100 Ω を通して `PACK_P`

### PROTECTION ページ（電池の安全に関わる）

1. **主電流路**：セル2 の＋（`BAT_TOP`）→ ヒューズ F1 → `BAT_F` → 保護 FET Q1 → `PACK_P`。ヒューズが FET より電池側にあること
2. **保護 FET の向き**：FET1（S1、G1）が電池側で `CHG` 駆動、FET2（S2、G2）がパック側で `DSG` 駆動。ドレインは共通
3. **ゲート**：各ゲートに 5.1 kΩ（`CHG` / `DSG` から）と、10 MΩ（それぞれのソースへ）
4. **グラウンド 2 系統**：`GND`（パック−）と `BAT_N`（セル−）の間に RSNS（2 mΩ）。`SRN` は `GND` 側、`SRP` は `BAT_N` 側の端から 100 Ω
5. **セル電圧**：`VC2` は 5.1 Ω で `BAT_TOP`（ヒューズの電池側）、`VC1` は 100 Ω で `BAT_MID`
6. **電池コネクタ**：J_CELL1 = `BAT_N` / `BAT_MID`、J_CELL2 = `BAT_MID` / `BAT_TOP`。セルの向きを間違えないこと
7. **基板A 接続**：J_AB1 = `VSYS` × 3 / `GND` × 3、J_AB2 = `I2C_SDA` / `GND` / `I2C_SCL` / `CHG_INT` / 予備 / `GND`

### 比べる資料

- BQ28Z620 データシート Figure 10-1（2 直列の標準回路）
- BQ25798 データシート Figure 8-1（単一入力、シップ FET なし）
- 本ノート §2〜§6

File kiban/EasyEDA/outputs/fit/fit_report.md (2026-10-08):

# 電池・基板の配置検討（fit_check.py の出力）

重ね順（北から）：MCU – セル – mother-ring – セル – 基板A – 基板B。
mother-ring は z = 0（板厚 1.6 mm）、南（LiPo 側）は −z。
mother-ring・MCU 基板と基板A の面間距離 11.0 mm（ソケット 8.5 + ヘッダ絶縁体 2.5）、基板A↔B 7.0 mm、基板厚 1.6 mm、セル 40×40×10 mm。

STL は `docs/cad/` の core-north-03_fixed / core-south-03_fixed。断面に現れる塊を一つずつ障害物として扱い、
基板やセルの輪郭が塊に当たるか、最小のすき間はいくつかを調べる。「干渉」は当たること。

## 基板A（実機の外形：張り出し x = ±25、y = ±9.25）

高さ z = -13.4〜-11.8 mm。外形を軸のまわりに回したときのすき間：

| 回転 | 張り出しの向き | すき間 |
| ---: | --- | --- |
| 0° | ±x 方向 | **干渉** |
| 15° |  | **干渉** |
| 30° |  | 0.4 mm |
| 45° |  | **干渉** |
| 60° |  | 0.4 mm |
| 75° |  | 2.1 mm |
| 90° | ±y 方向 | 2.3 mm |
| 105° |  | 2.1 mm |
| 120° |  | 0.4 mm |
| 135° |  | **干渉** |
| 150° |  | 0.4 mm |
| 165° |  | **干渉** |

張り出しの先端 x（回転 90°、幅 y = ±8.12 mm）の限界：

| 先端 x | すき間 |
| ---: | --- |
| 24.63 mm | 2.3 mm |
| 26 mm | 2.3 mm |
| 27 mm | 2.0 mm |
| 28 mm | 1.0 mm |
| 29 mm | 0.0 mm |
| 30 mm | **干渉** |

## 基板B

基板A↔B の間隔ごとに、基板B（本体 40 mm 角、角 R3）が入るかを調べた。

| A↔B 間隔 | 基板Bの高さ z | 40 mm 角 | 隅を 7 mm 面取り | 隅を 9 mm 面取り | 入る最大の一辺 |
| ---: | --- | --- | --- | --- | --- |
| 3 mm | -18.0〜-16.4 | 0.4 mm | 2.9 mm | 4.2 mm | 40.6 mm |
| 4 mm | -19.0〜-17.4 | 0.2 mm | 2.9 mm | 4.2 mm | 40.3 mm |
| 5 mm | -20.0〜-18.4 | **干渉** | 2.4 mm | 3.6 mm | 39.0 mm |
| 6 mm | -21.0〜-19.4 | **干渉** | 1.7 mm | 2.7 mm | 37.9 mm |
| 7 mm | -22.0〜-20.4 | **干渉** | 0.6 mm | 1.8 mm | 37.0 mm |
| 8 mm | -23.0〜-21.4 | **干渉** | 0.1 mm | 0.8 mm | 35.3 mm |

間隔 7 mm で 40 mm 角が当たる場所：z = -22.0〜-20.5、軸からの半径 24.6〜27.1 mm（四隅の 45° 方向）。

## セル（40×40×10 mm）

| 場所 | 高さ z | 一辺 40 mm | 一辺 39.5 mm | 一辺 39 mm |
| --- | --- | --- | --- | --- |
| 北：MCU 基板と mother-ring の間 | 1.3〜11.3 | **干渉** | 0.2 mm | 0.5 mm |
| 南：mother-ring と基板A の間 | -11.3〜-1.3 | 0.5 mm | 0.7 mm | 1.0 mm |

北のセル（40 mm）が当たる場所：z = 3.3〜10.3、|x| = 20.0〜22.9、|y| = 0.4〜10.0（x = ±20 mm の側面にある塊）。

## 断面図

緑：基板A（張り出しを ±y に向けた実機外形）・基板B（隅 7 mm 面取り）、青：セル。

- [section_z+6.svg](section_z+6.svg)
- [section_z-6.svg](section_z-6.svg)
- [section_z-13.svg](section_z-13.svg)
- [section_z-21.svg](section_z-21.svg)

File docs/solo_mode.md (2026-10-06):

> **XIAO ESP32S3 版の注記**: 本書は M5AtomS3R 版から引き継いだ。LCD・QR 表示・本体ボタン・M5 IMU に関する
> 記述と実機検証の記録 (§6 QR、§9 の AtomS3R 実測) は AtomS3R 版の経緯であり、本リポジトリでは該当機能を
> 削除している。XIAO 版の方針と計画は `docs/xiao_bringup.md`。

# solo 設計ノート

`isolation-sphere-solo` の設計判断、仕様、運用手順、実機チェック項目をまとめる。
使い方の概要は [../README.md](../README.md)、実装依頼時の仕様は [handoff.md](handoff.md) を参照。

---

## 1. 派生元の調査結果 (実装前に実コードで確認した事実)

本リポジトリは [sastles-com/sastle-isolation-sphere](https://github.com/sastles-com/sastle-isolation-sphere)
の `core/` (ESP32-S3 ファームウェア) を solo 専用に切り出したもの。切り出しの判断根拠として、
派生元のコードから確認した事実を残す (ハンドオフ資料は最新コードを読めていない前提で書かれていた)。

| 項目 | 事実 |
| --- | --- |
| ビルド | PlatformIO + Arduino framework、`board = m5stack-atoms3` (flash 8MB, PSRAM OPI) |
| パーティション | nvs / otadata / phy / ota_0 1.5MB / ota_1 1.5MB / spiffs(LittleFS) 3MB。末尾 約1.94MB が未使用 |
| **ファームサイズ** | **派生元をそのままビルドすると 1,723,509 bytes (1.5MB スロットの 109.6%) で収まらない**。release + `CORE_DEBUG_LEVEL=1` でも 1,594,145 bytes (101.4%)。この超過は solo 化前から存在していた |
| フレーム供給 | server → UDP チャンク (16B ヘッダ, ≤1400B) → 再構成 → TJpg_Decoder → RGB565 → トリプルバッファ |
| デコーダ | `bodmer/TJpg_Decoder` (Baseline JPEG のみ)、出力 RGB565、`setSwapBytes(false)`。デコードは Core0 |
| 描画 | FastLED RMT 並列出力、レンダタスクが Core1 prio2 で連続駆動 (~50-60Hz)。毎パス最新 IMU で再マッピングし、**フレーム到着に依存しない** |
| IMU | 100Hz 更新。`loop()` タスクで取得し、レンダタスクが読む |
| 制御 | MQTT (PubSubClient) を `loop()` で駆動、`CommandHandler` が params/playback/led/system を処理 |
| 設定 | LittleFS `/config.json` を ArduinoJson で読み書き。NVS/Preferences は未使用。**デバイスレベルの「モード」概念は無かった** (LED 出力モード sphere/pixels/off/test のみ) |
| LCD | M5AtomS3R 128×128、M5GFX (LovyanGFX)。LovyanGFX は `qrcode()` を内蔵 |
| デバイス内 HTTP / DNS | **無し**。`esp_http_server` と `DNSServer` は ESP-IDF / arduino-esp32 に同梱 |
| ローカル再生 | **無し**。`data/images/*.jpg` は LittleFS に載っていたがファームは読んでいなかった (1.2MB の無駄) |
| 既存ビルドエラー | `LEDManager.cpp` の `memset(CRGB[],…)` が FastLED 3.10 で曖昧呼び出しになり失敗。XIAO env は `kLedMaxPowerMa` 未定義で失敗 (いずれも本リポジトリで修正済み) |

**切り出しが成立する根拠**: 描画エンジンはフレームの供給元を知らない (トリプルバッファから読むだけ) ため、
「UDP 受信タスク」を「ローカルファイル読み出しタスク」に差し替えるだけで単独再生が成立する。
球面 UV マッピングと IMU 再投影は元々デバイス側で完結していた。

## 2. 採用した設計判断

- **供給元の差し替え**: `ImageManager::submitJpegFrame()` を入口とし、`SoloPlayer` タスクが LittleFS から
  読んだ JPEG を流す。描画・IMU・LED・球面マッピングは派生元のまま無変更。
- **動画形式 = raw MJPEG** (Baseline JPEG の連結、コンテナ無し)。AVI/multipart は受理しない。
  既存デコーダ (TJpg_Decoder) と同じ JPEG をそのまま使えるのが理由。
- **フレーム境界はマーカー追跡で判定** ([../src/JpegScan.h](../src/JpegScan.h))。`0xFFD9` の線形探索だと
  EXIF サムネイル (APP1) 内の EOI を誤検出するため、セグメント長を辿って SOI..EOI を確定させる。
  Arduino 非依存のヘッダオンリー実装にして PC 上で単体テストする。
- **10fps はファームウェア固定** (`kSoloFps`)。ファイル内の fps メタデータは参照しない。
- **締切管理は単調クロック** (`esp_timer_get_time`)。「デコード後に 100ms 待つ」方式ではなく締切を
  管理し、遅れた締切は捨てて次に揃える (処理時間によるドリフトと遅延の蓄積を避ける)。
- **1 フレーム上限 64KiB** (`kSoloMaxFrameBytes`)。ファイル内のサイズ値を無検証でメモリ確保に使わず、
  固定サイズの PSRAM バッファを使う。
- **UI はファームウェア埋め込み** (PROGMEM, 約 6KB)。LittleFS が壊れていても管理 UI を出して
  再アップロードできる。CDN・外部フォントには依存しない。
- **HTTP は ESP-IDF 同梱 `esp_http_server`、DNS は arduino-esp32 同梱 `DNSServer`** — 追加ライブラリ依存なし。
- **接続導線は QR + キャプティブポータル** (§6)。NFC は iOS が NFC 経由の Wi-Fi 参加に対応しないため不採用。
- **パーティション: OTA 2MB×2 + LittleFS 3.94MB** (§5)。OTA は削らず拡張し、派生元から存在した
  「ファームが OTA スロットに収まらない」問題も解消する。
- **アップロードは 一時ファイル → 全件検証 → rename**。容量が足りない場合のみ既存動画を先に削除し
  (UI に明記)、失敗時は「動画なし」で再アップロードできる状態にする。
- **server モード関連は削除** (MQTT 制御, UDP 映像受信, 時刻同期, リモートログ)。切り替えではなく
  削除にしたのは、単独動作に特化した独立リポジトリとして見通しを良くするため。server 構成が必要な
  場合は派生元リポジトリを使う。

### 削除したもの (派生元との差分)

| 削除 | 行数 | 理由 |
| --- | --- | --- |
| `MQTTManager.{h,cpp}`, `MqttTopics.h` | 421 | 外部ブローカーに依存しない。制御は HTTP API |
| `CommandHandler.{h,cpp}` | 602 | MQTT JSON コマンドの受け口。明るさ適用は `main.cpp` と Web API へ移動 |
| `TimeSync.{h,cpp}` | 154 | 複数球体の時刻同期ビーコン (server 前提) |
| `FrameReassembler.h` | 127 | UDP チャンク再構成 |
| `RemoteLog.{h,cpp}` | 161 | MQTT への tee ロガー → `Log.{h,cpp}` (Serial のみ, 14行) に置換 |
| `NetworkManager` の STA/UDP | — | SoftAP 専用に縮小 |
| `ImageManager` の UDP 経路 | — | `submitJpegFrame()` のみを入口に |
| `GestureManager` の MQTT 通知 | — | 検出結果は Serial ログへ |
| `server/` (Python + React), server 向けドキュメント・スクリプト | — | 本リポジトリの対象外 |
| `data/images/` (未参照の JPEG 200枚) | 1.2MB | ファームが読んでいなかった。LittleFS を動画に使う |

結果: ファーム 1,822,841 → **1,734,465 bytes** (約 88KB 減)、RAM 80,588 → **68,484 bytes** (約 12KB 減)、
LittleFS の同梱物 1.35MB → **39KB**。

## 3. アーキテクチャ

| 境界 | 実装 |
| --- | --- |
| ネットワーク | SoftAP (既定 `isolation-sphere` / 192.168.4.1、常時) + 任意の STA (NVS の LAN > config の P2P 網) + キャプティブ DNS |
| 映像入力 | `FramePump` (Core0、1 タスク) が UDP 配信 (`UdpReceiver` → `FrameReassembler`) とローカル `SoloPlayer::tick()` を調停 (`SourceArbiter`) し、`ImageManager::submitJpegFrame()` を呼ぶ唯一の場所。ローカル動画は open 時に **全体を PSRAM に読み込み**、再生中はフラッシュを読まない (§9 カクつき対策) |
| 制御入力 | `SoloWebServer` (esp_http_server) / `CommandHandler` (MQTT) / `SerialConsole` → いずれも `DeviceController` |
| 表示 | `LEDManager` レンダタスク (Core1) + IMU 再マッピング (`SphereMap.h`) |
| ログ | `sastle::Log` = `RemoteLog`: Serial + (server モードでは) MQTT `sphere/<id>/log` (PSRAM 退避 12KB) |
| 更新 | USB (`upload` / `uploadfs`) と OTA (espota: AP 192.168.4.1 / STA の IP) |

§10 に server モード (統合ファーム) の詳細。

### タスク配置

| タスク | Core | prio | stack | 役割 |
| --- | --- | --- | --- | --- |
| `LED_Render` | 1 | 2 | 8192 | IMU 再マッピング + RMT 出力 (~50-60Hz) |
| `imu` | 1 | 3 | 4096 | BNO055 100Hz 読み出し (Log を呼ばない。診断は loop が吐く) |
| `frame_pump` | 0 | 1 | 8192 | UDP キュー待ち (次のローカル締切まで) → 再構成 → デコード / 締切でローカル 1 フレーム。デコードは必ずここ |
| `async_udp` | 0 | — | — | AsyncUDP コールバック: データグラムを PSRAM キューへ (server モードのみ) |
| `httpd` | 0 | 2 | 8192 | Web UI / API / アップロード受信 (FS 書き込み) |
| `loopTask` | 1 | 1 | 8192 | OTA、STA 再接続、MQTT loop、ログ flush、DNS、設定保存/再起動、ジェスチャー、LCD、周期ログ・publish |
| WiFi/lwIP | 0 | 高 | — | SDK |

アップロード中 (FS 書き込み中) は再生を止める。フラッシュ書き込みはキャッシュ無効化で両コアに
影響するため、描画のちらつきが出る可能性がある (再生停止中なので実害は小さい)。

### 状態遷移 (SoloPlayer)

```
起動 ──有効な動画あり──▶ playing ──pause──▶ paused (表示は現在のフレームのまま)
  │                       │  ▲  ▲            │
  │                     stop │  └────play─────┘ (続きから)
  │                       ▼  │
  │                    stopped (LED 消灯。play で続きから)
  └─動画なし──▶ no_video (消灯)
  └─破損/解像度違い─▶ error (消灯)
アップロード開始 ─▶ uploading ─成功─▶ playing (先頭から)
                            └─失敗─▶ 旧動画があれば playing / 無ければ no_video
```

## 4. 動画形式と事前変換

受理条件 (アップロード時と起動時の両方で全フレーム検査):

- raw MJPEG: `FFD8 … FFD9` の Baseline JPEG (SOF0) を区切りなしで連結
- 全フレーム 320×160 (`config.json` の `image.width/height`)。他解像度は `resolution mismatch`
- progressive (SOF2) は `not a baseline JPEG` で拒否
- 1 フレーム ≤ 65536 bytes
- 途中で切れたファイル・末尾のゴミ・不正なマーカー構造は拒否 (部分ファイルは再生しない)

```bash
# 中央トリミングで 2:1 に合わせる (既定)。-q は 2(高画質)〜31(低画質)
tools/make_solo_video.sh input.mp4 video.mjpg -q 6
# 黒帯で収める / 先頭 30 秒だけ
tools/make_solo_video.sh input.mov video.mjpg --fit pad -t 30
```

MP4/MOV/HEVC を ESP32 上で変換する機能は無い (ESP32 では H.264 をデコードできない)。

### ブラウザ変換 (`docs/convert.html` → ファームに埋め込み `/convert`)

iPhone のカメラ動画を PC を介さずに変換するための単体ページ。**変換はすべて閲覧端末のブラウザ内**で
行われ、球体側の負荷はゼロ (ページを配信するだけ)。

```
Safari                                         ESP32
 <video> で H.264 デコード (HWデコーダ)          ← 負荷ゼロ
 canvas.drawImage() で 320×160 へ伸縮
 canvas.toBlob('image/jpeg') を Blob で連結
 POST /api/video ───────────────────────────▶  既存のアップロード経路 (変更不要)
```

`canvas` の JPEG 出力は Baseline (SOF0) なので `JpegScan` がそのまま受理する。APPn (JFIF/EXIF) は
マーカー長で読み飛ばされるため無害。**ファイルに fps 情報は入らない** (`SoloPlayer` は `kSoloFps=10`
固定で再生する) ので、「10fps にする」= 元動画のタイムラインを 100ms 刻みでサンプリングすることを指す。
30fps の全フレームを出力すると 3 倍のスローモーションになる。

| 項目 | 実装 |
| --- | --- |
| アスペクト比 | **2:1 への押し潰し固定** (元フレーム全体を 320×160 へ伸縮)。正距円筒として全周に貼るため、クロップやレターボックスより情報の欠落が無い方を採った |
| フレーム取り出し | `requestVideoFrameCallback` で `mediaTime` を見ながら 100ms スロットを埋める (2 倍速再生で実時間の半分)。取りこぼしたスロットは直前のフレームで埋めてフレーム数 = 再生時間を保つ。非対応ブラウザは 1 フレームずつシークする方式にフォールバック |
| サイズ見積り | 中央の 1 フレームを実際に符号化して 1f あたりのバイト数を測り、フレーム数を掛ける。`/api/status` が読めれば `fs.max_upload` と比較して変換前に警告する |
| 制限チェック | 1 フレーム 64KiB 超 / 総サイズが上限超のときは画質・長さの調整を促す |
| 出力 | `video.mjpg` を保存 / 共有。同一オリジン (球体が配信している場合) では `/api/video` へ直接アップロード |

**球体が `/convert` として配信する** (2026-09-22 実装)。AP 接続中の iPhone はインターネットに
出られないため外部サイトの変換ページを開けず、「iPhone の動画をそのまま入れたい」という要件は
同一オリジンでしか満たせない。正本は `docs/convert.html` (単体でもブラウザで開ける) で、
`python3 tools/embed_convert.py` が `src/ConvertPage.h` (PROGMEM) を生成する。**docs/convert.html を
編集したら必ず再生成すること**。埋め込みによるフラッシュ増は約 14KB (62.9% → 63.6%)。

**本体 UI にはファイル選択欄を置かない。** 動画の入れ替えは `/convert` への入口ボタン 1 つだけにし、
ファイルを選ぶのはそのページでの 1 回に統一した (本体 UI で選んでから変換ページへ遷移すると、
File オブジェクトは遷移で失われて選び直しになるため)。`/convert` は選ばれたファイルの先頭 3 バイトと
拡張子を見て、**すでに raw MJPEG なら変換を飛ばして直接アップロード**する。その際はブラウザ側で
全フレームを走査し、ファーム側の受理条件 (Baseline / 320×160 / 1 フレーム 64KiB 以下 / 末尾にゴミ無し)
を先に検査して、`corrupt JPEG structure` で弾かれる前に理由を表示する。
アップロードが成功したら結果を 1.2 秒表示して `/` へ戻る (球体は既に先頭から再生している)。
失敗時は理由を読めるようページに留まる。

容量の目安 (10fps)。LittleFS 3.94MB のうち同梱物は 39KB なので、動画に約 3.9MB 使える。

| 平均フレーム | 1 秒あたり | 再生できる長さ |
| --- | --- | --- |
| 5 KiB | 50 KiB | 約 78 秒 |
| 10 KiB | 100 KiB | 約 39 秒 |
| 20 KiB | 200 KiB | 約 19 秒 |

## 5. パーティションと容量

```
nvs       0x9000    0x4000
otadata   0xd000    0x2000
phy_init  0xf000    0x1000
ota_0     0x10000   0x200000   (2MB)
ota_1     0x210000  0x200000   (2MB)
spiffs    0x410000  0x3F0000   (3.94MB, LittleFS)
```

- OTA スロットを 2MB にした理由: §1 のとおり、派生元の時点で 1.72MB あり 1.5MB に収まらなかった。
  本リポジトリのビルドは 1,734,465 bytes = 2MB の 82.7% で、約 360KB の余裕がある。
- 8MB flash の未使用領域 (約 1.94MB) を OTA 増分 1MB と LittleFS 増分 0.94MB に配分した。
- アップロード上限 (`/api/status` の `fs.max_upload`) = 空き + 既存動画サイズ − 64KiB (LittleFS 余裕)。
- 一時ファイルと既存動画を同時に置けないサイズのときだけ、既存動画を先に削除して受信する
  (`replaced_before_upload: true`)。失敗すると `no_video` になり再アップロードできる。

### 書き込み手順

パーティション表は USB でしか更新できない (OTA では書き換わらない)。初回は必ず USB で書き込む。

```bash
pio run -e atoms3r -t upload      # ファーム + パーティション表 (USB)
pio run -e atoms3r -t uploadfs    # data/ を LittleFS へ (config.json, レイアウト CSV)
```

以後のファーム更新は `pio run -e atoms3r_ota -t upload` (先に PC を SoftAP へ接続)。

電源断: 一時ファイルへ書いてから rename するので、途中で切れても `/video.mjpg` は旧状態のまま。
`/video.tmp` が残った場合は次回アップロード時に削除される。マウント失敗時に勝手にフォーマットはしない。

## 6. 接続導線: QR とキャプティブポータル (NFC を採らなかった理由)

1. 端末が 1 台も繋がっていない間、本体 LCD に Wi-Fi 接続 QR
   (`WIFI:T:WPA;S:isolation-sphere;P:sphere-solo;;`) と SSID / URL を表示する
   (`LCDManager::drawWifiQr`、`sphere.features.LCD.debug = true` のとき)。
2. iPhone のカメラで読むと「ネットワーク “isolation-sphere” に接続」が出る → タップで接続。
3. 接続直後に iOS が `captive.apple.com/hotspot-detect.html` を取得しようとする。デバイスの DNS が
   全ホスト名を 192.168.4.1 に解決し、HTTP は `/api/` 以外の未知パスを `http://192.168.4.1/?cna=1`
   へ 302 で返すため、iOS は期待する "Success" を受け取れず **「ログイン」画面 (Captive Network
   Assistant) に Web UI を表示する**。Android (`/generate_204`) / Windows (`/connecttest.txt`) も同様。
4. 端末が接続されると LCD は映像 / STANDBY 表示に戻る。切断すると QR に戻る。

**既定ではキャプティブポータルを開かせない** (`solo.captive_portal = false`)。iOS の「ログイン」画面
(Captive Network Assistant) は簡易ブラウザで **`<input type=file>` のダイアログが出ず、動画を
アップロードできない** (実機で確認)。そのため OS の検出プローブには期待どおりの応答を返し、
利用者には最初から Safari で開いてもらう:

| プローブ | 応答 |
| --- | --- |
| iOS/macOS `/hotspot-detect.html`, `/library/test/success.html` | `<HTML>…<BODY>Success</BODY></HTML>` |
| Android `/generate_204`, `/gen_204` | 204 No Content |
| Windows `/connecttest.txt` / `/ncsi.txt` | `Microsoft Connect Test` / `Microsoft NCSI` |
| Firefox/NM `/success.txt` | `success` |
| 上記以外の未知パス | `http://192.168.4.1/?cna=1` へ 302 (利用者が何か入力した場合の救済) |

導線は **QR 2 枚**:

1. LCD の **Wi-Fi QR** (端末が未接続のとき表示) → カメラで読むと AP 参加を提案
2. 参加後、LCD が **UI の URL QR** (`http://192.168.4.1/`) に切り替わる → カメラで読むと **Safari** が開く
   (`SoloWebServer::uiServed()` が false の間だけ表示。UI を一度開いたら映像 / STANDBY へ戻る)

`tools/make_wifi_qr.py` はこの 2 枚を `docs/wifi_qr.png` / `docs/ui_qr.png` として出力するので、
LCD 非搭載機や印刷運用でも同じ導線が取れる。

`solo.captive_portal = true` にすると従来どおり接続と同時に UI が自動で開く (アップロードは
Safari で開き直す必要あり)。既定値はコード側 (`getSoloCaptivePortal()`) も false なので、
config.json を更新していない機体でも抑止側で動く。

### QR 画像の生成 (`tools/make_wifi_qr.py`)

印刷して本体に貼る / LCD 非搭載機 (XIAO ESP32S3) 向けに、`data/config.json` の `solo.ap` から
QR 画像を生成する。文字列の組み立て (エスケープ規則・パスワード 8 文字未満は `nopass`) は
`NetworkManager::wifiQrText()` と同一。

```bash
pip install segno            # cairosvg があればラベルの PNG も出る
python3 tools/make_wifi_qr.py
```

| 出力 | 内容 |
| --- | --- |
| `docs/wifi_qr.png` | 接続用 QR。`WIFI:T:WPA;S:isolation-sphere;P:sphere-solo;;` (33×33 モジュール, version 4) |
| `docs/ui_qr.png` | 接続後に開く `http://192.168.4.1/` の URL QR |
| `docs/wifi_qr_label.svg` / `.png` | QR + SSID / パスワード / URL を並べた印刷用ラベル |

生成した 3 つの画像は zxing-cpp でデコードして内容を確認済み。シリアルログにも
`[SOLO] Wi-Fi QR: WIFI:T:WPA;S:...;P:...;;` が出るので、任意の QR 生成ツールに入れてもよい。

### NFC について

- iPhone は **NFC タグから Wi-Fi に参加できない** (Android の Wi-Fi NDEF は iOS 非対応)。NFC でできるのは
  URL レコードを読んで Safari を開くことだけで、AP に繋がっていなければ `http://192.168.4.1/` は開けない。
- したがって NFC 単独では「接続 → UI」の導線が成立せず、QR (接続) + キャプティブポータル (UI 起動) を採用した。
- 接続後のショートカットとして、`http://192.168.4.1/` を書いた**受動 NFC タグ**を球体に貼るのは有効
  (ファーム変更不要、iPhone XS 以降は画面点灯中に近づけるだけで Safari が開く)。任意のオプション。

### OTA の経路: AP 経由と LAN (STA) 経由

AP 経由 (`atoms3r_ota` → 192.168.4.1) は、書き込む PC の Wi-Fi を球体の AP に繋ぎ替える必要があり、
その間 PC はインターネットから切れる。開発中はこれが煩雑なので **AP+STA 同時接続**を用意した。

- Web UI の「LAN 接続 (開発用 / 任意)」に普段の Wi-Fi の SSID / パスワードを入れて保存 → 再起動
- 球体は **AP を維持したまま** STA でも接続する (`WIFI_AP_STA`)。iPhone は従来どおり AP に繋がる
- PC は普段の LAN のまま `tools/ota.sh` (中身は `pio run -e atoms3r_lan_ota -t upload --upload-port <IP>`)
  で書き込める。mDNS 名は `<sphere id>.local` (既定 `sphere001.local`) だが PC 側で時々解決に失敗する
  (`getent` は通るのに espota が `Host Not Found`、実機 2026-09-23) ので、スクリプトが先に IP を解決して
  直指定する。解決できないときは `SPHERE_IP=<IP> tools/ota.sh` (IP は Web UI の「LAN (STA)」欄 /
  `/api/status` の `sta.ip`)。server モードでは P2P 網の固定 IP (例 192.168.49.101) を指定する

LAN の資格情報は **NVS に保存**する (`Preferences`, namespace `solo`)。config.json に書かないのは、
自宅 Wi-Fi のパスワードがリポジトリに混入するのを避けるため。SSID を空で保存すると無効化。
P2P 網 (配信 server) の SSID/パスワードは派生元と同じく config.json `wifi{}` に置く (固定値)。
優先順は **NVS > config.json** (利用者が変えた値が勝つ。明るさと同じ規則)。
`/api/status` に `sta:{enabled,connected,ssid,ip,origin}` (`origin` = `nvs|config|none`) が出る。
STA は起動時に先行して最大 2 秒待ち、AP を STA と同じチャンネルで立てる。相手 AP が居ないときは
5s→60s のバックオフで再接続する (autoReconnect の連続スキャンで SoftAP の応答が鈍るのを防ぐ)。

注意: ESP32 は AP と STA で無線を共有するため、**AP のチャンネルは STA 側に追従する**。
STA が 5GHz 専用 AP にしか繋がらない環境では使えない (ESP32-S3 は 2.4GHz のみ)。

## 7. HTTP API

| Method | Path | Body | 説明 |
| --- | --- | --- | --- |
| GET | `/` | — | Web UI (`?cna=1` でキャプティブ画面向けバナー。`uiServed` を立てる) |
| GET | `/convert` | — | 動画変換ページ (ブラウザ内で 320×160/10fps の raw MJPEG に変換し、そのまま `/api/video` へ) |
| GET | `/api/status` | — | 状態・動画情報・統計・容量・`ap` / `sta` / `server{configured,enabled,ssid,broker,mqtt}` / `source{mode,active,net_fps,udp_rx,reasm_drop,...}` / `led` / `imu` |
| POST | `/api/play` / `/api/pause` / `/api/stop` | — | ローカル再生 / 一時停止 (表示維持) / 停止 (消灯) (uploading 中・動画なしは 409)。配信中は表示は配信が握り、停止は配信終了後に効く |
| POST | `/api/led` | `{mode, pattern, width, axis}` | `mode`: sphere / test / off / pixels、`pattern`: strip / chase、`width` 1-60、`axis` bool |
| GET/POST | `/api/imu` | `{smooth_frames, i2c_khz, aux, word_read, reset, dump, reset_timing}` | IMU 診断と実行時スイッチ (`?dump=1` で生サンプル) |
| POST | `/api/source` | `{"mode":"auto|local|network"}` | 映像ソースの調停モード (再起動不要、保存しない) |
| POST | `/api/server` | `{"enabled":bool}` | config.json `wifi.enabled` を書き換えて保存し 0.8 秒後に再起動 (`"reboot":false` で保存のみ)。`wifi{}` が無ければ P2P 網の既定値で作る |
| POST | `/api/wifi` | `{ssid, password}` | STA (LAN) の資格情報を NVS に保存。空 SSID で無効化 (config の P2P 網に戻る)。反映は再起動後 |
| POST | `/api/brightness` | `{"value":0-100}` | 明るさ % (γ=2.2 で LED 値に変換。NVS に保存) |
| POST | `/api/video` | 動画本体 (`application/octet-stream`) | アップロード。成功 200 / 検証失敗 400 / 容量不足 507 / 競合 409 |
| POST | `/api/video/delete` | — | 動画削除 → `no_video` |
| POST | `/api/power` | `{ap, ap_idle_min, modem_sleep}` | 省電力 (指定したキーだけ反映)。`ap` bool (`false` は応答後に AP を止める。この接続も切れる)、`ap_idle_min` 0-1440 (NVS 保存、0=常時 ON)、`modem_sleep` bool (NVS 保存)。状態は `/api/status` の `power{ap_running,ap_idle_min,modem_sleep}` |
| POST | `/api/reboot` | — | 再起動 |
| * | `/api/` 以外の未知パス | — | `302 → http://<AP IP>/?cna=1` (キャプティブポータル検出用) |

```bash
curl -s http://192.168.4.1/api/status | jq .
curl -s -X POST --data-binary @video.mjpg -H 'Content-Type: application/octet-stream' http://192.168.4.1/api/video
curl -s -X POST -d '{"value":30}' http://192.168.4.1/api/brightness
```

## 8. 設定 (`data/config.json` と NVS)

役割分担: **config.json = 出荷時の既定値**、**NVS = 利用者が UI で変えた値**。起動時は NVS が
あればそちらを使い、無ければ config.json を読む。

| 項目 | 保存先 | 書き込み契機 |
| --- | --- | --- |
| 明るさ / XYZ 軸表示 / IMU 平滑 | NVS (`solo`/`bri`,`axis`,`smooth`) | Web UI・MQTT どちらから変えても、最後の変更から 3 秒後に 1 回 ([Settings.cpp](../src/Settings.cpp))。再起動要求時は即座に確定 |
| STA (LAN) の SSID / パスワード | NVS (`solo`/`sta_ssid`,`sta_pass`) | `/api/wifi` |
| server 接続の ON/OFF (`wifi.enabled`) | `config.json` (球体上) | `/api/server` / コンソール `server on|off` → `saveConfig()` → 再起動 |
| 解像度・AP・P2P 網・broker・調停・spheres[]・オープニング等 | `config.json` | `uploadfs` |

スライダーは操作中に値が連続で飛んでくるため、変更のたびに書くとフラッシュを無駄に消耗する。
`Settings::setBrightness()` は RAM を更新して保留にするだけで、`Settings::tick()` が最後の変更から
3 秒経ってから 1 回だけ書く。値が変わっていなければ書かない。

| キー | 既定 | 説明 |
| --- | --- | --- |
| `solo.video_path` | `/video.mjpg` | 再生する動画 |
| `solo.http_port` | `80` | Web UI のポート |
| `solo.ap.ssid` / `password` / `ip` | `isolation-sphere` / `sphere-solo` / `192.168.4.1` | SoftAP。パスフレーズが 8 文字未満ならオープン AP で起動し警告を出す (QR も `T:nopass`) |
| `wifi.mode` | `auto` | `auto` (STA 資格情報があれば AP+STA) / `ap` (STA を使わない。NVS も無視) / `ap_sta` |
| `wifi.enabled` | `true` | server 接続 (P2P 網 STA + MQTT + UDP) の ON/OFF。Web UI の「サーバ接続」が書き換える |
| `wifi.SSID` / `password` | `ESP32-P2P-Direct` / … | 配信 server の P2P 網 (派生元と同じ鍵名・値。Python server も同じファイルを読む) |
| `wifi.broker` / `mqtt_port` / `udp_port` | `192.168.49.1` / `1883` / `8889` | MQTT ブローカーと UDP 映像ポート。`broker` 空なら MQTT を使わない |
| `source.mode` | `auto` | 映像ソースの調停 (§10)。`local` / `network` で固定も可 |
| `source.idle_timeout_ms` | `2000` | 配信がこの時間途切れたらローカルへ戻す |
| `source.idle_blank` | `true` | 途切れ後にローカル再生が無ければ黒 (`false` = 最終フレーム保持) |
| `source.udp_queue_len` | `32` | UDP 受信キュー段数 (1 段 ≈ 1.5KB、PSRAM) |
| `telemetry.imu_hz` | `10` | MQTT `sphere/<id>/imu` の publish レート (0 で無効。接続中のみ) |
| `spheres[]` | sphere001/002 | MAC → 自機エントリ (id / static_ip / features)。旧形式の単一 `sphere{}` も受理。MAC 不一致なら空 mac の枠 → 先頭 (警告ログ) |
| `image.width` / `height` | `320` / `160` | 受理する解像度 |
| `params.brightness` | `50` | 起動時の明るさ [%] (γ=2.2 で LED 値へ。50% → 55/255) |
| `system.opening_action` | `enabled: true, 1200ms` | 起動時の LED オープニング |
| `system.debug` | `true` | `DEBUG_*` マクロのログ出力 |
| `sphere.features.LCD.debug` | `true` | LCD 表示 (QR / 映像 / STANDBY)。`false` で LCD 無効 |
| `sphere.features.IMU` | `BNO055` | IMU 種別 (ビルド env の `IMU_SENSOR_*` も参照) |

## 9. 検証状況

### ソース / ビルドで確認したこと

| コマンド | 結果 |
| --- | --- |
| `pio test -e native` | **42 ケース PASS** (IMU 4 スイート 22 ケースを派生元から移植)。JPEG 境界パーサー 13 ケース (完全フレーム、全プレフィックスで NeedMore、連結分割、APP1 内 EOI 非誤検出、非 SOI、progressive 判定、マーカー間ゴミ、SOS 前 EOI、SOI 入れ子、フィルバイト、長さ 0 セグメント、TEM/RSTn、null) + `MjpegAssembler` 7 ケース (復帰後のフレームが無傷: read 幅 1/3/64/700/2048/一括、先読みの温存、切れた末尾の破棄とループ、非ループ時の Eof/Truncated、TooLarge、空/ゴミ) |
| `pio run -e atoms3r` | **SUCCESS**。Flash 1,734,465 / 2,097,152 bytes (82.7%)、RAM 68,484 / 327,680 bytes (20.9%) |
| `pio run -e xiao_esp32s3` | **SUCCESS**。Flash 1,466,289 bytes (69.9%)、RAM 64,920 bytes (19.8%)。LCD 無しのため QR 表示は無効 |

### 実機で確認したこと (2026-09-22, AtomS3R, USB 給電)

書き込みは USB (`uploadfs` → `upload` の順。先に FS を 0x410000 へ置き、表とアプリを書いてから初回起動させる)。

| 項目 | 結果 |
| --- | --- |
| 起動 → 自動再生 → ループ | OK。`state=playing loops=2`、`tools/make_test_pattern.py` の 100 フレーム動画 |
| 100ms 締切 | **fps=10.0 miss=0**。`read=4-6ms` (LittleFS→PSRAM 2048B 追記読み) + `decode=62ms` (TJpgDec 320×160 4:2:0) = `tick=67-70ms`、余裕 約30ms |
| デコード | **decode_err=0** (下記の不具合修正後)。修正前は 100 フレーム中 87 が `JDR_FMT1` |
| LittleFS / config / SoftAP / OTA 受け口 / Web (port 80) | すべて起動。QR 文字列 `WIFI:T:WPA;S:isolation-sphere;P:sphere-solo;;` を出力 |
| メモリ | `heap_free≈205KB`、PSRAM 8MB 認識、`solo_play` スタック残 3.7KB / 6KB |
| IMU | `Scan done: 0 device(s)` — **AtomS3R を本体から外して試験したため** (BNO055 は本体側)。IMU 無しで続行できることの確認になった |
| LED 出力 | **`out=55-58ms` (render_fps 16.6)**。設計値 6-8ms に対し約 8 倍遅い。未解決 (下記) |

#### 実機で見つかった不具合: 先読みバイトによるフレーム上書き (修正済み)

症状: 再生は始まるが 100 フレーム中 87 が `drawJpg → JDR_FMT1` で落ち、失敗するフレームは毎ループ同一。
LED 出力を止めても、内部 RAM にコピーしても、PC で同じ `tjpgd.c` を走らせても再現せず、
LittleFS の読み出し自体 (PSRAM/内部 RAM、512-9496B の各チャンク幅) は全 233 チャンク一致。
デコーダに渡したバイト列の CRC32 をフレームごとに出して PC と照合したところ不一致で、frame0 の
壊れた 180..744 バイト目が **frame1 の同オフセットのバイト列と完全一致** (744 = 先読み量) した。

原因: `MjpegReader::next()` がフレーム確定時に先読み分をバッファ先頭へ `memmove` してから return
していた。呼び出し側 (`SoloPlayer`) がデコードする時点で、返したフレームの先頭が次フレームで
上書きされている。先頭 180 バイトが無事に見えたのは SOI/APP0/DQT が隣接フレームと同一だったため。
先読み量が小さいフレームだけ生き残る = 決定的なパターン。

修正: 先読みの寄せを **次回 `next()` 呼び出しの冒頭**に遅延 (`_consumed`)。バッファ管理を Arduino
非依存の [`src/MjpegAssembler.h`](../src/MjpegAssembler.h) に切り出し、`MjpegReader::next()` と
`validate()` の両方がこれを使う。`test/test_mjpeg_assembler` が「復帰後のフレームが無傷」を
read 幅ごとに検証する (PC でこの呼び出し順を再現すると修正前は 87/100 が実機と同一パターンで失敗、
修正後は 0/100)。

#### 実機で見つかった不具合: IMU 姿勢のジャンプ → 派生元 feat/ui-v2 の IMU スタックを移植

症状: 球体を回すと姿勢が数十度飛んで往復する。静止中は起きない。派生元 core (server あり) でも
同じ症状があり、**`feat/ui-v2` ブランチで 2026-09-09 に解決済み**だった (solo は `main` から切り出した
ため未反映)。経緯は派生元 `docs/HANDOFF_2026-09-09_imu_jump.md`。

solo 側でも 100Hz 生ダンプ (`/api/imu`) で独立に同じ原因に到達した:

```
t=149531  w=14807 x=-6576 y=-2437 z=    3   ← 正常
t=149553  w=14808 x=-6577 y= -126 z=   -1   ← y の上位バイトが 0xFF、z が 0xFFFF
t=149604  w=14810 x=-6574 y= -123 z=   -1   ← 4 サンプル (約 75ms) 連続で化けたまま
t=149627  w=14809 x=-6572 y=-2437 z=    4   ← 戻る → 見た目は ±16° の往復
t=158010  w=14775 x=   -1 y=   -1 z=   -1   ← 2 バイト目以降が全部 0xFF (|q|^2=0.813)
```

- BNO055 の多バイト I2C 読みで**上位バイトだけが 0xFF になる** (下位は真値)。`requestFrom` は要求
  バイト数を返すのでトランスポートは成功扱い (`fails=0`)。中身で弾かないと通る
- 潰れた成分の真値が |v|=0.2〜0.38 だと |q|^2 が 0.85〜0.98 で緩いノルム窓を通過し、いったん受理
  されると連続性ガードが**以後の真値を棄却し続ける** → 真値 ⇄ 化け値の往復 = 高周波ジャンプ
- 連続性ガードの gyro を deg/s のまま rad/s として使っていた (約 57 倍ゆるく、回転中は無効)
- 副次: 8B バースト読み (~5ms) が 10ms の融合更新境界をまたぐ (回転中の約 45%)

対策 = 派生元の実装をそのまま移植 (`src/imu/*`, `IMUManager{,_bno055,_m5imu}.cpp`, `PeriodicTimer.h`):

| 部品 | 内容 |
| --- | --- |
| `Bno055QuatReader` | quat を **2B×4 の分割読み**。MSB が 0xFF/0x00 のワードは前回受理値から 800 LSB 以内でなければ部分読みとして読み直し (最大 3 回)。x,y,z の後に **w を再読みして一致を要求** (融合境界跨ぎの検出 = `straddle`) |
| `Bno055Codec` | LE デコード / MSB 欠落判定 / 全ゼロ・末尾埋め検出 |
| `AttitudeValidator` | ノルム窓 0.85〜1.15 + 連続性ガード (gyro は rad/s) + 強制受理 |
| `QuatSmoother` | 符号合わせ付き移動平均 (`imu.smooth_frames`、既定 10。`/api/imu {smooth_frames}` で変更、NVS に保存) |
| `ImuDiag` | 累計カウンタ (`fail/disc/zero/partial/straddle`)、IMU タスク → loop の診断スナップショット、`imu_dump` リング |
| `I2cLock` | I2C は IMU タスクだけが触る |
| 専用タスク `IMU_Poll` | core1 優先度 3 で 100Hz 固定。棄却率 50% 超が 4 秒続けば BNO055 を自動再初期化 (15 秒クールダウン)。`Wire.setTimeOut(20)` |

solo 固有の追加:
- `IMUManager_bno055::begin()` に `Wire.setClock(_i2cHz)` を追加。`main.cpp` の `scanI2cBus()` が先に
  `Wire.begin` しており、**`Wire.begin` は 2 回目以降は周波数を再設定しない**ため、IMUManager の
  100kHz 指定が無視されて 400kHz のまま動いていた (実機で `Wire.getClock()` を出して確定)。
  走査自体も 100kHz にした
- `/api/imu` GET: カウンタ / cal / mode / quat / i2c / smooth。`?dump=1` で imu_dump の生サンプルを返す。
  POST: `{smooth_frames, reset, i2c_khz (50-400), aux, word_read, dump (<=2000)}`
- UI の IMU カードに partial/straddle、平滑スライダー、再初期化ボタン
- `[RATE]` ログを派生元書式に (zero/partial/straddle/i2c/word/smooth/seq)。診断スナップショットは
  loop 側で吐く (IMU タスクは Log を呼ばない)
- native テストを移植: `test_bno_codec` / `test_attitude_validator` / `test_quat_smoother` / `test_imu_diag`
  (`test/mocks/Arduino.h`、`-std=c++14`)。**合計 42 ケース PASS**

移植前に solo 側で見つけた別の原因: IMU を `loopTask` から読んでいたため、LCD の QR 再描画 (`c.qrcode`
約 70ms、500ms 周期) と 2 秒周期のログで**読み出し周期が中央値 22ms・最大 240ms** に乱れていた
(100Hz 設計)。読めない間は描画が古い姿勢のまま止まり、次に読めた瞬間に追いつく = これもジャンプに見える。
IMU 専用タスクで解消。QR は文字列が変わったときだけ生成するようにした。

派生元の未解決事項 (引き継ぎ): `_recoverI2cBus()` は無効化中 (有効にした起動で BNO055 未検出)、
`readVector6` (accel/gyro/euler) に MSB 欠落判定が無い (euler が化けるのを観測、GestureManager が使う)、
`atoms3r_m5imu` env はリンクしない (QUARANTINED)。

実機確認 (2026-09-23, 本体に組み込み LiPo、OTA 後):

| 条件 | 読み出し | fail | disc | partial | straddle | 受理姿勢の飛び (15° 超) |
| --- | --- | --- | --- | --- | --- | --- |
| 静止 25 秒, I2C 100kHz | 39.8/s | 0 | 0 | **16.6/s** | 1.0/s | 0 回 (最大 1.8°) |
| 静止 20 秒, I2C 400kHz (実行時切替) | 47.6/s | 0 | 0 | 0.1/s | 0.8/s | 0 回 |
| 静止 20 秒, I2C 100kHz に戻す | 41.3/s | 0 | 0 | 0 | 0.3/s | 0 回 |

- **化けは静止中でも 17% の頻度で起きており、全件を検出して読み直し、姿勢には出ていない**
  (disc 0 / 飛び 0)。移植前は同条件で受理姿勢の飛びが 90 秒に 16 回出ていた
- 読み出しレートは **約 40〜48/s** で設計 100Hz に届かない。I2C クロックを 400kHz にしても +15% なので
  クロックではなくトランザクション数 (2B 分割読み: quat 4 + w 再読み 1 + 補助 1 ベクタ = 約 8 回/周期、
  Wire の 1 トランザクション約 2ms) が律速。派生元が 90〜100/s だったのは、走査の 400kHz が
  `Wire.begin` で上書きされず実質 400kHz だったため。描画 (約 49fps) に対しては毎フレーム更新に近く、
  体感上は問題にならない見込み。平滑 10 フレームは 45Hz では約 220ms の遅れになるので、
  遅れが気になれば `/api/imu {smooth_frames: 5}` 程度に下げる
- 100kHz と 400kHz で化け率 (partial) は 16.6/s → 0.1/s と大きく違った。ただし静止 20 秒の単発比較で、
  100kHz に戻した直後は 0/s だったので、時間変動 (電源・温度) の可能性がある。既定は 100kHz のまま、
  `/api/imu {i2c_khz}` で切り替えて様子を見る
- 回転中の生ダンプ (100kHz、856 サンプル): 受理 766 / 読み失敗 81 / 棄却 9。**読み失敗 81 件のうち 80 件は
  |q|²=1.000 の正常値**で、受理間の 15° 超の飛び 12 件のうち 11 件は「間に 1〜17 回の読み失敗を挟んだ」
  もの (角速度換算 116〜376°/s = 手の回転そのもの)。つまり残っていたジャンプは化けの素通りではなく、
  **正常値の誤棄却 → 姿勢保持 → 追いつき**。原因は (1) w 再読みの bit 一致要求 (回転中は 416/856 サンプル
  で再読みが走る)、(2) MSB 欠落判定の 800 LSB が、読み失敗で prevAccepted が古くなると本物の小さい値を
  弾く。→ solo 側で改良: w 再読みは差分 600 LSB 以内なら同一サンプル扱い (`wordsDisagree`)、MSB 欠落の
  許容幅は前回受理からの経過時間で 400°/s 相当に伸ばす (`partialToleranceLsb`、上限 4000)。
  native テストを追加 (test_bno_codec)
- 400kHz にすると化けの出方が変わり、**下位ワードが 0x00 で埋まる** (`c4 32 00 00 00 00 00 00`) 形で
  静止中でも 14% のサイクルが読み失敗する (100kHz では読み直しで全件回復、失敗 0)。既定は 100kHz。
  派生元が実質 400kHz で 90〜100/s 出ていたのは、この失敗を「読み失敗 → 前回値保持」で吸収していたため
- 利用者評価 (平滑 3): 「時々ジャンプが発生するが、かなり改善している」
- 許容幅改良版の回転ダンプ (ダンプ B: 1928 サンプル、うち 1351 区間が回転中): **読み失敗 0 / 誤棄却 0 /
  straddle 再読み 2** (改良前 81 / 80 / 496)。正常値を捨てて止まる問題は解消。
  残った受理間 15° 超は 15 件で性質が変わった: 間に欠落なし・dt≈24ms・角速度換算 700〜1165°/s
  (手の回転は中央値 190°/s)。前後の生値を見ると**飛びの「直前」の受理値が全て化け**
  (x=-76〜-404 = 0xFFxx、n²=0.979〜0.994) で、真値 (x≈-2500) に戻る瞬間が飛びとして見えていた。
  MSB 欠落の差分判定を経過時間で伸ばしたことで、読み出しが遅れた周期 (40〜100ms) に |v|≈0.15 の
  成分の化け (Δ≈2300 LSB) が通るようになっていた
- 対策 (再修正): (1) 組み立てた 8 バイトの**ノルム² を読み出し試行内で検査** (1±0.02 を外れたら
  同じ周期で読み直す、`quatNormImplausible`)。健全な出力は 0.999〜1.000 に張り付くのでワード差分とは
  独立に化けを捕まえられる。(2) 差分判定の許容幅の上限を 4000 → 2000 LSB。(3) `AttitudeValidator` の
  ノルム窓を 0.85〜1.15 → 0.97〜1.03 (派生元の「0.92〜0.98 を常用」は化け値込みの観測だった)。
  しきい値はダンプ B の実測から決めた: **健全値の最大ずれ |n²-1|=0.0072、化けの最小ずれ 0.019** なので
  読み直し判定は 0.015
- 再確認 (静止 20 秒): 読み出し 39.8/s、**fail 0 / disc 0 / partial 0 / straddle 0**、姿勢の飛び 0。
  読み直しが 0 になったのは、ノルム検査が同じ周期内で化けを捕まえて再読みし、成功しているため
  (partial は「弾いた回数」なので、弾く前に読めていれば増えない)
- 利用者評価 (平滑 3、ノルム検査あり): 「かなり向上した。ジャンプもたまにあるが、気にならない程度に
  収まり始めている」

#### 読み出しレート 40/s の原因: IMU タスクが起動していなかった

I2C クロックを 100/200/300/400kHz で A/B しても 40 → 46/s しか変わらず (fail/partial は全て 0)、
クロックは律速ではなかった。`/api/imu` に `task_running` と周期の内訳 (`cycle_us` / `upd_us` /
`quat_us`) を出して確認したところ **`task_running=false`**: `ota.begin()` を SoftAP 直後へ前倒しした
とき、`startTask()` の呼び出しをその直前 (= IMU 初期化より前) に置いてしまい、`isInitialized()` が
false で一度も起動していなかった。40/s は loop ポーリングのフォールバックが LCD 再描画などに
削られた値。`startTask()` を setup 末尾へ移して解消:

```
task_running=True   受理 100.5/s  読み 100.5/s   fail 0 / disc 0 / partial 0 / straddle 0
1 周期 10.00 ms = _updateOnce 6.03 ms (quat 4 ワード + w 再読み 4.60 ms、aux 1.44 ms) + 待ち 3.96 ms
```

I2C 100kHz のまま設計値 100Hz に到達。1 周期に 4ms の余裕があるので 100kHz を既定に維持する
(400kHz は 0x00 埋めの化けが増える)。平滑 3 フレームの遅れは 30ms。

**利用者評価 (100Hz 到達後): 「平滑 1 でもジャンプはない」** — 移動平均なしで姿勢追従が滑らかになった。
平滑は化け対策ではなく好みの範囲で使うもの (config.json の既定 10 は派生元の値。solo では
1〜3 で十分)。IMU ジャンプの件はここで解決とする。

#### 未解決: LED 出力 55-58ms

FastLED 3.10.5 の RMT4 ドライバ (IDF 4.4)。ESP32-S3 の RMT TX チャンネルは 4 本
(`SOC_RMT_TX_CANDIDATES_PER_GROUP=4`) で、AtomS3R の 5 ストリップ目は「時分割」で後回しになる。
完了検出はポーリング + 1ms スライス (`ChannelManager::waitForPollNeededSignal`)。それでも 58ms の
説明には足りない。**試して外れたもの**: FastLED の実行時ログ無効化 (`FASTLED_LOG_VERBOSITY=0`、
`out=53-56ms` で変化なし。フラッシュ削減のため設定は残した)。残る切り分け候補は
(a) `-D BOARD_NUM_STRIPS=4` で 4 ストリップ構成にして `out=` を計測 (時分割の影響を確定)、
(b) `FASTLED_RMT_MEM_BLOCKS` 増加、(c) S3 の I2S/LCD_CAM 並列ドライバへの切替。映像 10fps の表示自体は間に合っており、
影響は IMU 姿勢追従の滑らかさ (設計 50-60Hz → 実測 16.6Hz)。

#### 本体に組み込んで LiPo 起動: 起動音 → 全 LED 白点灯 → 電源断 (対処中)

上表の実機確認はすべて **AtomS3R を本体から外して USB 単体**で行ったもの (LED 800 個と BNO055 は
本体側)。本体に戻して LiPo で起動すると、起動音の直後に全 LED が白点灯し電源が落ちた。
起動順序は `earlyBlank()` (全ストリップに黒を送信) → Serial → 起動音 → 2 秒待ち、なので、
**黒を送ったはずの `earlyBlank()` が LED に白として受け取られている** (データ線のタイミング逸脱で
0 ビットが 1 に読まれる) と見ている。

同じ 3.10.5 ビルドで、本体に組み込んだまま USB 給電で起動したときは**全 LED が暗い赤**で点灯した
(電源電圧の違いで LED 側の閾値が変わったと見れば、白と同じ「黒データが別の値に読まれる」症状)。

以前動いていた core ビルドとの差は FastLED の版。指定は同じ `^3.7.8` だが現在は **3.10.5** に解決され、
ESP32 の RMT ドライバが ChannelManager 実装 (S3 の TX 4 チャンネルに 5 ストリップを時分割) に
置き換わっている。core の現行ソースが 3.10 ではビルドできない (`memset` 曖昧呼び出し) ことから、
以前の書き込みは 3.10 より前の版。ベンチの LED 出力 55ms (設計値 6-8ms) も同じ差の症状と考えられる。

対処: `platformio.ini` で **FastLED を 3.7.8 に固定** (元プロジェクトが `^3.7.8` を宣言した時点の版 =
球体が動いていた実績のある版)。この版でのビルドは Flash **1,307,717 bytes** (3.10.5 では 1,721,757、
3.9.20 では 1,329,397) と約 414KB 小さく、**旧 1.5MB スロットにも収まる**。今日の表変更の前提
「ファームが 1.5MB に入らない」は 3.10 系の RMT 実装が原因だった。
3.7.8 に下げたところ、ベンチで起動直後に **`Guru Meditation Error: Core 1 panic'ed (Cache disabled but
cached memory region accessed)`** のリブートループになった。バックトレース:
`ESP32RMTController::interruptHandler → doneOnChannel → startNext → rmt_set_tx_thr_intr_en` (Core1 の
RMT 割り込みがフラッシュ上の IDF 関数を呼ぶ) と、同時刻の Core0 `SoloPlayer::begin → validate →
File::read → esp_flash_read` (キャッシュ無効化)。以前の core は映像を UDP で受けていてフラッシュを
読み続けなかったため踏まなかった。**solo が LittleFS を 10fps で読む構成では必ず起きる**。
対策として `-D FASTLED_ESP32_FLASH_LOCK=1` (show() の間 `spi_flash_op_lock()`) を両 env に追加。
3.10.5 では起きなかった (新実装は ISR を IRAM に置き、二重バッファで WiFi 干渉耐性を持つ) ので、
「白点灯」と「フラッシュ競合」は版のトレードオフになっている。

ベンチ計測 (3.7.8 + `FASTLED_ESP32_FLASH_LOCK=1`, LED 未接続):

| 項目 | 3.10.5 | 3.7.8 + FLASH_LOCK |
| --- | --- | --- |
| LED 出力 `out=` | 53-58ms | **15.2ms** |
| `render_fps` | 16.6 | **48.8-49.0** (設計値 50-60Hz にほぼ到達) |
| LittleFS 読み出し `read=` | 4-6ms | 10-20ms (show() 中はフラッシュロックで待たされる) |
| `tick=` (read + decode) | 67-70ms | 68-82ms (100ms 締切に対し余裕 約18ms) |
| 再生 / デコード | fps=10.0 miss=0 err=0 | fps=10.0 miss=0 err=0 |
| パニック | なし | なし (FLASH_LOCK 無しではリブートループ) |

`read=` の増加はロック待ちによるもので、締切内に収まっている。余裕が欲しくなったら
`kReadChunk` を大きくして read 回数を減らすか、デコードを先に走らせる順序に変える。
**本体に組み込んで LiPo 起動: 全白は出なくなった** (2026-09-22 夜、ユーザー確認)。
FastLED 3.10.5 の RMT 実装が原因だったと確定。

追加の実機フィードバックと対応:
- 停止しても最後のフレームが LED に残る → `ImageManager::publishBlack()` を追加し、`stop()` /
  動画クローズ (削除→no_video) / エラー時に全画素 0 のフレームを公開して消灯する。
  描画タスクは公開済みフレームを再マッピングし続ける設計なので、黒フレームを流すのが最小の変更。
- Web UI からファイルをアップロードできない → `<input type=file>` の `accept=".mjpg,…"` を撤去。
  iOS は accept に未知の拡張子があると「ファイル」アプリで該当ファイルがグレーアウトして選べない。
  形式検証はサーバ側 (validate) が行うので accept は不要。

FastLED を使わない選択肢: NeoPixelBus の S3 LCD_CAM 並列 (`NeoEsp32LcdX8Ws2812xMethod`, 8 本まで
真の並列) が本命。LEDManager の出力部差し替えと、色計算・電流制限の自前化が必要。
姿勢追従を設計値 50-60Hz で回す必要が出たときに検討する。

#### 起動経路の変更 (組み立て後の復旧手段を確保)

起動直後の `delay(2000)` (シリアルモニタ接続待ち) は、USB ホストが繋がっているとき
(`Serial.isConnected()`, HWCDC) だけ 300ms 待つように変更。電池駆動では待たない。

LittleFS マウント失敗・`config.json` 読み込み失敗で `while(1)` 停止していた箇所を撤去し、
ConfigManager のコンパイル時既定値で続行する。`ota.begin()` を SoftAP 直後に前倒しし、以降の初期化
(IMU / LED / 再生 / Web) が止まっても無線の書き戻しが生き残るようにした
(USB 端子に触れない筐体で、閉じた後に文鎮化する経路を潰す)。

### 実機で確認したこと (2026-09-23, 統合ファーム Phase 0〜5 + カクつき対策, LAN 経由 OTA)

利用者の実動画 (3.0MB / 565 フレーム / 平均 5KB/f) で「カクつく・時々止まる」が出た。`/api/status` に
描画・デコード統計を足して切り分けた結果と対策:

| 指標 | 旧 solo ファーム | 統合 (対策前) | 統合 (対策後) |
| --- | --- | --- | --- |
| 再生 fps / 締切落ち (静穏) | 7.2 / 9.6% | 7〜10 / 13% | **10.0 / 0%** |
| 締切落ち (0.5s 間隔で /api/status を叩く) | — | 37% | **0%** |
| LED 出力 1 回 (`render.out_us`) | 55ms (§9 既知) | 11ms | 10.5ms |
| 描画 fps | ~17 | 25〜47 | 50 |
| デコード 1 枚 (`img.decode_us`) | 55ms | 44〜411ms | 52〜64ms |

- **原因 1: `/api/status` がフラッシュを読んでいた**。`LittleFS.usedBytes()` は全ブロック走査、
  `LittleFS.open()` も読む。`spi_flash_read` は 1 回ごとに両コアのキャッシュを止めるので、httpd
  (Core0, 当時 prio 2 > 再生 prio 1) がデコードを引き延ばし、Core1 の描画も止めていた。Web UI は
  2 秒ごとに叩くため「UI を開いているとカクつく」。ポーリング間隔と締切落ちに用量反応があった
  (静穏 13% → 0.5s 間隔 37%) ので因果は確定。対策: 使用量は起動時・アップロード/削除の前後だけ
  再計算してキャッシュ、動画サイズは player の値を使う
- **原因 2: 再生自体のフラッシュ読み** (`read_us` 最大 19ms = LED 出力中のフラッシュ操作ロック待ち)。
  対策: open 時に動画全体を PSRAM に読み込む (`MjpegReader::openMemory`、3MB で 1.3 秒 = 2.2MB/s)。
  再生中はフラッシュに一切触らない。PSRAM 確保に失敗したときだけ従来のフラッシュ直読みに退避
- 併せて frame_pump を prio 2、httpd を prio 1 にして、状態表示やアップロード受信がデコードを奪わないようにした
- `FASTLED_RMT_MEM_BLOCKS=1` で LED 出力は 55ms → 10.5ms (派生元の実測どおり)。§9 冒頭の「55-58ms
  で原因不明」は解消。描画 50fps、IMU 追従も 50Hz に上がった
- 残りの余裕: デコード 52〜64ms は本来の値 (TJpg_Decoder `JD_FASTDECODE=1`)。100ms 締切に対し
  35〜45ms の余裕。さらに縮めるなら `JD_FASTDECODE=2` (ライブラリを `lib/` に同梱して設定変更、
  内部 RAM +6KB) か、数フレーム先にデコードしておくリングが次の手

### 実機で未確認のこと (次にやる実機チェック)

1. ~~起動と自動再生~~ → 確認済み (上表)
2. ~~締切~~ → 確認済み (上表)。ただし球体本来の電源での再確認が未了 (USB 給電で計測)
3. ~~姿勢追従~~ → 確認済み。本体に組み込んだ状態で 100Hz、平滑 1 でジャンプなし (上記)
4. **QR と自動起動**: LCD の QR を iPhone のカメラで読めるか (照度・サイズ)。接続後に「ログイン」画面が
   自動で開くか。接続すると LCD が映像 / STANDBY に戻るか
5. **iPhone Safari**: UI 表示 → アップロード進捗 → 完了後に先頭から再生 → 切断後も再生継続
6. **異常系**: 途中切れ / 解像度違い / progressive / 過大フレーム / 容量不足 / 送信中断 →
   `/video.mjpg` が壊れず、UI が理由を表示して再アップロードできる
7. **電源断**: アップロード中に電源を切る → 再起動後、旧動画が再生される (または `no_video`)。
   `/video.tmp` が残っていても次回アップロードで消える
8. **メモリ**: `/api/status` の `heap_free` / `psram_free` と各タスクのスタック余裕
   (`uxTaskGetStackHighWaterMark`) を記録する
9. **OTA**: パーティション変更後、USB で 1 回書いた機体に対して `atoms3r_ota` で更新できること
10. **ブラウザ変換** (`docs/convert.html`): iPhone Safari で `requestVideoFrameCallback` が動くか
    (非対応ならシーク方式に落ちる)。変換所要時間・1f あたりのバイト数・生成した `.mjpg` が
    アップロード検証を通るか。`<input type=file>` から camera roll の動画を選べるか
11. **統合ファーム (§10)**: 2026-09-23 の Phase 0〜5 はビルドと native テストのみで、**実機は未確認**。
    §10 の検証手順を順に実施する (solo 退行 → UDP 配信 → MQTT → OTA)

12. **省電力 (未確認)**: 2026-10-05 にビルドと native テストのみ。実機で、AP 自動停止後の再開 (シェイク /
    シリアル / MQTT) と OTA (`192.168.4.1`) が使えること、トリプルシェイクの感度 (誤検出・取りこぼし)、
    AP 停止/稼働別の消費電流を実測する

### 既知の制約

- 音声・シーク・複数動画・プレイリスト・サムネイルは無い (要件どおり)
- ~~LED 出力が 1 フレーム 55-58ms かかる~~ → `FASTLED_RMT_MEM_BLOCKS=1` で 10.5ms に解消 (2026-09-23 実測)。描画 50fps
- 動画は open 時に全体を PSRAM に読み込む (最大 3.9MB)。アップロード直後・起動直後に数秒の読み込み時間がある
- 本体に組み込んだ状態では **USB 給電で映像を再生できない** (LED 800 個の電流に足りず、起動直後の
  オープニングや再生開始で電圧が落ち USB が切れる)。書き込みは USB で可、動作確認は LiPo で行う
- ESP32 上で動画を変換する機能は無い。PC なら `tools/make_solo_video.sh`、iPhone 単体なら
  `docs/convert.html` (ブラウザ内変換、実機未確認)
- 明るさは NVS に保存され再起動後も復元される (§8)。config.json の値は「まだ一度も変えていないとき」の既定値
- QR 表示は LCD 搭載機 (AtomS3R) かつ `LCD.debug = true` のときのみ
- iOS の「ログイン」画面 (CNA) ではファイル選択ダイアログが出ない → 既定でキャプティブポータルを抑止し、LCD の URL QR から Safari で開く導線にした (§6)
- `TJpg_Decoder` はグローバル単一インスタンスのため、デコードを複数タスクから同時に呼べない
  → 配信・ローカルとも `FramePump` の 1 タスクが順番にデコードする (§10)
- LED 出力モード `Manual` は `mode: off / pixels` (Web UI `/api/led`、MQTT `led`) から使う。
  `pixels` の一括更新は MQTT 2KB の制約で ~50 LED/メッセージ (全球は UDP 映像経路で)

## 10. server モード (統合ファーム: server あり / なし を 1 バイナリで)

2026-09-23 に派生元 `feat/ui-v2` の server 系モジュール (MQTT / UDP 映像) を本リポジトリへ移植し、
solo と server を **同じファーム**で動かすようにした。計画: `~/.claude/plans/server-expressive-parnas.md`。
**実機確認は未了** (ビルドと native テスト 67 件のみ)。

### 方針

- 本リポジトリが superset。派生元 `core/` は凍結し、Python server はそのまま使う (プロトコル凍結:
  UDP 16B ヘッダ magic `0x4A504547` / 1400B チャンク / ≤46 チャンク、MQTT `sphere/<id>/...`、
  retained `state` ≤768B)
- デコードは `FramePump` の 1 タスクだけ。配信 (UDP) とローカル (MJPEG) を同じタスクが順番に処理する
- 調停は `auto`: 配信の完成フレームが `idle_timeout_ms` 以内に届いていれば配信を表示、途切れたら
  ローカルへ (Playing なら続きから、そうでなければ黒)。`local` は配信を読み捨て、`network` はローカルを止める
- 制御面 (Web UI / MQTT / コンソール) は `DeviceController` 1 つを呼ぶ。明るさは両方 γ=2.2、
  変更はどこから来ても NVS に保存
- AP は常時 (iPhone)。STA は NVS の LAN > config の P2P 網 (固定 IP は `spheres[].static_ip`)
- server モードの ON/OFF は config.json `wifi.enabled`。**Web UI の「サーバ接続」/ コンソール
  `server on|off` が球体上の config.json を書き換えて再起動**する (OTA では LittleFS を更新できない)。
  `wifi{}` が無い旧 config には P2P 網の既定値を書き込む

### 起動順と挙動

1. `Log.begin()` (PSRAM 退避) → FS → config (spheres[] を MAC で解決、警告あり) → Settings (NVS)
2. `NetworkManager::begin`: STA 先行 (≤2s) → SoftAP を同じチャンネルで
3. OTA (hostname = sphere id) → IMU → ImageManager → **FramePump 起動 → UDP listen** (server 設定時)
4. LED → `DeviceController::begin` (明るさ/軸を適用) → SoloPlayer (ファイルを開く、タスクは持たない)
   → Web UI → **MQTT** (最後。server は status/state を見た瞬間に配信を始めるため受け側を先に作る)
   → IMU タスク
5. loop: OTA → STA poll (バックオフ再接続) → `mqtt.loop` (STA 接続後に接続。切断時 5s 毎) →
   `Log.loop` (退避ログを 3 行/周) → DNS → 設定保存/再起動 → コンソール → LCD → ジェスチャー →
   周期ログ → imu (10Hz) / state (5s retained) publish

配信中の操作: `stop` / `pause` はローカル再生の状態だけ変える (黒要求は配信が表示を握っている間は
保留され、配信終了 + idle_timeout 後に効く)。Playing のままなら配信終了後に続きから再開。

MQTT: 受信 `sphere/<id>/command/#`、`sphere/all/command/#`、`sphere/all/clock` (TimeSync)。送信
`status` (online, retained)、`state` (5s, retained)、`imu` (10Hz)、`log` (RemoteLog)、`gesture` / `ui_mode`。
`led.source` (local/network/none) を `state.led` に追加した (server は未知キーを無視する)。

### メモリ (ビルド実測、atoms3r)

| | Phase 0 (solo のみ) | Phase 5 (統合) |
| --- | --- | --- |
| Flash (2MB スロット) | 1,366,793 B (65.2%) | 1,487,237 B (70.9%) |
| 静的 RAM | 62,712 B | 72,296 B (+9.6KB: UDP 作業領域 3KB、MQTT 退避 2KB、CommandHandler 2KB、Telemetry state 0.8KB ほか) |
| ヒープ (見積) | 空き ~205KB | −8KB (frame_pump) +6KB (solo_play 廃止) −~12KB (async_udp / PubSubClient 2KB / TCP) → ~190KB。UDP キュー 48KB と Log 退避 12KB は PSRAM |
| PSRAM | ~7.6MB 空き | −64KB 再構成 −48KB キュー −12KB 退避 |

### 実機検証手順 (未実施)

1. **solo 退行なし** (`wifi.enabled=false` または旧 config): ~~起動、再生 fps=10 miss=0、OTA (LAN)~~ →
   確認済み (2026-09-23、§9 の表)。残り: QR、停止で黒、一時停止、アップロード (PSRAM 再読み込み)、
   明るさ (見た目が暗くなる: γ2.2)、OTA (AP 経由)、`[QDIAG]` の ortho/norm が 0 付近
2. **UDP 配信のみ** (server 不要): NVS の LAN に接続した状態で PC から
   `python3 tools/stream_to_sphere.py --target <STA IP> --fps 15` → 1 フレーム以内に `source.active=network`、
   `net_fps≈15`、`reasm_drop` が増えない。Ctrl-C → 約 2 秒後にローカルへ復帰 (Playing なら続き、
   Stopped なら黒)。`/api/source {"mode":"local"}` で配信を無視、`network` でローカル停止
3. **server あり**: `/api/server {"enabled":true}` → 再起動後 STA が P2P 網に固定 IP で入る
   (`sta.origin=config`。NVS に LAN があるとそちらが勝つので `/api/wifi` を空 SSID で保存)。
   `[MQTT] connected` → server 側で online / ready → 配信開始。Web UI (AP 経由) の BRT / playback /
   led (test/off/pixels/axis) / system restart が効く。`sphere/<id>/log` に起動ログ。`[TIMESYNC] synced`
4. **OTA 両経路** (配信中): `atoms3r_ota` (AP) と `tools/ota.sh` (STA IP)。`[OTA] Start` で pump/UDP/MQTT が
   止まり、再起動後に同じモードへ戻る
5. **ソーク**: 30 分配信 + 回転。`[MEM]` heap_min、`[BOOT] Reset reason` に TASK_WDT/PANIC が無い。
   `FASTLED_RMT_MEM_BLOCKS=1` で AP+STA+UDP 下にちらつきが出れば 2 に戻す

### 残課題

- 実機確認 (上記)。特に AP チャンネル追従で iPhone が一瞬切れる挙動と、P2P 網不在時のバックオフ
- `/api/wifi` と P2P 網の共存 (NVS の LAN が常に勝つ。切り替えは Web UI で空 SSID 保存)
- 派生元 `core/` への逆流 (IMU 修正・協調停止・FLASH_LOCK) と README のポインタ
- `[RATE]/[PERF]` など solo の周期ログは `main.cpp` に残したまま (派生元の `Telemetry` に統合していない)
- `atoms3r_m5imu` env はリンク未確認 (従来どおり)

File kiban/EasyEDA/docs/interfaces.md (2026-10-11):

# インターフェースとネット定義

## 1. 電源ドメイン

| ネット | 公称レベル | 状態 | 供給元 | 負荷 | 備考 |
| --- | ---: | --- | --- | --- | --- |
| `VBAT_2S` | 約 6.0〜8.4 V | 電池接続時 | 2S LiPo | 基板B | 生のパック電圧。下限は保護設定で決まる。 |
| `VSYS` | 公称 7.4 V（約 6.0〜8.4 V） | パック / 充電器が許可しているとき | 基板B | 基板A | 基板Aへの保護済み / システム入力。全負荷で最大約 3.1 A（6.0 V 時）。BQ25792 / BQ28Z620 の正確な接続構成は要確認。 |
| `3V3_AON` | 3.3 V | 常時オン | 基板A AON レギュレータ | DRV5032FC | 静止電流は極小にすること。 |
| `3V3_MCU` | 3.3 V | システム ON | 基板A MCU 降圧 | MCU 基板、北極 LED、低電流ロジック | LTC2954 が制御する電源ドメイン。 |
| `3V3_LED` | 3.3 V | MCU が制御 | 基板A LED 降圧 | mother-ring の LED 群 | `LED_EN` でのみ有効化。左右のコネクタへ分けて給電。 |
| `CHG_IN` | 5〜12 V（推奨 12 V） | 充電器接続時 | 南極マグネット端子 | 基板B / 充電 IC | 充電中も動作が必要。`hardware_spec.md` §3.2 参照。 |

## 2. mother-ring コネクタ — 基板A

基板Aには 1×6、2.54 mm ヘッダが 2 個ある。配線前に、ピン番号を実際の EasyEDA フットプリントと機械的な向きで確認すること。

`GND_L` / `GND_R` / `GND_SYS` はコネクタ上の役割を示す名前で、電気的にはすべて同じ `GND` ネットである。回路図では1つの `GND` ネットにつなぎ、別ネットとして扱わないこと。

### 左 1×6

| ピン | ネット | 方向（基板Aから見て） | 用途 |
| ---: | --- | --- | --- |
| 1 | `3V3_LED_L` | 出力 | 左側の LED 電源。`3V3_LED_R` と同じレール。 |
| 2 | `GND_L` | 共通 | 左側の LED 帰還 / GND。 |
| 3 | `3V3_MCU` | 出力 | MCU / センサ用システム 3.3 V。 |
| 4 | `I2C_SDA` | 双方向 | 共有 I²C データ。 |
| 5 | `I2C_SCL` | MCU → デバイス | 共有 I²C クロック。 |
| 6 | `3V3_AON` | 出力 | 北極 DRV5032FC 用の常時オン電源。 |

### 右 1×6

| ピン | ネット | 方向（基板Aから見て） | 用途 |
| ---: | --- | --- | --- |
| 1 | `3V3_LED_R` | 出力 | 右側の LED 電源。`3V3_LED_L` と同じレール。 |
| 2 | `GND_R` | 共通 | 右側の LED 帰還 / GND。 |
| 3 | `GND_SYS` | 共通 | 追加の GND / 信号帰還 / 電流分散経路。 |
| 4 | `HALL_WAKE` | 入力 | 北極 DRV5032FC の出力（オープンドレイン、磁界検出時 Low）→ LTC2954 PB。 |
| 5 | `PWR_KILL` | 入力 | ESP32 → LTC2954 KILL。通常のシステムシャットダウン。基板Aで `3V3_MCU` へ 100 kΩ プルアップ。 |
| 6 | `LED_EN` | 入力 | ESP32 → LED 降圧 EN。基板A側のプルダウンでデフォルト OFF にすること。 |

### 電流分散の意図

- `3V3_LED_L` と `3V3_LED_R` は電気的に同じレールで、大電流を 2 本のピンに分ける。
- LED 負荷の最大は合計 4 A なので、LED 給電ピン 1 本あたり約 2 A を目標とする。
- 複数の GND ピンで帰還電流を分散する。
- 最終的な許容電流は、オス / メスの組み合わせ、温度上昇、PCB 銅箔、はんだ接合、mother-ring の配線形状で確認すること。

## 3. 基板A ↔ 基板B 接続

物理接続は秋月 PH-1x40SG（2.54 mm ピンヘッダ、3 A / ピン）を 1×6 に切って 2 本使い、スペーサで間隔を約 7 mm にする。組み方とピン割り当て案は `easyeda_workflow.md` §4。

最低限の論理ネット：

| ネット | 方向 | 必須 | 備考 |
| --- | --- | ---: | --- |
| `VSYS` | 基板B → 基板A | 必須 | 保護済み / パワーパス経由の電池システムレール。全負荷で 2.2 A（8.4 V）〜3.1 A（6.0 V）。3 A 以上の連続電流で選定すること。 |
| `GND` | 共通 | 必須 | 可能なら複数ピン / 広い銅箔。 |
| `I2C_SDA` | 双方向 | 必須 | MCU から充電 IC と BQ28Z620 へ届く必要がある。 |
| `I2C_SCL` | MCU → 基板B | 必須 | MCU から充電 IC と BQ28Z620 へ届く必要がある。 |
| `BATT_INT` | 基板B → MCU | 任意 | デバイスのアラート / 割り込み機能を確認し、有用な場合のみ確保。 |
| `CHG_PRESENT` | 基板B → MCU | 任意 | 可能なら I²C で状態を読む。必要な場合のみ確保。 |

重要：I²C プルアップの位置と、電源 OFF ドメインでの挙動を確認すること。基板Bには、`3V3_MCU` が OFF でも給電されたままのデバイスがある。SDA/SCL やデバイスの保護ダイオードを経由する逆給電経路を作らないこと。

## 4. 電池接続（基板B）

| コネクタ | ピン1 | ピン2 | 電流 |
| --- | --- | --- | --- |
| J_CELL1（JST XH 2P） | `B−` | `BM` | 電池電流すべて（最大 3 A 以下に制限） |
| J_CELL2（JST XH 2P） | `BM` | `B+` | 同上 |

2 セルの直列接続（J_CELL1 の `BM` と J_CELL2 の `BM`）は基板B上の銅箔で作る。この経路も 3 A 以上で設計する。詳細は `easyeda_workflow.md` §5。

## 4.1 北極インターフェース

| デバイス | 電源 | 信号 | 備考 |
| --- | --- | --- | --- |
| DRV5032FCDBZR | `3V3_AON` | `HALL_WAKE` | OFF 中も動作。全極性、オープンドレイン、20 Hz、平均 1.3 µA。 |
| WS2812C-2020-V6 | `3V3_MCU` | `LED_D6`（XIAO の D5 から 33 Ω） | 北極の LED。6 本目のストリップ（1 個）。`LED_EN` と関係なく点けられるので、起動・接続・OFF 予告などの状態表示に使える。 |
| 動作確認用の赤 LED | `3V3_AON` | `HALL_WAKE` | DRV5032FC が磁石を検出している間だけ点く（約 1.4 mA）。確認後は抵抗を外す。 |

北極基板と MCU 基板（core-XIAO-04）の間は 5 本：1 `3V3_AON`、2 `HALL_WAKE`、3 GND、4 `LED_D6`、5 `3V3_MCU`。I²C は北極へ行かない。
TMAG5273 は 2026-10-10 に廃止した。ジェスチャ（通常 OFF を含む）は MCU 基板の IMU（BNO055）によるシェイクで判定する。

## 5. 電源制御信号

### `HALL_WAKE`

- 発信元：北極の DRV5032FC（オープンドレイン、磁界検出時 Low）
- 宛先：基板Aの LTC2954 PB（内部 100 kΩ で 1.9 V へプルアップ）
- 外付けプルアップ不要。PB 直近に直列 5.1 kΩ と PB–GND 間 0.1 µF を置く
- OFF 中も有効であること
- 短い偶発的な磁気イベントで電源が切り替わらないこと
- LTC2954 のタイマで意図的な長押し判定を行う（ON 約 2.15 s、強制 OFF 約 7.8 s）

### `LED_EN`

- 発信元：ESP32-S3
- 宛先：基板Aの LED 降圧 EN
- デフォルト：OFF
- MCU が無給電・起動中・リセット中・未接続のときも LED 電源が OFF のままになるよう、ローカルのプルダウンなどのフェイルセーフバイアスを入れる

### `PWR_KILL`

- 発信元：ESP32-S3
- 宛先：LTC2954 KILL（しきい値 0.6 V、最小パルス幅 30 µs）
- 基板Aで `3V3_MCU` へ 100 kΩ プルアップ。MCU レールが立ち上がった時点で High になり、起動後 512 ms（最小 400 ms）以内の KILL 解除を満たす
- MCU が表示を落とし、必要な状態保存を終えた後にだけ Low にする
- Low にした時点（30 µs 以内）で MCU レールが切れる

## 6. GND / レイアウトの意図

- GND は任意に分割したプレーンではなく、連続した基準面を使う。
- 大電流の LED ループは、MCU / I²C / 磁気センサの帰還経路から物理的に離す。
- LED 電流は LED 降圧から左右の mother-ring LED 給電ピンへ直接流す。
- LED の帰還電流を細い MCU 側の GND 経路に流さない。

## 7. ファームウェア要件（XIAO ESP32S3）

電源ハードウェアが正しく動くために、ファームウェアが守るべき要件。

### FW-1 `PWR_KILL`

- 基板Aのプルアップにより、起動直後の KILL 解除（LTC2954 の 512 ms / 最小 400 ms 以内）はハードウェアで満たされる。ファームウェアは**起動中に `PWR_KILL` を Low に駆動しないこと**。
- `PWR_KILL` には、リセット中や起動中に Low を出力しない GPIO を割り当てる。ESP32-S3 のストラッピングピン（GPIO0 / 3 / 45 / 46）と、ブート時に内部プルダウンが有効なピンは避ける。
- ピンは入力（ハイインピーダンス）のままにするか、オープンドレイン出力の High（= 解放）で初期化する。プッシュプルで High を出してもよいが、`3V3_MCU` 以外の電源へ流れ込まないこと。
- シャットダウン時は Low を出力し、そのまま保持する（データシートの最小値は 30 µs。実装では 1 ms 以上保持してから待機ループに入る）。
- プルダウン構成に変更する場合は、ブートローダを含めて EN アサートから 400 ms 以内に High を出力する必要がある。PSRAM 初期化を含む起動時間では余裕がないため、採用しない。

### FW-2 `LED_EN` と LED データ線

- 起動時は `LED_EN` を Low のままにする。表示が必要になってから High にする。
- この節のデータ線のルールは、`3V3_LED` から給電するストリップ 1〜5（`LED_D1`〜`D5`）に適用する。北極 LED（`LED_D6`）は `3V3_MCU` から給電されるので、`LED_EN` が Low でも送ってよい。電源投入直後（ROM / ブートローダの数百 ms）はファームが制御していないので点かない（MCU 基板のプルダウンでデータ線は Low）。
- `LED_EN` を High にした後、LED レールが立ち上がるのを待ってから（目安 5 ms 以上）データを送る。
- `LED_EN` が Low の間は、LED データ出力 GPIO を Low に固定する。LED の DIN から LED レールへの逆給電を防ぐため。
- OTA 後の再起動やパニックによるリセットでも、GPIO がハイインピーダンスになるだけで、基板A側のプルダウンにより LED レールは OFF になる。
- LED 全体の電流を 4 A 以下に制限する（例：FastLED の電力制限）。WS2812C-2020-V6 は全点白の最大輝度で 800 × 15 mA = 12 A になる。
- **電池電流の上限は 2 A とする**（ユーザー決定、2026-10-08）。セルに付属の保護基板（PCM）の過電流しきい値が 3 A 前後と考えられ、2000 mAh で 3 A は 1.5C になるため。BQ28Z620 または `VSYS` の電流から電池電流を求め、上限を超えないように LED を絞る。
  電池電圧ごとの LED の電流の目安（降圧効率 90%、MCU 側 3.3 V × 1 A の最大時）：

  | 電池電圧 | 電池電力（2 A） | LED の最大電流（3.3 V） |
  | ---: | ---: | ---: |
  | 8.4 V（満充電） | 16.8 W | 約 3.6 A |
  | 7.4 V（公称） | 14.8 W | 約 3.0 A |
  | 6.4 V（放電終止） | 12.8 W | 約 2.5 A |

  PCM のしきい値は、セルの仕様書か実測で確認する（`boardB_schematic_notes.md` §4）。
- 電池電圧が低いときは LED 電流をさらに絞り、電池電流を 3 A 以下に保つ（電池コネクタ JST XH の定格。`easyeda_workflow.md` §5.2）。目安は、パック 6.8 V 未満で LED 3.5 A 以下。電池電圧は BQ28Z620 から読む。

### FW-3 シャットダウン手順

1. LED データ出力を Low に固定する
2. `LED_EN` を Low にする
3. 状態を保存する（フラッシュ書き込みの完了を待つ）
4. `PWR_KILL` を Low にして保持する

### FW-4 通常 OFF はシェイクで判定する

- 磁石は ON（約 2.15 s）と強制 OFF（約 7.8 s、最小 5.5 s）だけに使う。どちらもハードウェアで動き、ファームウェアは関与しない。強制 OFF は状態を保存しない非常用。
- 通常 OFF は、IMU（BNO055）で検出するシェイク動作で行う。トリプルシェイクは AP の ON / OFF に使っているので、OFF には別のはっきり違う動作を割り当てる（例：振ってから上下逆さに 2 s 保つ）。
- 手で持って回すことが多いので、誤検出しにくい動作にする。判定したらブザーや北極 LED で予告し、数秒以内の操作で取り消せるようにしてから FW-3 の手順に進む。
- 動作中に磁石を近づけると、離さない限り LTC2954 の強制 OFF タイマが進む。磁石を使う UI は作らない。

### FW-5 I²C

- 立ち上げ時は 100 kHz で動かす。
- 充電 IC（0x6B）、BQ28Z620、BNO055（0x28）のアドレスを起動時にスキャンし、見つからない場合はログに残す。
- I²C のピンは D9 = SCL（GPIO8）、D10 = SDA（GPIO9）。XIAO の標準（D4 / D5）ではないので `Wire.begin(9, 8)`（SDA、SCL の順）で指定する。`PWR_KILL` は D8（GPIO7）。この並びは、MCU 基板の J1 のピン順（`LED_EN`、`PWR_KILL`、SCL、SDA）に合わせたもので、配線が交差しない。プルアップは AE-BNO055-BO 内蔵の 10 kΩ。
- 基板Bのデバイスは `3V3_MCU` が OFF でも給電されている。ファームウェアは「電源 ON 直後でも充電 IC / 残量計は前回の状態を保持している」ことを前提にする。

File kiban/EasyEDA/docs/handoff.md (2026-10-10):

# 実装担当（LLM / 技術者）への引き継ぎ

## 目的

本パッケージのアーキテクチャとインターフェースに従い、次世代 Isolation Sphere の電源サブシステムを EasyEDA で実装する。構成は 40 mm × 40 mm の PCB 2 枚の積層とする。

実装では、電池の安全性、予測可能な電源シーケンス、コンパクトなレイアウト、OFF 時の低消費電流、充電中の確実な動作を優先すること。

## 以下のアーキテクチャ決定を黙って変更しないこと

1. **40 × 40 mm の基板 2 枚**を使う。
2. **基板Aは上側のシステム電源 / mother-ring 基板。**
3. **基板Bは下側の電池 / 充電 / BMS 基板。**
4. 基板Bの裏面は LiPo パウチに面するため**部品禁止**。
5. **3.3 V 降圧コンバータを 2 個に分ける**。
   - LED レール
   - MCU レール
6. LED 降圧は ESP32 が `LED_EN` で制御する。
7. MCU システム電源は **LTC2954-1** が制御する。
8. 常時オンの磁気起動には **DRV5032FC**（DRV5032FCDBZR）を使う。
9. ~~TMAG5273 で磁気ジェスチャ~~ → 2026-10-10 に廃止。通常 OFF などのジェスチャは、MCU 基板の IMU（BNO055）によるシェイクで判定する。
10. 充電 / パワーパスは **BQ25792**（昇降圧、入力 5〜12 V、推奨 12 V。`hardware_spec.md` §3）。
11. パック残量計 / 保護は **BQ28Z620**（BQ28Z610-R1 の後継、ピン互換。`hardware_spec.md` §4）。
12. 旧構成の IP2326、XR-2S-30A、MP1584、MAX16054、MAX17049 は参考資料にとどめ、回路図の基本構成にはしない。
13. 基板Aは **1×6、2.54 mm ヘッダ 2 個**と `interfaces.md` の論理ネット割り当てで mother-ring に接続する。
14. 北極の WS2812C-2020-V6 は、XIAO の D5 から直接駆動する 6 本目のストリップ（1 個、電源 `3V3_MCU`）。2026-10-10 に `line05` の 161 番目から変更。
15. LED は **WS2812C-2020-V6** を使う（確定）。

データシートの要件により、確定事項のいずれかが電気的に実現不能または危険になる場合は、黙ってアーキテクチャを変えず、作業を止めて矛盾を報告すること。

## 第1作業：一次データシートでアーキテクチャを確認する

回路図を描く前に：

1. 以下の最新の公式データシート / テクニカルリファレンスマニュアルを読む。
   - LTC2954
   - DRV5032
   - BQ25792
   - BQ28Z620（データシートとテクニカルリファレンスマニュアル）
   - 選定した LED 降圧
   - 選定した MCU 降圧
   - WS2812C-2020-V6（電源電圧 3.3〜5.3 V を確認済み。`hardware_spec.md` §8.1）
2. 以下を確認する。
   - 電圧範囲
   - ロジックレベル
   - 起動 / 停止の要件
   - 充電器のパワーパス構成
   - BQ28Z620 の保護 FET 構成
   - 電流検出シャントの要件
   - セルタップ / BM の接続
   - I²C の電源ドメインでの挙動
3. 充電器 / システム経路が**パック保護を迂回しない**ように、充電 IC と BQ28Z620 の接続を正確に決める。
4. チャットのブロック図だけで回路図を実装できると考えないこと。

## 第2作業：発注可能な部品を確定する

各 IC と主要な受動部品について、以下を揃える。

- メーカー型番
- パッケージ
- EasyEDA シンボル
- EasyEDA フットプリント
- 実装を依頼する場合は LCSC / JLCPCB 部品番号
- 在庫 / 入手性
- 必要なら Basic / Extended の区分

出典 URL / データシート付きの BOM を維持すること。

### 選定済みの部品

| 部品 | 型番 | 根拠 |
| --- | --- | --- |
| 電源 ON/OFF コントローラ | LTC2954CTS8-1 または LTC2954ITS8-1（TSOT-23-8） | `hardware_spec.md` §5 |
| ON 長押し用コンデンサ | C_ONT = 0.33 µF、X7R、±10% | 約 2.15 s |
| 強制 OFF 長押し用コンデンサ | C_PDT = 1.2 µF、X7R、±10% | 約 7.8 s |
| 常時オン磁気センサ | DRV5032FCDBZR（SOT-23） | `hardware_spec.md` §5 |
| PB 入力保護 | 直列 5.1 kΩ + PB–GND 0.1 µF | LTC2954 データシートの長配線向け推奨 |
| `PWR_KILL` プルアップ | 100 kΩ → `3V3_MCU` | `interfaces.md` §5、§7 |
| 残量計 / 保護 | BQ28Z620DRZR（VSON-12、LCSC C20345237） | `hardware_spec.md` §4 |
| 電池コネクタ | JST XH 2P × 2（セルごと） | `easyeda_workflow.md` §5 |
| ヒューズ | SMD2920P500TF/16（PTTC、LCSC C108585、リセッタブル） | `boardB_schematic_notes.md` §6 |
| 保護 FET | FS8205A（FUXINSEMI、LCSC C908265、SOT-23-6） | `boardB_schematic_notes.md` §5。採用候補（ゲート余裕が小さい） |
| 充電 IC | BQ25792RQMR（VQFN-29、LCSC C2862876） | `hardware_spec.md` §3 |
| LED | WS2812C-2020-V6（LCSC C55109522、SMD2020-4P） | 確定。VDD 3.3〜5.3 V |

### まだ最終選定が必要な部品

- 低 Iq の AON 3.3 V レギュレータ
- LED 3.3 V 降圧（5〜6 A クラス推奨）
- MCU 3.3 V 降圧（1〜2 A クラス、EN はハイアクティブ）
- BQ28Z620 の保護 MOSFET
- 電流検出シャント
- サーミスタ
- スペーサ（基板A↔B 間隔 7.0 mm 用）
- 基板Bの外形：決定（隅を 8 mm 面取りした 40 mm 角。`boardB_schematic_notes.md` §7）
- 電池の電線の経路（北のセル → 基板B）

## 第3作業：回路図の作成

### 基板Aの回路図シート

推奨シート構成：

1. `A01_INPUT_VSYS`
2. `A02_LTC2954_POWER_CONTROL`
3. `A03_AON_3V3`
4. `A04_LED_BUCK_3V3`
5. `A05_MCU_BUCK_3V3`
6. `A06_MOTHER_RING_CONNECTORS`
7. `A07_BOARD_B_INTERFACE`
8. `A08_TEST_POINTS`

必要な動作：

- `LED_EN` はローカルでデフォルト OFF になる。
- MCU 降圧の EN は LTC2954 が制御するシステム状態に従う。
- MCU と LED のレールが OFF でも `3V3_AON` は維持される。
- 制御線から無効化したレールへ逆給電しない。
- `PWR_KILL` は `3V3_MCU` へプルアップする（ESP32 のリセットで電源が落ちないようにするため）。
- LTC2954 の INT はテストパッドへ引き出す（任意）。

### 基板Bの回路図シート

推奨シート構成：

1. `B01_LIPO_CELL_CONNECTIONS`
2. `B02_BQ28Z620_GAUGE_PROTECTION`
3. `B03_PROTECTION_FETS_SHUNT`
4. `B04_CHARGER_POWERPATH`
5. `B05_SOUTH_CHARGE_INPUT`
6. `B06_BOARD_A_INTERFACE`
7. `B07_NTC_AND_TEST_POINTS`

必要な動作：

- 保護は ESP32 から独立して自律的に働く
- 充電経路が保護を迂回しない
- 外部充電入力がある状態でもシステムが動作できる
- セル中点を正しく接続する
- シャントとケルビン検出は TI のレイアウトガイドに従う

## 第4作業：PCB レイアウト

### 基板Aのレイアウト優先度

1. 40 × 40 の機械形状に合わせて、まず mother-ring コネクタを配置する。
2. LED 降圧の電流ループを極力小さくする。
3. `3V3_LED_L` と `3V3_LED_R` を大電流出力として、それぞれのコネクタ側へ直接配線する。
4. MCU 降圧と I²C / 制御回路を、LED のスイッチングノードから離す。
5. LTC2954 / AON 回路を、ノイズの多いスイッチングノードから離す。
6. 連続した GND 基準面を使い、大電流の帰還経路を意図して制御する。

### 基板Bのレイアウト優先度

1. 裏面は部品なしを保つ。
2. 電池セル接続、シャント、FET、残量計の検出配線はリファレンスレイアウトに従う。
3. 充電器のスイッチングループを小さくする。
4. 充電器と保護 FET の熱を、可能な限り LiPo 側の面から離す。
5. LiPo 側へ鋭い突起を出さない。
6. 角を丸め、最終的な機械構成で絶縁フィルムを入れる。

## 第5作業：ERC / DRC と技術確認

以下を含むレポートを作る。

- ERC 結果
- DRC 結果
- コネクタピンごとの最大想定電流
- 3.3 V / 4 A LED 出力時の `VSYS` 電流（`hardware_spec.md` §3.1 の見積りを更新）
- 変換効率の見積り
- 主要部品の損失の見積り
- 電池 OFF 時の消費電流の見積り
- 強制 OFF の動作
- 充電と動作の同時実行時の挙動
- 熱のリスクがある箇所
- I²C アドレスマップ
- 電源ドメイン / 逆給電のレビュー

## EasyEDA の自動化 / Python

Python が役立つ作業：

- BOM の生成
- ネット / インターフェースの整合性チェック
- ピン配置表
- 部品データベース / LCSC 対応表
- デザインルールのチェックリスト
- 電流 / 電力の計算
- 機械可読な設計仕様の生成

EasyEDA のプロジェクト JSON を**やみくもに生成しないこと**。EasyEDA Standard と EasyEDA Pro は内部形式が異なり、その形式は変わることがある。まず使う EasyEDA のエディション / バージョンを決め、最小のネイティブプロジェクトを書き出して中身を確認してから生成ツールを書くこと。

安全な進め方：

1. `design_spec.yaml` を正とする
2. Python で BOM / ピン配置 / 整合性レポートを生成する
3. 検証済みのライブラリ部品で EasyEDA に回路図を描く
4. テストプロジェクトで形式を確認した後に限り、EasyEDA ネイティブファイルの自動化を検討する

## 必須のレビューゲート

### ゲート1 — アーキテクチャレビュー

提出物：

- ブロック図
- 選定した IC の正確なバリアント
- 基板A ↔ 基板B コネクタの案
- mother-ring の最終的なピン番号 / 向き
- 充電入力の供給方法（12 V アダプタか USB-PD トリガか）とマグネット接点の電流定格
- LED 降圧の出力電圧（3.4〜3.5 V）と mother-ring 末端の電圧降下の見積り

承認されるまで配線に進まないこと。

### ゲート2 — 回路図レビュー

提出物：

- 基板A回路図の PDF / 画像
- 基板B回路図の PDF / 画像
- BOM
- パワーパスの説明
- 保護しきい値 / BQ28Z620 の設定計画（ブロードキャスト無効、CUV 3200 mV / セル以上）

### ゲート3 — 配置レビュー

提出物：

- 基板Aの表 / 裏の配置画像
- 基板Bの表 / 裏の配置画像
- 基板Bの裏面が平らで部品がないことの証跡
- 熱 / 大電流経路の注記

### ゲート4 — 製造前レビュー

提出物：

- ERC / DRC がクリーンなレポート
- ガーバーのプレビュー
- ドリルファイルのプレビュー
- JLCPCB を使う場合は BOM / CPL
- 試験計画

## 重要な未解決事項

推測で決めず、明示的に解決すること。

1. 充電 IC と BQ28Z620 の保護付きパワーパス構成の詳細。
2. 充電入力の供給方法（12 V アダプタか USB-PD トリガか）と、BQ25792 の入力電流上限（ILIM_HIZ）。
3. マグネット充電端子の電流定格、充電電流、入力電流制限。
4. 閉じた球体内で約 4 A を連続出力できる LED 降圧 IC とインダクタ。
5. MCU 降圧の電流目標（1 A か 1 A 超か）。
6. LED 降圧の出力電圧。WS2812C-2020-V6 の VDD 下限が 3.3 V のため、末端の電圧降下を見込んで 3.4〜3.5 V に設定する（`hardware_spec.md` §8.1）。
7. I²C プルアップのドメインと逆給電防止。
8. mother-ring コネクタの向き / 1 番ピンの規則。
9. 基板A ↔ 基板B のピン割り当て（案は `easyeda_workflow.md` §4.3）と、電池の電線の経路。

解決済み：

- EasyEDA Pro を使う。進め方は `easyeda_workflow.md`。
- 基板A ↔ 基板B の物理接続：PH-1x40SG ピンヘッダ + スペーサ。

- 残量計 IC（BQ28Z620）。
- 電池コネクタ（JST XH 2P × 2、セルごと。放電終止 6.4 V 以上）。
- 充電 IC（BQ25792）と充電入力電圧の方針（5〜12 V、推奨 12 V）。

- LTC2954 のバリアント（-1）、EN 極性、KILL 起動時の挙動、ONT / PDT の部品（`hardware_spec.md` §5）。
- DRV5032 のバリアント / 極性 / 出力形式（FC、`hardware_spec.md` §5）。磁石との距離の確認は残る。

## 実装担当に期待する成果物

- 基板A / 基板B の EasyEDA プロジェクト
- 回路図ソース
- PCB ソース
- BOM
- ピン配置 / インターフェース表
- 組立メモ
- 未解決事項すべての設計レビューノート
- 任意：仕様 / BOM / インターフェース検証用の Python ツール

すべてのレビューゲートを通過するまで、製造用ファイルを出力しないこと。

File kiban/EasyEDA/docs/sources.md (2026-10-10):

# 一次資料 / データシート確認リスト

実装の根拠には、最新のメーカー公式資料を使うこと。最終的な電気定数を、通販のモジュールページやチャットの要約に頼って決めないこと。

## LTC2954 — Analog Devices

製品ページ：
<https://www.analog.com/en/products/ltc2954.html>

データシート（Rev. B を確認）：
<https://www.analog.com/media/en/technical-documentation/data-sheets/2954fa.pdf>

確認済み（2026-10-07）：

- 選定：-1（EN ハイアクティブ、低リークのオープンドレイン）
- 電源電圧 2.7〜26.4 V、静止電流 6 µA typ / 12 µA max
- PB：内部 100 kΩ で 1.9 V へプルアップ、入力範囲 −1〜26.4 V、しきい値 0.6〜1.0 V
- ON：32 ms + C_ONT × 6.4 s/µF。式は `C_ONT[µF] = 1.56×10⁻⁴ × (t_ONT[ms] − 1)`
- 強制 OFF：64 ms + C_PDT × 6.4 s/µF
- KILL：しきい値 0.6 V、起動後のブランキング 400 / 512 / 650 ms。この間に High にならないと EN を解除する
- OFF 後は 256 ms 間 PB を無視する
- 長配線の PB には直列 5.1 kΩ と 0.1 µF を推奨

残りの確認項目：

- 選定した MCU 降圧の EN 入力との電圧整合
- LCSC での入手性

## BQ25792 — Texas Instruments（採用）

製品ページ：
<https://www.ti.com/product/BQ25792>

データシート：
<https://www.ti.com/lit/ds/symlink/bq25792.pdf>

LCSC：C2862876（BQ25792RQMR、VQFN-29）
<https://www.lcsc.com/product-detail/C2862876.html>

確認済み（2026-10-08）：

- 入力動作範囲 3.6〜24 V（絶対最大 30 V）、入力過電圧保護の初期値 26 V
- 1〜4 セル、昇降圧、NVDC、充電 最大 5 A、電池放電 6 A RMS 連続 / 10 A ピーク（1 s 以内）
- PROG 抵抗でセル数と周波数を設定。2 セルの初期値は 8.4 V・1 A
- 入力電流上限の初期値 3 A（ILIM_HIZ の抵抗で制限）
- I²C アドレス 0x6B、電池のみで動作中の静止電流 17 µA typ（ADC 無効時）
- BQ25798 とピン配置が同じ（評価ボード BQ25792EVM / BQ25798EVM を共用）

確認項目：

- 2S、12 V 入力のリファレンス回路（BQ25792EVM ユーザーガイド SLUUCB5）とインダクタ選定
- BQ28Z610 との接続構成
- 入力 1 系統で使う場合の ACDRV / SDRV の処理

ユーザーガイド：
<https://www.ti.com/document-viewer/lit/html/SLUUCB5E>

## 不採用にした充電 IC

比較は `hardware_spec.md` §3.3。

- BQ25883：<https://www.ti.com/product/BQ25883>（入力 3.9〜6.2 V。12 V 不可）
- BQ25798：<https://www.ti.com/product/BQ25798>（BQ25792 に MPPT とバックアップを加えたもの。ピン配置は同じ）

## BQ28Z620 — Texas Instruments（採用）

製品ページ：
<https://www.ti.com/product/BQ28Z620>

データシート（SLUSET3）：
<https://www.ti.com/lit/ds/symlink/bq28z620.pdf>

LCSC：C20345237（VSON-12、64 個、1 個 $6.98 / 100 個 $5.28）
<https://www.lcsc.com/product-detail/C20345237.html>

JLC の PCBA：C20345237 は Extended 部品で、Economic / Standard の両方で実装できる（JLC のページで確認、2026-10-08）。購入した部品は JLC の部品ライブラリに入り、単体では発送されない。在庫数はページに出ないため、発注時に確認する。
JLC の別の登録 C22395771 は購入不可。

確認済み（2026-10-08）：

- BQ28Z610-R1 とピン互換（VSON-12、DRZ）
- R1 からの変更点：1.2 V ロジックの I/O、保護 FET ゲート駆動 5.75 V の選択肢、1 mΩ 未満のシャントに対応、BTP 機能を削除
- SDA/SCL：推奨上限 5.5 V、絶対最大 6 V、VIH 0.78 V、VIL 0.42 V。3.3 V プルアップで使える
- I²C が約 2 秒 Low に保持されるとバスを解放する
- 設計例ではブロードキャスト（Master Mode）が有効。本設計では無効にする

データシートとテクニカルリファレンスマニュアルの両方を読むこと。

確認項目：

- 2S セル電圧検出の接続
- 保護 FET の構成とシャント / ケルビン配線
- バランスの設定
- パック設定 / 学習 / 校正の要件（bqStudio）
- I²C アドレス（0x55 を想定）
- 充電器 / システムのパワーパスとの相互作用

### 比較した品種

- BQ28Z610（無印）：<https://www.ti.com/product/BQ28Z610>。LCSC C157573。I²C タイムアウトの不具合があり、新規設計には推奨されない
- BQ28Z610-R1：<https://www.ti.com/product/BQ28Z610-R1>。無印の不具合をシリコンで修正。LCSC に無い

## JST XH（電池コネクタ）

- 2.5 mm ピッチ、3 A（AWG22）、適合電線 AWG30〜22
- 縦向きの B2B-XH-A は実装高さ 9.8 mm。基板間隔 7.0 mm に収まらないため使わない
- データシート：<https://www.digikey.be/en/resources/datasheets/jst/xh-connector>

## DRV5032 — Texas Instruments

製品ページ：
<https://www.ti.com/product/DRV5032>

確認済み（データシート SLVSDC7H）：

- 選定：**DRV5032FCDBZR**（SOT-23）
- 全極性、オープンドレイン、20 Hz、平均 1.3 µA、B_OP 最大 4.8 mT
- 磁界が B_OP を超えると出力 Low、B_RP を下回るとハイインピーダンス
- VCC 1.65〜5.5 V
- 代替：DRV5032AJ（全極性、オープンドレイン、最大 9.5 mT）

残りの確認項目：

- 使用する磁石と、北極外殻からセンサまでの距離での磁束密度

## TMAG5273 — Texas Instruments（2026-10-10 に廃止。経緯の記録として残す）

製品ページ：
<https://www.ti.com/product/TMAG5273>

確認項目：

- 測定範囲のバリアント
- I²C アドレス / オプション
- 割り込みを使うかどうか
- 北極の磁石に必要な測定範囲
- 機械設計における X/Y/Z 軸の向き

## LED 降圧の候補 — TPS56637

製品ページ：
<https://www.ti.com/product/TPS56637>

候補であり、確定部品ではない。

確認項目：

- 2S の入力範囲
- 3.3 V / 約 4 A 連続時の効率と熱
- インダクタとコンデンサの選定
- EN のロジック
- レイアウト要件
- 入手性 / EasyEDA・JLC での実装適性

## MCU 降圧の候補 — TPS62162

製品ページ：
<https://www.ti.com/product/TPS62162>

1 A 品の候補。MCU レールに 1 A を超える余裕が必要になる可能性があるため、**確定していない**。

## mother-ring コネクタ

ユーザー指定の秋月電子の候補：

- <https://akizukidenshi.com/catalog/g/g100167/>
- <https://akizukidenshi.com/catalog/g/g103784/>

PCB リリース前に確認すること：

- オス / メスの正確な組み合わせ
- 接点 1 個あたりの電流定格
- 嵌合深さ
- ピン長
- PCB の穴径
- 機械的な向きと 1 番ピンの規則
- LED 給電接点 1 個あたり約 2 A を連続で流したときの温度上昇

## LED

使用品：Worldsemi WS2812C-2020-V6（確定、LCSC C55109522）

製品ページ：
<https://www.lcsc.com/product-detail/C55109522.html>

データシート（V1.0、2026-05-21、中国語）：
<https://www.lcsc.com/datasheet/C55109522.pdf>

確認済み（2026-10-08）：

- 電源電圧 +3.3〜+5.3 V。3.3 V 動作は保証範囲内（下限ちょうど）
- VIH は 0.55 × VDD 以上、VIL は 0.7 V 以下、VI は −0.3 V〜VDD + 0.7 V
- 各色 5 mA、静止電流 1 µA 以下
- VDD に 100 nF のデカップリングを推奨

注意：旧品 WS2812C-2020（V1）は電源電圧 +3.7〜+5.3 V で、3.3 V では使えない。調達時に V6 であることを確認すること。
参考（V1 相当、秋月電子）：<https://akizukidenshi.com/goodsaffix/ws2812c-2020.pdf>

残りの確認項目：

- mother-ring 末端での電圧降下（LED 降圧の出力電圧の決定に使う）
- 電源 OFF 時のデータピンからの逆給電の挙動（実機）

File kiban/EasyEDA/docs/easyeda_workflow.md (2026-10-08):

# EasyEDA 設計の進め方

2026-10-08 に合意した方針。基板A / 基板B に加え、mother-ring と北極基板も EasyEDA Pro で作り直す。

## 1. 合意事項

| 項目 | 決定 |
| --- | --- |
| ツール | EasyEDA Pro。AI は `easyeda-api` スキルのブリッジ経由で操作する |
| 基板A / B | 1 つのプロジェクトに 2 枚のボードとして作る |
| mother-ring / 北極基板 | 作り直す。まず既存の KiCad データを EasyEDA Pro に移植し、その後で新しい電源仕様に合わせて改版する |
| 部品の配置 | **AI が行う**。人はゲート3で確認する |
| 基板A↔B 接続 | 秋月 PH-1x40SG（2.54 mm ピンヘッダ）を切って使い、スペーサで間隔を広げる（§4） |
| LiPo | 40 × 40 × 10 mm を北と南に 1 個ずつ。セルごとに JST XH 2P。直列接続と中点は基板B上で作る（§5） |
| 製造 | JLCPCB の PCBA。4 層。基板Bは表面のみ実装、基板Aも収まれば表面のみ |
| Git | 各ゲートの節目で出力物をコミットする（§7） |

## 2. 役割分担

| 作業 | 担当 | 方法 |
| --- | --- | --- |
| 部品の取り込み、在庫確認 | AI | LCSC 番号から `lib_Device.getByLcscIds()` で取り込む |
| 回路図の部品配置とネット | AI | TI の評価ボード（EVM）の回路を写す。人がゲート2で確認 |
| ネットリストと仕様の照合 | AI | `sch_Netlist.getNetlist()` の出力を `design_spec.yaml` と Python で突き合わせる |
| PCB の部品配置 | AI | §6 の配置ルールに従い、座標を計算して配置する。人がゲート3で 3D 表示を確認 |
| 配線 | 未定 | 配置が固まった時点で決める |
| DRC、BOM / CPL / ガーバー出力 | AI | `pcb_Drc.check()`、`pcb_ManufactureData` |

EasyEDA のプロジェクトファイルを直接生成しない。すべて EasyEDA 上で API を通して操作する。

## 3. 段階と作業

| 段階 | 内容 | 終了条件 |
| --- | --- | --- |
| 0. 準備 | ブリッジ接続、プロジェクト作成、JLC 4 層の設計ルール、40 mm 角・角丸の外形、ヘッダ位置の決定 | — |
| 1. 部品の確定 | 残りの部品を選ぶ（LED / MCU 降圧、AON レギュレータ、保護 FET、シャント、BQ28Z620 の入手経路）。LCSC 在庫を確認 | ゲート1 |
| 2. 回路図 | 基板B（BQ25792EVM と BQ28Z620EVM を写す）→ 基板A | ゲート2 |
| 3. 配置 | AI が配置し、電源ループと熱を確認 | ゲート3 |
| 4. 配線・検証・出力 | ERC / DRC、照合スクリプト、BOM / CPL / ガーバー | ゲート4 |
| 5. mother-ring / 北極 | KiCad から移植 → 新しいピン配置（3.3 V LED、1×6 ヘッダ）に改版 | 別途 |

### 3.1 先行事例の利用

`FPC-isolation-sphere/kiban/resized/power-2S-02/docs/` に、EasyEDA Pro を API で操作した実績と落とし穴がまとまっている。作業前に必ず読む。

- `07-easyeda-schematic-rules.md`：回路図のスタイル規約、座標と単位、API の実測上の注意
- `05-jlcpcb-fab.md`：JLCPCB 発注フロー、LCSC 部品選定ルール、実績のある LCSC 番号

主な注意点（同文書から抜粋）：

- 起動順は「ブリッジ → EasyEDA Pro」。逆にすると拡張が約 15 秒で接続をあきらめる。復旧はトップメニュー `API Gateway` → `Reconnect`
- EasyEDA Pro は Online モードで使う。半離線モードではクラウドのプロジェクトが 0 件に見える
- プロジェクト一覧の取得には `teamUuid` が必須
- 回路図の座標単位は 0.01 inch、PCB は 1 mil で、10 倍違う
- 回路図の矩形は、`create()` に渡す Y と `getAll()` が返す Y の符号が逆
- `modify()` は省略したフィールドを壊す
- ブリッジがタイムアウトしても、EasyEDA 側のスクリプトは走り続ける

回路図のスタイル規約（同文書 §1）も踏襲する。

1. 機能ブロックごとに矩形とタイトルで囲う
2. ブロック内はワイヤで直接配線する
3. ブロック間はネットポート（グローバルラベル）だけで接続する
4. GND はネットポートを使わず、ワイヤに `GND` ネット名を付ける

## 4. 基板A↔B 接続（ピンヘッダ + スペーサ）

### 4.1 使用部品

秋月 PH-1x40SG（<https://akizukidenshi.com/catalog/g/g100167/>）。必要なピン数に切って使う。

| 項目 | 値 |
| --- | --- |
| ピッチ | 2.54 mm |
| 絶縁体の高さ | 2.5 mm |
| ピン長 | 短い側 3.0 mm / 長い側 6.1 mm（全長 11.6 mm） |
| 定格電流 | 3 A / ピン |

### 4.2 組み方と間隔

ピンを基板Aに下から差し、短い側（3.0 mm）を基板Aにはんだ付けする。長い側（6.1 mm）を下へ伸ばし、基板Bのスルーホールに通す。
絶縁体と基板Bの間にスペーサ（厚さ s）を入れて間隔を広げる。

基板厚 1.6 mm として：

| スペーサ s | 基板間の間隔（2.5 + s） | 基板B裏面からのピン突出（4.5 − s） |
| ---: | ---: | ---: |
| 0 mm | 2.5 mm | 4.5 mm |
| 2.5 mm（絶縁体 1 枚分） | 5.0 mm | 2.0 mm |
| 4.0 mm | 6.5 mm | 0.5 mm |
| **4.5 mm** | **7.0 mm** | **0 mm（裏面と面一）** |
| 5.0 mm（絶縁体 2 枚分） | 7.5 mm | −0.5 mm（ピン先端が穴の中で止まる） |

- **推奨は s = 4.5 mm（間隔 7.0 mm）**。ピン先端が基板B裏面と面一になり、LiPo 側に突起が出ない。
- s = 5.0 mm（ヘッダの絶縁体を 2 枚重ねる）でもよい。ピンは基板B（1.6 mm）に 1.1 mm 入るので、はんだはスルーホールを埋めて接合する。
- 基板Bのはんだ付けは裏面（LiPo 側）から行う。はんだの盛り上がりを平らにし、絶縁フィルムで覆う。
- 間隔 7.0 mm なら、基板B表面の部品と基板A裏面の部品の高さの合計を 6 mm 程度まで使える（クリアランス 1 mm を残す）。BQ25792 のインダクタ（高さ 2〜3 mm 級）は収まる。

### 4.3 ピン割り当て案

基板Aの左右の辺は mother-ring コネクタが使う。基板A↔B のヘッダは、残りの前後 2 辺に 1 本ずつ置く。2 本に分けるのは、積み重ねたときの機械的な安定のため。

| ピン | J_AB1（電源） | J_AB2（信号） |
| ---: | --- | --- |
| 1 | `VSYS` | `I2C_SDA` |
| 2 | `VSYS` | `GND` |
| 3 | `VSYS` | `I2C_SCL` |
| 4 | `GND` | `CHG_INT`（BQ25792 INT、オープンドレイン） |
| 5 | `GND` | 予備 |
| 6 | `GND` | `GND` |

- `VSYS` は 3 ピン並列。最大約 3.1 A を 1 ピンあたり約 1.0 A に分ける（定格 3 A）。
- I²C の間に `GND` を挟み、クロストークを減らす。
- `CHG_INT` は `interfaces.md` §3 の `BATT_INT`（任意）に相当する。ESP32 側に GPIO を割り当てるかは未定。

## 5. LiPo 接続（JST XH 2P × 2、セルごと）

### 5.1 方針（2026-10-08 決定）

- LiPo にはコネクタが付いていないので、こちらで選ぶ。
- **各セルを JST XH 2P（2.5 mm ピッチ、3 A / ピン、AWG22）で基板Bにつなぐ。** 2 個使う。
- 2 セルの直列接続とセル中点 `BM` は、基板B上で作る。

| コネクタ | ピン1 | ピン2 | シルク表示 |
| --- | --- | --- | --- |
| J_CELL1 | `B−` | `BM` | `CELL1(B−/BM)` |
| J_CELL2 | `BM` | `B+` | `CELL2(BM/B+)` |

経緯：JST PH は 1 ピン 2 A で、電池電流（最大約 3.1 A）に足りない。5 ピンの PH（B+ / B+ / BM / B− / B−）なら定格内だったが、セルごとに 2P を使う方式にした。

### 5.2 定格を守る条件

直列なので、各コネクタには電池電流が全部流れる。公称 7.4 V で約 2.5 A、6.0 V で約 3.1 A になり、6.0 V では XH の 3 A を超える。次の 2 つで 3 A 以下に抑える。

1. **放電終止を 6.4 V 以上（1 セル 3.2 V 以上）にする。** BQ28Z620 の低電圧保護（CUV）とファームの両方で設定する。6.4 V なら全負荷でも約 2.9 A。
2. **電池電圧が低いときは LED 電流を制限する**（`interfaces.md` FW-2）。

基板B上のセル間接続（J_CELL1 の `BM` と J_CELL2 の `BM`）にも全電流が流れる。この銅箔は 3 A 以上で設計する。

### 5.3 誤挿入対策

- J_CELL1 と J_CELL2 は基板上で離して置き、シルクで区別する。
- XH は極性キー付きなので逆挿しは防げる。セル 1 とセル 2 の入れ違いは電気的には同じ接続になるため、危険はない。

### 5.4 基板側の形（電池配置が決まってから選ぶ）

| 案 | 内容 | 利点 | 課題 |
| --- | --- | --- | --- |
| A | 基板Bの端に横向きの S2B-XH-A を 2 個置く | 電線同士の接続が不要 | 基板の外側に嵌合部が出る。§5.5 の余地が要る |
| B | 配線パッド → 電線 → XH | 基板の面積を取らない | XH には電線同士をつなぐ純正品がないので、中継が要る |

上面に縦向きの B2B-XH-A を置く案は使わない。実装高さ 9.8 mm が、基板間隔 7.0 mm（§4.2）を超えるため。

### 5.5 重ね順と収納

重ね順（北から）：

```
MCU 基板
  ↑ ピンソケットで隙間を作る（面間 11.0 mm）
LiPo（北）  40 × 40 × 10 mm
mother-ring（赤道面、セルの部分に穴）
LiPo（南）  40 × 40 × 10 mm
  ↑ ピンソケットで隙間を作る（面間 11.0 mm）
基板A
  ↑ スペーサ（約 7 mm）
基板B
```

- この重ね順は、実機に実装済みで収納できることを確認済み（ユーザー確認、2026-10-08）。
- セルは 40 × 40 × 10 mm。mother-ring のセルの部分には穴が開いていて、上下のセルは穴の中まで入れられる。
- 面間 11.0 mm は、ソケット FH-1x6SG/RH のハウジング 8.5 mm にヘッダ PH-1x40SG の絶縁体 2.5 mm を足したもの。セル 10 mm と上下 0.5 mm ずつのすき間にちょうど合う。
- **コアの内殻は再設計してよい**（ユーザー確認、2026-10-08）。以下の結果は、内殻への要求として使う（§5.6）。

#### 配置の計算（`tools/fit_check.py`）

コアの STL（`docs/cad/`）を断面に切り、断面に現れる塊を一つずつ障害物として、基板やセルの輪郭が当たるかを調べた。結果は [`outputs/fit/fit_report.md`](../outputs/fit/fit_report.md)。
STL の説明と、断面が「島状」になる理由は [`docs/cad/README.md`](cad/README.md)。

| 部品 | 結果（現在のコア内殻） |
| --- | --- |
| 基板A（実機外形：40 mm 角 + 左右の張り出し x = ±25、y = ±9.25） | **張り出しを ±y 方向（±15° 以内）に向ければ収まる**（すき間 2.1〜2.3 mm）。±x 方向では当たる |
| 基板B（40 mm 角、A↔B 間隔 7 mm） | **40 mm 角は当たる。** 入る最大の一辺は 37.0 mm。隅を 7 mm 面取りすれば収まる（0.6 mm）。9 mm 面取りなら 1.8 mm |
| 南のセル（40×40×10） | 収まる（すき間 0.5 mm） |
| 北のセル（40×40×10） | **当たる。** z = 3.3〜10.3、x = ±20 mm の側面にある塊に接する。一辺 39.5 mm なら 0.2 mm、39 mm なら 0.5 mm のすき間 |

基板A↔B の間隔と、基板Bの収まり（本体 40 mm 角、角 R3）：

| 間隔 | 40 mm 角 | 隅を 7 mm 面取り | 入る最大の一辺 |
| ---: | --- | --- | ---: |
| 4 mm | 収まる（0.2 mm） | 2.9 mm | 40.3 mm |
| 5 mm | 当たる | 2.4 mm | 39.0 mm |
| 6 mm | 当たる | 1.7 mm | 37.9 mm |
| **7 mm** | **当たる** | **0.6 mm** | **37.0 mm** |
| 8 mm | 当たる | 0.1 mm | 35.3 mm |

南へ行くほどコアが狭まるため、間隔を広げるほど基板Bは入りにくくなる。7 mm で 40 mm 角を使うには、内殻の再設計が必要（§5.6）。
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

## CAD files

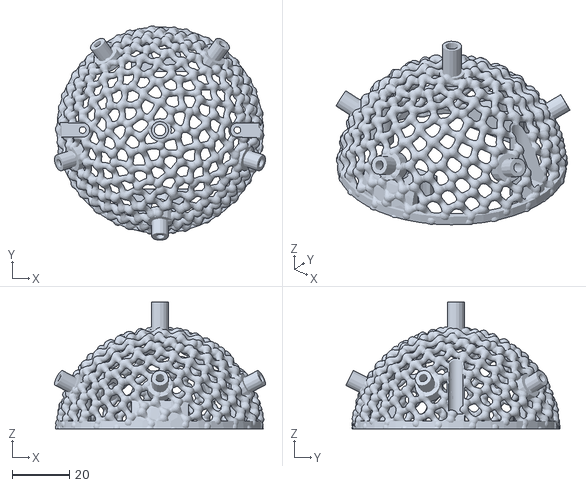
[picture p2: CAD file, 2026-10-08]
kiban/EasyEDA/docs/cad/core-south-03_fixed.stl
73.6 x 74.7 x 44.1

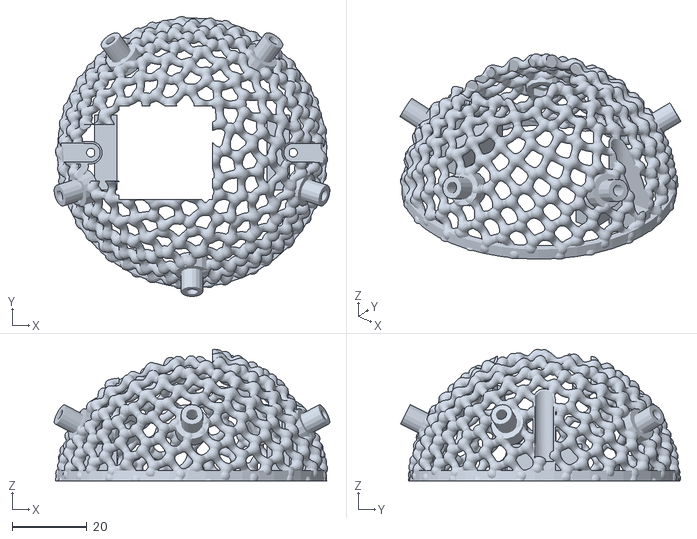
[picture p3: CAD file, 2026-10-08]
kiban/EasyEDA/docs/cad/core-north-03_fixed.stl
73.6 x 74.7 x 35.1

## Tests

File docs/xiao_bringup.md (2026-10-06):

# XIAO ESP32S3 版 立ち上げメモ

M5AtomS3R 版 (`isolation-sphere-solo`) から分岐した。コア基板を XIAO ESP32S3 で作り直す
(出発点: `FPC-isolation-sphere/kiban/core-XIAO-03`) のに合わせ、ファームも別リポジトリにした。
XIAO には LCD・本体ボタン・M5 ライブラリが無く、代わりに北極のホール素子をボタンにする。

## 分岐時にやったこと (2026-10-06)

- AtomS3R 版を履歴ごと複製し、未コミットだった省電力機能 (AP 自動停止 / モデム省電力 / トリプルシェイク切替) を作業ツリーに取り込んだ。
- 削除: `LCDManager`、`IMUManager_m5imu.cpp` と `MadgwickAHRS.h`、`board_atoms3r.h`、M5Unified 依存、`atoms3r*` の env、
  設定の LCD 項目 (`ConfigManager`)、LCD 連動コード (`main` / `DeviceController` / `SoloWebServer` / `SerialConsole` / `CommandHandler`)。
- トリプルシェイクは AP の ON/OFF 切替だけになった (`DeviceController::togglePowerSave`)。
- `pio run -e xiao_esp32s3` が通る (Flash 58.4% / RAM 21.1%)。`pio test -e native` は 68 件成功。
  **実機は未確認** (XIAO 版としては一度も書き込んでいない)。
- `data/config.json` の `features.LCD` 項目は読まれなくなったが残している (派生元との互換)。

## ボード向けリファクタリング (2026-10-06)

- ボード定義を `src/BoardConfig.h` 1 つにまとめた (`src/boards/` の振り分けと `-D BOARD_XIAO_ESP32S3` を廃止)。
- **5 ストリップ化**: `kLedPins[] = {1, 2, 3, 4, 44}`、`kLedsPerStrip = 160`。以前の XIAO 定義は 4 本で、
  5 本分の `led_layouts-5strip.csv` を読むと 5 本目の 160 個が捨てられていた。
- 5 本目は **GPIO44 (D7, 8 番パッド) で暫定**。core-XIAO-03 の回路図ではネット名が "GPIO09" だが、
  XIAO の 8 番パッドは D7 = GPIO44。基板レイアウトを再設計する予定なので、それまでこの値で進める。
- FastLED の登録は `kLedPins[]` を再帰テンプレートで展開する 1 か所にまとめた (以前は 3 か所に本数ぶん複製し `#if` で出し分け)。
- ブザーを有効化 (GPIO43 = core-XIAO-03 の LS1)。`BOARD_HAS_LCD` / `BOARD_HAS_BUZZER` / `BOARD_NUM_STRIPS` は廃止。
- `data/config.json` の LCD 項目を削除。
- 注意: `spheres[]` の MAC は AtomS3R 機 (sphere001/002) のもの。XIAO 機で server モードを使うなら MAC を登録し直す。
- 注意: build_flags の `-std=c++14` は効いていない (`std::index_sequence` が使えなかった)。C++14 の機能に依存しないこと。

## 確定した方針 (ユーザー決定)

- **GPIO**: PCA9632 (I2C) を維持して `VETO` / `PWR_OFF` を出し、GPIO はホール入力 1 本だけ追加する。
  ホール入力は RTC 対応 GPIO (D0〜D5, D8〜D10)。`HALL_OUT` は常時オン 3.3V 側なので、XIAO 未通電時の逆流防止に
  直列抵抗 (10〜100kΩ) を入れる。D6 (GPIO43, TX) は WS2812 に使わない (起動時ブートログで誤点灯する)。
  D7 (GPIO44, RX) は起動中は入力のままなので WS2812 に使える (5 本目が暫定でここ)。
  D2 (GPIO3) はストラップピンなので、ストリップに使う場合は起動時の挙動を確認する。
- **ホールボタン**: 短押し / ダブル / 長押しをファームで判定する。動作中の電源 OFF はハードの長押し (約 1.5 秒)。
  短い操作はファームのボタン。OFF→ON は今のまま (かざした瞬間に点灯)。
- **北極 RGB LED**: WS2812。データ線は mother-ring の LINE05 の最終 `DOUT` に端子を新設し、線を北極まで延ばして
  161 個目の LED として連結する。5V 振幅に整形済みの信号を受けられ、GPIO を使わない。
- **給電端子 (南極) のキャップ**: ダミープラグ型 (プラグと同じマグネット配置・接点なし・絶縁)。
  IMU は IMUPLUS (磁気不使用) なので、キャップの磁石が方位に影響する心配はない。北極ホールへの影響は
  キャップ磁石をプラグより強くしないことで抑え、実機で確認する。
- 接続案内: LCD の QR の代わりに、個体ごとの SSID (MAC 付き) を**個体シールの QR**で渡す (`tools/make_wifi_qr.py`)。

## 次にやること

1. **ボード定義の残り** (`src/BoardConfig.h`)。ホール入力 `kHallPin`、PCA9632 のアドレスを追加する。
   RMT は 4ch なので 5 本目は時分割 (`docs/solo_mode.md` §9)。5 本目のピンは基板再設計で確定させる。
2. **`HallButton`** (新規): 押下時間を測る純ロジック。イベントは Short / Double / Long (0.7〜1.4 秒)。
   1.5 秒以上はハードが電源を切るので扱わない。`test/test_hall_button` に native 単体テストを追加する (タイマーは注入)。
   操作の割り当ては未確定。叩き台: Short = 再生/一時停止、Double = AP の ON/OFF、Long = 省電力一括。
3. **`Pca9632` ドライバ** (新規): ch0 = `VETO`、ch1 = `PWR_OFF`。電源投入時は両方非アサート (boot-safe)。
4. **`StatusLed`** (新規): 北極 RGB LED で 起動 / AP 動作中 / 接続あり / 再生中 / 省電力 を表示する。
   ストリップ 5 の LED 数を 160→161 にし、161 個目は球体マッピング (`SphereMap`) と 800 個の前提から外す。
   `kMaxLeds`、FastLED の電流制限、`led_layouts` の扱いを確認する。pillar の配線は 6 本→8 本 (`DOUT05` と `V5V` を追加)。

## ハード側の宿題 (`FPC-isolation-sphere`)

- docs/06: 動作中のみ CLK を遅延させる長押し OFF 回路の改訂。
- mother-ring-03 → 次版: LINE05 の最終 `DOUT05` に端子を新設 (現状は各コネクタで終端)。`V5V` の取り出しも確認する。
- docs/08, 09: ホール信号を ESP32 へ渡す線、RGB LED の連結、給電端子キャップ、GPIO 表、pillar 配線 8 本化。
- core-XIAO-04 (仮): ホール入力のピンと抵抗を追加。core-XIAO-03 の製造発注状況を確認する。

## 開発上の注意

- CLI でビルドするときは、VS Code の PlatformIO 拡張と `.pio/build` が競合するので、
  `PLATFORMIO_BUILD_DIR` を別ディレクトリに向ける。
- AtomS3R 版の修正を取り込むときは、`git remote add atoms3r <URL>` してチェリーピックする。
  LCD・M5 に触れるコミットは取り込まない。

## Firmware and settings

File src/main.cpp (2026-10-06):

/**
 * @file main.cpp
 * @brief isolation-sphere solo: 外部 server 無しで球体単独再生するファームウェア
 *
 * 起動すると SoftAP を立て、LittleFS 上の raw MJPEG (320x160, 10fps) を自動ループ再生する。
 * 操作は iPhone を AP に接続 (個体シールの QR) し、Web UI (http://192.168.4.1/) で行う。
 *
 * server モード (config.json wifi{} 有効時) では同じファームが P2P 網にも STA で入り、
 * UDP で届く JPEG を優先表示し、MQTT で操作を受ける (配信が途切れるとローカル再生に戻る)。
 *
 * タスク構成:
 *   Core0: WiFi/lwIP, async_udp (受信→キュー), frame_pump (UDP 再構成 or ローカル MJPEG 読み
 *          → JPEG デコード。デコードは必ずこのタスク), httpd (Web UI/アップロード)
 *   Core1: LED_Render (IMU姿勢で毎パス再マッピング + RMT出力), imu (100Hz),
 *          loopTask (本ファイルの loop: OTA/ネットワーク/MQTT/ログ)
 */

#include <Arduino.h>
#include <WiFi.h>
#include "common.h"
#include "FileManager.h"
#include "ConfigManager.h"
#include "NetworkManager.h"
#include "IMUManager.h"
#include "GestureManager.h"
#include "SoundManager.h"
#include "ImageManager.h"
#include "LEDManager.h"
#include "OtaManager.h"
#include "Settings.h"

#include "SoloPlayer.h"
#include "SoloWebServer.h"
#include "DeviceController.h"
#include "SerialConsole.h"
#include "FramePump.h"
#include "UdpReceiver.h"
#include "MQTTManager.h"
#include "MqttTopics.h"
#include "CommandHandler.h"
#include "TimeSync.h"
#include "Telemetry.h"

using namespace sastle;

// グローバルデバッグフラグ (common.hでextern宣言)
bool g_debugEnabled = false;

ConfigManager config;
NetworkManager network;
IMUManager imuSensor;
GestureManager gesture;
SoundManager sound;
ImageManager imageManager;
LEDManager ledManager;
OtaManager ota;
SoloPlayer soloPlayer;
SoloWebServer soloWeb;
DeviceController controller;   // HTTP / MQTT / コンソールが共通で呼ぶ操作の窓口
SerialConsole console;
UdpReceiver udpRx;             // UDP 映像チャンク受信 (server モード時のみ listen)
FramePump pump;                // フレーム供給の単一タスク (UDP 再構成 / ローカル再生 → デコード)
MQTTManager mqtt;              // server モード: 操作受信 / imu・state・log 送信 (broker 設定時のみ)
CommandHandler commandHandler; // MQTT コマンド → DeviceController
TimeSync timeSync;             // sphere/all/clock からの共通タイムベース
Telemetry telemetry;           // imu / state の周期 publish

// MQTT メッセージ受信コールバック (mqtt.loop() 経由で loopTask のみが呼ぶ)
static void mqttCallback(char* topic, uint8_t* payload, unsigned int length) {
    // 重要: PubSubClient は送受信で同一バッファを使う。コールバック内で publish
    // (= Log の MQTT 送出やコマンド応答) を行うと受信中の topic/payload が上書き破損する。
    // 先にローカルへ退避してから処理する。2KB はスタックに積まず static。
    char topicCopy[128];
    strncpy(topicCopy, topic, sizeof(topicCopy) - 1);
    topicCopy[sizeof(topicCopy) - 1] = '\0';
    static char payloadCopy[sastle::kMqttBufferSize];
    const unsigned int len = (length < sizeof(payloadCopy) - 1) ? length : sizeof(payloadCopy) - 1;
    memcpy(payloadCopy, payload, len);
    payloadCopy[len] = '\0';

    // 時刻同期ビーコン (1 秒周期) は command 判定より先に捌き、ログも出さない
    if (strcmp(topicCopy, sastle::topics::kAllClock) == 0) {
        timeSync.onClockMessage(payloadCopy);
        return;
    }
    if (strstr(topicCopy, "/command/") != nullptr) {
        sastle::Log.printf("[MQTT] <- %s\n", topicCopy);
        commandHandler.handleMessage(topicCopy, (uint8_t*)payloadCopy, len);
    } else {
        sastle::Log.printf("[MQTT] unhandled topic %s: %s\n", topicCopy, payloadCopy);
    }
}

// 接続案内の文字列 (LCD が無いので起動ログにだけ出す。QR は個体シールで渡す: tools/make_wifi_qr.py)
static String g_wifiQrText;
static String g_apSsid;
static String g_uiUrl;

unsigned long lastIMULog = 0;
const unsigned long IMU_LOG_INTERVAL = 3000; // 3秒に1回ログ出力
unsigned long lastPerfLog = 0;
const unsigned long PERF_LOG_INTERVAL = 2000; // 2秒に1回 性能計測ログ

// Grove I2C バスを走査して検出アドレスを出す (診断用)。
// BNO055 は ADR ピンにより 0x28 (L) / 0x29 (H) に応答する。
static void scanI2cBus(uint8_t sda, uint8_t scl) {
    // 100kHz で走査する。BNO055 はクロックストレッチが長く 400kHz では化ける。
    // Wire.begin は 2 回目以降は周波数を再設定しないため、ここが実効クロックになる。
    Wire.begin(sda, scl, 100000);
    delay(50);

    sastle::Log.printf("\n[I2C] Scanning bus (SDA=GPIO%u, SCL=GPIO%u)\n", sda, scl);

    int found = 0;
    bool bnoFound = false;
    for (uint8_t addr = 0x08; addr <= 0x77; ++addr) {
        Wire.beginTransmission(addr);
        if (Wire.endTransmission() == 0) {
            ++found;
            const bool isBno = (addr == 0x28 || addr == 0x29);
            if (isBno) {
                bnoFound = true;
            }
            sastle::Log.printf("[I2C]   found 0x%02X%s\n", addr, isBno ? "  <- BNO055" : "");
            delay(2);
        }
    }

    sastle::Log.printf("[I2C] Scan done: %d device(s), BNO055(0x28/0x29)=%s\n",
                       found, bnoFound ? "PRESENT" : "ABSENT");
}

void setup() {
    // 最優先: LED即時消灯。WS2812は起動中のデータ線ノイズでランダム点灯
    // (白=フル電流もあり得る) し、電源が引き倒されて起動に失敗する事象があるため、
    // 何よりも先に全ストリップへ黒を送信する。
    LEDManager::earlyBlank();

    // シリアル初期化。Log の退避バッファ (PSRAM) も同時に用意する。server モードで MQTT に
    // 繋がると、ここ以降の起動ログがまとめて sphere/<id>/log に流れる。
    Serial.begin(115200);
    sastle::Log.begin();

    // Sound初期化を最優先で行い、起動音を即再生する。
    // 理由: WiFi/IMU初期化が終わるまでLED表示は数秒かかるため、
    // 電源スイッチが正しくONになったかをすぐ確認できるよう、
    // 他の初期化より前に音でフィードバックする。
    bool soundReady = sound.begin(config);
    if (soundReady) {
        sound.playEffect(SoundEffect::STARTUP);
    }

    // シリアルモニタ接続待ち。USB ホストが繋がっているときだけ短く待つ (起動ログの先頭を
    // 取りこぼさないため)。電池駆動 (ホスト無し) では待たない。
    if (Serial.isConnected()) {
        delay(300);
    }

    if (!soundReady) {
        sastle::Log.println("Sound initialization failed (continuing without sound)");
    }

    sastle::Log.println("\n\n=== Isolation Sphere (solo) ===");

    // 直前のリセット理由を記録 (勝手な再起動の原因切り分け用)
    // 1=POWERON 3=SW 4=PANIC 5/6=WDT 7=TASK_WDT 9=BROWNOUT (esp_reset_reason_t)
    {
        esp_reset_reason_t rr = esp_reset_reason();
        const char* rrName;
        switch (rr) {
            case ESP_RST_POWERON:  rrName = "POWERON"; break;
            case ESP_RST_SW:       rrName = "SW_RESTART"; break;
            case ESP_RST_PANIC:    rrName = "PANIC"; break;
            case ESP_RST_INT_WDT:  rrName = "INT_WDT"; break;
            case ESP_RST_TASK_WDT: rrName = "TASK_WDT"; break;
            case ESP_RST_WDT:      rrName = "WDT"; break;
            case ESP_RST_BROWNOUT: rrName = "BROWNOUT"; break;
            case ESP_RST_DEEPSLEEP:rrName = "DEEPSLEEP"; break;
            default:               rrName = "OTHER"; break;
        }
        sastle::Log.printf("[BOOT] Reset reason: %d (%s)\n", (int)rr, rrName);
    }

    // PSRAM初期化確認
    if (psramFound()) {
        sastle::Log.printf("PSRAM found: %d bytes\n", ESP.getPsramSize());
        sastle::Log.printf("Free PSRAM: %d bytes\n", ESP.getFreePsram());
    } else {
        sastle::Log.println("PSRAM not found");
    }

    // LittleFS初期化
    sastle::Log.println("\n=== Initializing LittleFS ===");
    // LittleFS が壊れていても停止しない。SoftAP と OTA を必ず立ち上げ、無線で書き戻せる
    // 状態を保つ (組み立て後は USB 端子に触れないため、ここで止まると復旧手段が無くなる)。
    const bool fsReady = FileManager::begin();
    if (!fsReady) {
        sastle::Log.println("FileManager initialization FAILED "
                            "(no video / uploads disabled, but SoftAP+OTA will start)");
    } else {
        FileManager::printInfo();
    }

    // ConfigManager初期化とロード
    sastle::Log.println("\n=== Loading Configuration ===");
    // 同様に、設定が読めなくても停止しない。ConfigManager の各 getter は
    // コンパイル時の既定値 (320x160 / SoftAP 既定 SSID など) を返す。
    if (!fsReady || !config.loadConfig("/config.json")) {
        sastle::Log.println("Failed to load config (using compiled-in defaults)");
    }
    config.printConfig();

    // UI で変えた設定 (明るさ等) を NVS から復元する
    sastle::Settings::begin();

    // Wi-Fi を立てる: STA (NVS の LAN > config の P2P 網) を先行させ、SoftAP を常に立てる。
    // 失敗しても停止しない (動画があれば iPhone 無しでも自動再生する要件)。
    SoloConfig soloCfg = config.getSoloConfig();
    IPAddress apIp;
    if (!apIp.fromString(soloCfg.ap_ip)) {
        apIp = IPAddress(192, 168, 4, 1);
    }
    // 省電力設定 (モデム省電力 / AP 無操作自動停止) は無線を立てる前に入れる。
    network.setModemSleep(sastle::Settings::modemSleep(false));
    network.setApIdleTimeoutMin(sastle::Settings::apIdleMinutes(DeviceController::kDefaultApIdleMin));
    if (!network.begin(config)) {
        sastle::Log.println("SoftAP start FAILED (playback continues without Web UI)");
    }
    // 起動ログに出す接続情報 (シール用 QR の元になる文字列)。
    g_apSsid = soloCfg.ap_ssid;
    g_wifiQrText = NetworkManager::wifiQrText(soloCfg.ap_ssid, soloCfg.ap_password);
    g_uiUrl = "http://" + apIp.toString() + "/";
    sastle::Log.printf("[SOLO] Wi-Fi QR: %s  UI: %s\n", g_wifiQrText.c_str(), g_uiUrl.c_str());

    // OTA (espota) 初期化: AP が立った直後に受け口を開く。これ以降の初期化
    // (IMU / LED / 再生 / Web) で失敗・停止しても、無線での書き戻しは生き残る。
    // stopRenderTask() は _taskRunning ガードがあるため未初期化でも安全。
    ota.begin(&ledManager, &pump, &soloPlayer, config.getSphereID().c_str(), &mqtt);

    // IMU初期化前に I2C バスを走査 (BNO055 の有無を切り分けるため)
    scanI2cBus(kImuI2cSda, kImuI2cScl);

    // IMU初期化
    if (!imuSensor.begin(config)) {
        sastle::Log.println("IMU initialization failed (continuing without IMU)");
    } else {
        imuSensor.setSmoothFrames(sastle::Settings::imuSmoothFrames(config.getImuSmoothFrames()));
        sastle::Log.printf("IMU smoothing: %u frame(s)\n", imuSensor.smoothFrames());
        imuSensor.printStatus();
    }

    // ジェスチャー初期化 (サウンドフィードバック付き)
    if (imuSensor.isInitialized()) {
        if (!gesture.begin(imuSensor, &sound)) {
            sastle::Log.println("Gesture initialization failed");
        }
    } else {
        sastle::Log.println("Gesture disabled (IMU not available)");
    }

    // ImageManager初期化 (PSRAM トリプルバッファ)
    if (!imageManager.begin(config)) {
        sastle::Log.println("ImageManager initialization failed (continuing without image)");
    } else {
        imageManager.printStats();

        // フレーム供給タスク (Core0)。UDP 受信より先に立てる: server は球体の MQTT status を
        // 見た瞬間に配信を始めるので、受け側 (キュー + デコード) が先に居ないと起動直後の
        // フラッドで詰まる (派生元の知見)。server 無効時は単にローカル再生の締切を回す。
        FramePump::Deps pd;
        pd.image = &imageManager;
        pd.player = &soloPlayer;
        pd.udp = &udpRx;
        if (pump.begin(pd, config.getSourceConfig())) {
            // 優先度 2: httpd (prio 1) より上にして、/api/status の JSON 組み立てや
            // アップロード受信にデコードが割り込まれないようにする (締切 100ms の保護)
            pump.startTask(0, 2, 8192);
        } else {
            sastle::Log.println("FramePump initialization failed (no frame source)");
        }
        if (config.isServerConfigured()) {
            // listen は ANY にバインドするので STA 接続前でも開ける
            const WiFiConfig wcfg = config.getWiFiConfig();
            if (!udpRx.begin((uint16_t)wcfg.udp_port, config.getSourceConfig().udp_queue_len)) {
                sastle::Log.println("UDP receiver failed to start (network video disabled)");
            }
        }

        // ローカル動画を開く (動画全体を PSRAM に読み込む。3MB で数秒)。描画タスクを起動する前に
        // 行い、フラッシュ操作ロックの取り合いで読み込みが遅くなるのを避ける。
        if (!soloPlayer.begin(config, imageManager)) {
            sastle::Log.println("SoloPlayer initialization failed");
        }
    }

    // LEDManager初期化 (IMUManager連携)
    if (imageManager.isInitialized()) {
        IMUManager* imuPtr = imuSensor.isInitialized() ? &imuSensor : nullptr;
        if (!ledManager.begin(config, imageManager, imuPtr)) {
            sastle::Log.println("LEDManager initialization failed (continuing without LED)");
        } else {
            ledManager.printStatus();

            // 起動オープニングパターン (config でスキップ可)
            if (config.getOpeningActionEnabled()) {
                ledManager.playOpening(config.getOpeningActionDurationMs());
            } else {
                ledManager.fillSolid(0, 0, 0);
                ledManager.show();
            }

            // 明るさ (NVS > config.params、γ=2.2) と軸表示は controller.begin() が適用する

            // レンダリングタスク開始 (Core 1)
            if (!ledManager.startRenderTask(1, 2, 8192)) {
                sastle::Log.println("Failed to start LED render task");
            }
        }
    } else {
        sastle::Log.println("LEDManager disabled (ImageManager not available)");
    }

    // 操作の窓口。起動時の明るさ/軸表示を LED に適用し、以降は Web UI / MQTT / コンソールが
    // ここを通して操作する (明るさは γ=2.2 で LED 値に変換、変更は NVS に保存)。
    {
        DeviceController::Deps deps;
        deps.config = &config;
        deps.player = &soloPlayer;
        deps.led = &ledManager;
        deps.imu = imuSensor.isInitialized() ? &imuSensor : nullptr;
        deps.net = &network;
        deps.pump = &pump;
        deps.mqtt = &mqtt;
        deps.image = &imageManager;
        controller.begin(deps);
        // トリプルシェイク = デモ向けの AP の ON/OFF 切替 (UI モードの代わり)
        gesture.setOnTripleShake([]() { controller.togglePowerSave(); });
        console.begin(controller, g_apSsid);
    }

    // Web UI を開始。再生 (FramePump) は PSRAM 上の動画を 100ms 締切でデコードし、描画 (Core1)
    // とはトリプルバッファ経由で独立に動く。
    if (imageManager.isInitialized()) {
        if (network.isSoftAP()) {
            if (!soloWeb.begin(controller, config, soloPlayer, ledManager, network, imuSensor,
                               config.getSoloHttpPort(), &udpRx)) {
                sastle::Log.println("Web server failed to start");
            }
        }
    }

    // server モード: MQTT。受け側 (FramePump + UDP キュー) はこの時点で既に動いている。
    // server は球体の status/state を見た瞬間に配信を始めるので、MQTT は最後に立てる。
    // 接続自体は STA が繋がってから mqtt.loop() が行う (起動直後は STA 未接続のことがある)。
    if (config.isServerConfigured()) {
        mqtt.setCallback(mqttCallback);
        if (mqtt.begin(config)) {
            sastle::Log.setSink(&mqtt, "log");   // 起動ログの退避分もここから流れる
            commandHandler.begin(&controller);
            gesture.setEventSink([](const char* suffix, const char* json) {
                mqtt.publishDevice(suffix, json, false);
            });
            telemetry.begin(imuSensor.isInitialized() ? &imuSensor : nullptr, &mqtt, &timeSync,
                            &controller, config.getTelemetryImuHz());
        }
    } else {
        sastle::Log.println("server mode: off (config wifi{} disabled or no SSID) - MQTT/UDP not started");
    }

    // IMU ポーリングを専用タスク (core1, 優先度3) で回す。IMU 初期化の後・setup の最後に置く
    // (以前は ota.begin() の直前 = IMU 初期化より前に置いてしまい、isInitialized() が false で
    //  一度も起動していなかった。loop のフォールバックで 40/s しか出ていなかった原因)。loopTask (優先度1) から呼ぶと
    // ログ出力などで周期が乱れ (実測 中央値 22ms、最大 240ms)、描画が古い姿勢のまま
    // 止まって「ジャンプ」に見える。描画 (優先度2) より先に走るので定刻を守れる。
    if (imuSensor.isInitialized()) {
        if (!imuSensor.startTask(1, 3, 4096)) {
            sastle::Log.println("Failed to start IMU task (fallback: loop polling)");
        }
    }

    sastle::Log.println("\n=== Setup Complete ===");
}

// 性能計測ログ (2秒間隔): 描画/デコード時間と再生統計
static void logPerfIfDue(unsigned long now) {
    if (now - lastPerfLog < PERF_LOG_INTERVAL) {
        return;
    }
    lastPerfLog = now;

    LEDStats led = ledManager.getStats();
    ImageStats img = imageManager.getStats();
    SoloPlayer::Stats s = soloPlayer.stats();

    // 姿勢の鮮度: 「前フレームと同じ姿勢で描いたフレーム」の割合。
    // これが高いほど IMU のレートが描画に追いついていない = カクつく。
    static uint32_t s_prevRendered = 0, s_prevStale = 0;
    const uint32_t dRendered = led.frames_rendered - s_prevRendered;
    const uint32_t dStale = led.imu_stale_frames - s_prevStale;
    s_prevRendered = led.frames_rendered;
    s_prevStale = led.imu_stale_frames;
    const float stalePct = dRendered ? (100.0f * dStale / dRendered) : 0.0f;

    // 姿勢データの健全性診断。ortho/norm が 0 でなければ渡っている quat が壊れている
    // (非正規化 or torn read)。step は 1 フレームあたりの回転角の最大。
    sastle::Log.printf("[QDIAG] ortho_max=%.6f norm_max=%.6f step_max=%.2fdeg\n",
                       led.imu_ortho_err_max, led.imu_norm_err_max, led.imu_step_deg_max);
    ledManager.resetImuDiag();

    const FramePump::Stats ps = pump.stats();
    sastle::Log.printf(
        "[PERF] render_fps=%.1f map=%luus out=%luus stale=%.0f%% | img_fps=%.1f decode=%luus jpeg=%uB drop=%lu "
        "| src=%s net_fps=%.1f udp=%lu reasm_drop=%lu pump_stack=%lu | heap=%u\n",
        led.fps, (unsigned long)led.mapping_time_us, (unsigned long)led.output_time_us,
        stalePct,
        img.fps, (unsigned long)img.decode_time_us, (unsigned)img.last_jpeg_size,
        (unsigned long)imageManager.getDropped(),
        pump.activeSourceName(), ps.netFps, (unsigned long)udpRx.received(), (unsigned long)ps.reasmDropped,
        (unsigned long)ps.stackMinWords, (unsigned)ESP.getFreeHeap());
    sastle::Log.printf(
        "[SOLO] state=%s fps=%.1f frames=%lu loops=%lu miss=%lu decode_err=%lu read=%luus tick=%luus clients=%u\n",
        soloPlayer.stateName(), s.fps, (unsigned long)s.frames, (unsigned long)s.loops,
        (unsigned long)s.deadlineMisses, (unsigned long)s.decodeErrors,
        (unsigned long)s.lastReadUs, (unsigned long)s.lastTickUs,
        (unsigned)network.clientCount());
}

void loop() {
    // --- 実効レート計装 (5秒ごと) ---
    {
        static uint32_t s_loops = 0, s_pReads = 0, s_pFails = 0, s_pDisc = 0;
        static unsigned long s_lastRate = 0;
        s_loops++;
        unsigned long nowR = millis();
        if (nowR - s_lastRate >= 5000) {
            uint32_t rt = imuSensor.debugReadTotal(), rf = imuSensor.debugReadFails(),
                     rd = imuSensor.debugDiscards(), rz = imuSensor.debugZeroReads(),
                     rp = imuSensor.debugPartialReads(), rs = imuSensor.debugStraddles();
            static uint32_t pRz = 0, pRp = 0, pRs = 0;
            const float dtR = (nowR - s_lastRate) * 0.001f;
            sastle::Log.printf("[RATE] loop=%.0f/s imu_read=%.0f/s fail=%.0f/s disc=%.0f/s zero=%.0f/s partial=%.0f/s straddle=%.0f/s "
                               "i2c=%lukHz word=%d smooth=%u seq=%lu\n",
                               s_loops / dtR,
                               (rt - s_pReads) / dtR, (rf - s_pFails) / dtR, (rd - s_pDisc) / dtR, (rz - pRz) / dtR,
                               (rp - pRp) / dtR, (rs - pRs) / dtR,
                               (unsigned long)(imuSensor.i2cClock() / 1000), imuSensor.wordRead() ? 1 : 0,
                               (unsigned)imuSensor.smoothFrames(), (unsigned long)imuSensor.quatSeq());
            pRz = rz; pRp = rp; pRs = rs;
            // IMU タスクが退避した診断スナップショットをここで吐く (タスク側は Log を呼ばない)
            {
                uint8_t raw[8]; float n2; uint8_t reg; uint32_t hz; bool okR, autoR;
                if (imuSensor.takeDiagClockChanged(hz)) sastle::Log.printf("[IMU] I2C clock -> %lu kHz\n", (unsigned long)(hz / 1000));
                if (imuSensor.takeDiagReset(okR, autoR)) sastle::Log.printf("[IMU] sensor re-init (%s) %s\n", autoR ? "AUTO: discard ratio >50% for 4s" : "manual", okR ? "OK" : "FAILED");
                if (imuSensor.takeDiagReadFail(raw)) sastle::Log.printf("[IMU] quat read failed, raw=%02X %02X %02X %02X %02X %02X %02X %02X\n", raw[0], raw[1], raw[2], raw[3], raw[4], raw[5], raw[6], raw[7]);
                if (imuSensor.takeDiagDiscard(raw, n2)) sastle::Log.printf("[IMU] Discarded quat |q|^2=%.3f raw=%02X%02X %02X%02X %02X%02X %02X%02X\n", n2, raw[1], raw[0], raw[3], raw[2], raw[5], raw[4], raw[7], raw[6]);
                if (imuSensor.takeDiagVecPartial(reg, raw)) sastle::Log.printf("[IMU] vec reg=0x%02X partial raw=%02X%02X %02X%02X %02X%02X\n", reg, raw[1], raw[0], raw[3], raw[2], raw[5], raw[4]);
                static char dumpHex[200]; uint16_t idx0;
                for (int k = 0; k < 3 && imuSensor.takeRawDumpLine(dumpHex, sizeof(dumpHex), idx0); k++) sastle::Log.printf("[DUMP] %u %s\n", (unsigned)idx0, dumpHex);
            }
            s_loops = 0; s_pReads = rt; s_pFails = rf; s_pDisc = rd;
            s_lastRate = nowR;
        }
    }

    // OTA 要求を最優先で処理。書き込みセッション中は handle() が転送完了まで
    // ブロックするため、描画・再生は自然に停止する。
    ota.handle();

    // キャプティブポータル DNS の応答と、HTTP 経由の再起動要求の実行
    network.poll();   // STA 接続状態の変化をログに出し、切断時はバックオフ再接続
    mqtt.loop();      // keep-alive / 受信 / STA 接続後の (再) 接続 (server 未設定なら即 return)
    sastle::Log.loop();   // 退避ログを MQTT へ (sink 未登録なら即 return)
    soloWeb.loop();
    controller.tick();    // 設定の遅延保存と予約済み再起動

    // シリアルコンソール
    console.poll();

    // IMU更新
    unsigned long now = millis();
    if (imuSensor.isInitialized()) {
        if (!imuSensor.taskHandle()) {
            imuSensor.update();   // タスク起動に失敗したときだけ loop で読む
        }

        // ジェスチャー検出更新
        gesture.update();

        // 診断ログ (3秒に1回)
        if (now - lastIMULog >= IMU_LOG_INTERVAL) {
            lastIMULog = now;
            float w, x, y, z;
            if (imuSensor.getQuaternion(w, x, y, z)) {
                float gx, gy, gz, ax, ay, az;
                imuSensor.getGyro(gx, gy, gz);
                imuSensor.getAccel(ax, ay, az);
                uint8_t cs, cg, ca, cm;
                imuSensor.getCalibration(cs, cg, ca, cm);
                imu::Vector<3> eul = imuSensor.getEuler();
                sastle::Log.printf(
                    "[IMU] q=(%.3f,%.3f,%.3f,%.3f) eul=(%.1f,%.1f,%.1f) gyro=(%.2f,%.2f,%.2f) acc=(%.1f,%.1f,%.1f) cal=%u%u%u%u mode=%u\n",
                    w, x, y, z, (float)eul.x(), (float)eul.y(), (float)eul.z(),
                    gx, gy, gz, ax, ay, az, cs, cg, ca, cm, imuSensor.getOperationMode());
            }
        }
    }

    // 性能計測ログ
    logPerfIfDue(now);

    // server モードの周期 publish (MQTT 接続中のみ)
    telemetry.publishImuIfDue((uint32_t)now);
    telemetry.publishStateIfDue((uint32_t)now);
    telemetry.emitTimeSyncIfDue((uint32_t)now);

    delay(10);
}

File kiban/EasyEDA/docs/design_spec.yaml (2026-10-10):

# Isolation Sphere 電源システムの機械可読サマリ。
# キーとネット名は英語のまま（スクリプトから参照するため）。説明文は日本語。
# 人が読む根拠は README.md と docs/*.md を参照。

project:
  name: isolation-sphere-power
  revision: architecture-baseline-2026-10-07
  status: adopted  # 2026-10-07 採用。kiban/power-2s は参考資料扱い
  pcb_tool: EasyEDA
  pcb_tool_edition: Pro  # 進め方は easyeda_workflow.md

battery_connection:
  connector: JST XH 2P x 2  # セルごと、3 A / ピン、AWG22
  J_CELL1: [B-, BM]
  J_CELL2: [BM, B+]
  series_link_on_board_B: true
  discharge_cutoff_V_min: 6.4  # 1 セル 3.2 V。XH の 3 A を守るため
  fits_core_03: true  # 実機で収納確認済み（2026-10-08）。内殻は再設計してよい
  cell_mm: [40, 40, 10]
  core_inner_shell_redesign_allowed: true
  board_a_tab:  # ピンソケット 1x6（FH-1x6SG/RH）を載せる張り出し。向きは ±y（±15°）
    socket_center_x: 22.86
    x_out: 24.63
    half_y: 8.12
    legacy: {x_out: 25.0, half_y: 9.25}
  board_b_outline:  # 決定（2026-10-08）：隅を面取りした 40 mm 角。A↔B 7 mm で内殻に当たらない最小は 7 mm
    side: 40
    corner_chamfer: 8  # すき間 1.3 mm、面積 92%
    alternatives_rejected: [{side: 37.0}]
  stack_order_north_to_south: [MCU, LiPo_N, mother_ring, LiPo_S, board_A, board_B]
  stack_gap_parts: Akizuki FH-1x6SG/RH (socket, 8.5 mm housing)

battery:
  chemistry: LiPo
  series_cells: 2
  cell_capacity_mAh: 2000
  pack_capacity_mAh: 2000
  nominal_pack_voltage_V: 7.4
  full_charge_voltage_V: 8.4
  nominal_energy_Wh: 14.8
  cell_midpoint_available: true

power_budget:
  battery_current_limit_A: 2.0  # ユーザー決定（2026-10-08）。セルの PCM と 1.5C を避けるため
  led_current_at_limit_A: {at_8V4: 3.6, at_7V4: 3.0, at_6V4: 2.5}
  led_output_W: 13.2   # 3.3 V × 4 A
  mcu_output_W: 3.3    # 3.3 V × 1 A
  assumed_buck_efficiency: 0.90
  vsys_input_W: 18.3
  vsys_nominal_V: 7.4
  vsys_current_A:
    at_8V4: 2.2
    at_7V4: 2.5
    at_6V0: 3.1
  design_continuous_current_A: 3.0  # 基板間コネクタ・保護 FET・BATFET の下限
  full_load_runtime_min: 48

charging:
  input_voltage_range_V: [5, 12]
  recommended_input_V: 12
  input_connector: 南極マグネット接点
  operation_while_charging_required: true
  charger: BQ25792RQMR  # 2026-10-08 確定、LCSC C2862876、VQFN-29
  charger_pin_compatible_alternative: BQ25798
  charger_prog_resistor: 2S  # 1.5 MHz=6.04k / 750 kHz=8.2k
  autonomous_default_charge: {vreg_V: 8.4, ichg_A: 1.0, iindpm_A: 3.0, vac_ovp_V: 26}
  watchdog_default_s: 40
  required_input_power_full_load_plus_1A_charge_W: 29
  charge_current_A: TBD
  input_current_limit_A: TBD

board_a:
  role: system_power_and_mother_ring_interface
  size_mm: [40, 40]
  position: upper
  component_sides: both
  functions:
    - LTC2954 電源制御
    - 3V3_AON 低 Iq レギュレータ
    - LED 用 3.3 V 降圧
    - MCU 用 3.3 V 降圧
    - mother-ring への電源分配
    - 基板B インターフェース
  power_control:
    baseline_controller: LTC2954-1
    package: TSOT-23-8
    supply_net: VSYS
    en_polarity: active_high_open_drain
    c_ont_uF: 0.33
    c_pdt_uF: 1.2
    on_hold_s: {nominal: 2.15, min: 1.5, max: 2.8}
    forced_off_hold_s: {nominal: 7.8, min: 5.5, max: 10.0}
    kill_on_blanking_ms: {min: 400, typ: 512, max: 650}
    en_lockout_after_off_ms: {min: 200, typ: 256, max: 325}
    kill_pullup: 100k_to_3V3_MCU
    pb_input_network: series_5k1_and_100nF_to_GND
    int_output: test_pad_optional
    wake_sensor: DRV5032FCDBZR
    normal_off_sensor: BNO055_shake_via_ESP32  # TMAG5273 は 2026-10-10 に廃止
    forced_off: LTC2954_hardware_long_hold
  led_buck:
    output_V: 3.3
    expected_load_A: 3.0
    desired_system_capacity_A: 4.0
    preferred_converter_class_A: 5_to_6
    enable_net: LED_EN
    default_enable_state: off
    exact_part: TBD
    candidate: TPS56637
  mcu_buck:
    output_V: 3.3
    target_current_A: 1_to_2
    enable_control: LTC2954_EN
    enable_polarity: active_high
    exact_part: TBD

board_b:
  role: battery_charge_bms
  fuse:  # 決定（2026-10-08）：リセッタブル。球体を開けずに復帰できることを優先
    part: SMD2920P500TF/16
    manufacturer: PTTC
    lcsc: C108585
    package: 2920
    ihold_A: 5.0
    itrip_A: 10.0
    vmax_V: 16
    tripped_power_W: 2.0
    placement: B_plus_series_near_J_CELL2_away_from_LiPo
    rejected: [{part: SF-1206S500-2, lcsc: C913282, reason: one_time}]
  protection_fet:
    part: FS8205A
    manufacturer: FUXINSEMI
    lcsc: C908265
    package: SOT-23-6
    config: dual_N_common_drain
    vgs_max_V: 12
  size_mm: [40, 40]
  position: lower_lipo_side
  component_sides:
    top: allowed
    bottom: forbidden
  charger: BQ25792
  gauge_protector: BQ28Z620DRZR  # 2026-10-08 確定。BQ28Z610-R1 の後継、ピン互換
  gauge_lcsc: C20345237  # 64 個（2026-10-08）。JLC 登録 C22395771 は購入不可
  gauge_settings: {broadcast: disabled, cuv_mV_per_cell_min: 3200}
  functions:
    - 2S 充電
    - パワーパス
    - 残量計測
    - 自律的な電池保護
    - 電流測定
    - セルバランス
  external_components:
    - protection_FETs
    - current_shunt
    - thermistors
    - charger_inductor
  lipo_side_rules:
    no_components: true
    avoid_exposed_test_pads: true
    prefer_tented_vias: true
    rounded_corners: true
    insulating_film_required: true
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

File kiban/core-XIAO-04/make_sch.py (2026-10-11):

#!/usr/bin/env python3
"""core-XIAO-04（MCU 基板）と north-pole-04（北極基板）の回路図を作る。基板A / B と同じ書き方の 1 枚の回路図。

【注意】core-XIAO-04 の回路図は、2026-10-11 に確定した（以後は KiCad で直接編集する）。
このスクリプトを core-XIAO-04 に対して実行すると、KiCad での変更（J4 / J5 / TP3 / TP4、注記、PWR_FLAG など）が消える。
実行してよいのは、回路図を最初から作り直すときだけ。north-pole-04 も、確定したら同じ扱いにする。

  python3 kiban/core-XIAO-04/make_sch.py [core-XIAO-04] [north-pole-04]   # 名前を省くと両方

KiCad で回路図を開いていないときに実行する。出力（基板ごと）：
- <名前>.kicad_sch（回路図）、<名前>.kicad_pro（基板B の設計ルールを引き継ぐ。既にあれば触らない）
共通：core-XIAO-04.kicad_sym（XIAO とブザーの記号）、lib/lcsc.*（北極の部品。easyeda2kicad で取得）、
sym-lib-table / fp-lib-table。最後に kicad-cli でネットリストを書き出し、PARTS の表と一致するかを確かめる。

書き方は kiban/EasyEDA/tools/kicad/kicad_flat.py と同じ（点線の枠と見出し、ピンから 2.54 mm の線 + グローバルラベル、
部品ごとの GND 記号、未接続は × 印）。ネット名は kiban/EasyEDA/docs/interfaces.md に合わせる。
"""
import json
import os
import re
import subprocess
import sys

HERE = os.path.dirname(os.path.abspath(__file__))
REPO = os.path.abspath(os.path.join(HERE, '..', '..'))
sys.path.insert(0, os.path.join(REPO, 'kiban', 'EasyEDA', 'tools', 'kicad'))
import kicad_flat as K  # noqa: E402
from eda2kicad_core import det_uuid  # noqa: E402

NAME = 'core-XIAO-04'
NORTH = 'north-pole-04'
SRC03 = '/Users/katano/work/FPC-isolation-sphere/kiban/core-XIAO-03/core-XIAO-03.kicad_sch'


# 部品表（BOM）に入れない部品（はんだジャンパと、テスト用の 1 ピンヘッダ）
NO_BOM = {'JP1', 'TP1', 'TP2'}


class Out(K.Out):
    """部品の位置を 1.27 mm の格子に合わせてから書く（ピンと線の端が格子に乗る）。"""
    def part(self, p, ref_at, val_at):
        p.x, p.y = K_snap(p.x), K_snap(p.y)
        super().part(p, ref_at, val_at)
        # kicad_flat.py が付ける「EasyEDA」欄（旧部品名）は、この基板では意味がないので消す
        self.lines[-1] = re.sub(r'\n\t\t\(property "EasyEDA" "[^"]*"\n(?:\t\t\t.*\n)*?\t\t\)', '', self.lines[-1])
        if p.new in NO_BOM:
            self.lines[-1] = self.lines[-1].replace('(in_bom yes)', '(in_bom no)', 1)


def K_snap(v, g=1.27):
    return round(round(v / g) * g, 4)


BOARD_B_PRO = os.path.join(REPO, 'kiban', 'EasyEDA', 'kicad', 'boardB', 'boardB.kicad_pro')

R0603 = 'Resistor_SMD:R_0603_1608Metric'
C0603 = 'Capacitor_SMD:C_0603_1608Metric'
H254 = 'Connector_PinHeader_2.54mm:PinHeader_1x{:02d}_P2.54mm_Vertical'
H200 = 'Connector_PinHeader_2.00mm:PinHeader_1x{:02d}_P2.00mm_Vertical'

# 北極ケーブル（core-XIAO-04 の J3 = north-pole-04 の J1）
NORTH_PINS = {'1': '3V3_AON', '2': 'HALL_WAKE', '3': 'GND', '4': 'LED_D6', '5': '3V3_MCU'}

# XIAO ESP32S3 のピン名（03 の記号は RP2040 の名前なので付け直す）
XIAO_PINS = {'1': 'D0/GPIO1', '2': 'D1/GPIO2', '3': 'D2/GPIO3', '4': 'D3/GPIO4', '5': 'D4/GPIO5',
             '6': 'D5/GPIO6', '7': 'D6/TX/GPIO43', '8': 'D7/RX/GPIO44', '9': 'D8/GPIO7', '10': 'D9/GPIO8',
             '11': 'D10/GPIO9', '12': '3V3', '13': 'GND', '14': '5V'}

# ピンの割り当て：XIAO の 1〜7 番側（D0〜D6）に LED データ 6 本とブザー、8〜11 番側（D7〜D10）に制御と I2C。
# - D6（GPIO43）は UART0 TX。起動中に High やブートログが出るので LED データには使わない（ブザーなら害がない）
# - D7（GPIO44）は RX。起動中は入力のままなので LED_EN（基板A のプルダウンで OFF）に使う
# - PWR_KILL は D8（GPIO7）。ストラッピングピンではなく、起動中に Low にならない
# - I2C は D9（SCL）/ D10（SDA）。ESP32-S3 はどのピンにも割り当てられるので、ファームの Wire.begin() でピンを指定する
# - 8〜11 番の並び（LED_EN、PWR_KILL、SCL、SDA）は、J1 のピン順に合わせた（配線が交差しない）
# 部品：(部品番号, 記号, 値, フットプリント, LCSC, 種類, {ピン: ネット})
PARTS = {
    'U1': ('XIAO', 'XIAO ESP32S3', f'{NAME}:XIAO-ESP32S3', '', 'ic',
           {'1': 'LED_GPIO1', '2': 'LED_GPIO2', '3': 'LED_GPIO3', '4': 'LED_GPIO4', '5': 'LED_GPIO5', '6': 'LED_GPIO6',
            '7': 'BUZZER', '8': 'LED_EN', '9': 'PWR_KILL', '10': 'I2C_SCL', '11': 'I2C_SDA',
            '12': '3V3_XIAO', '13': 'GND', '14': None}),
    'JP1': ('Jumper:SolderJumper_2_Bridged', '3V3 切り離し', 'Jumper:SolderJumper-2_P1.3mm_Bridged_RoundedPad1.0x1.5mm',
            '', 'ic', {'1': '3V3_MCU', '2': '3V3_XIAO'}),
    'C1': ('Device:C_Small', '10uF', C0603, 'C19702', 'passive', {'1': '3V3_XIAO', '2': 'GND'}),
    'C2': ('Device:C_Small', '0.1uF', C0603, 'C14663', 'passive', {'1': '3V3_XIAO', '2': 'GND'}),
    # LED データ線の直列抵抗（送り側 = XIAO の近くに置く）。6 本目は北極の LED
    **{f'R{i}': ('Device:R_Small_US', '33Ω', R0603, 'C23140', 'passive',
                 {'1': f'LED_GPIO{i}', '2': f'LED_D{i}'}) for i in range(1, 7)},
    'R7': ('Device:R_Small_US', '10kΩ', R0603, 'C25804', 'passive', {'1': 'LED_D6', '2': 'GND'}),
    'J1': ('Connector_Generic:Conn_01x07', 'RING-L', H254.format(7), '', 'conn',
           {'1': 'GND', '2': '3V3_MCU', '3': 'I2C_SDA', '4': 'I2C_SCL', '5': 'PWR_KILL', '6': 'LED_EN',
            '7': '3V3_AON'}),
    'J2': ('Connector_Generic:Conn_01x07', 'RING-R', H254.format(7), '', 'conn',
           {'1': 'LED_D1', '2': 'LED_D2', '3': 'LED_D3', '4': 'LED_D4', '5': 'LED_D5', '6': 'GND',
            '7': 'HALL_WAKE'}),
    # 北極へ 5 本。GND を真ん中に置き、HALL_WAKE と LED データの両方の隣にする
    'J3': ('Connector_Generic:Conn_01x05', 'NORTH', H200.format(5), '', 'conn', NORTH_PINS),
    # 秋月 AE-BNO055-BO（18 × 11 mm、2.54 mm × 4 ピン 2 列、列間 7.62 mm = DIP-8 と同じ並び）を直接はんだ付けする。
    # 1 VIN、2 GND、3 SDA、4 SCL、5 RESET、6 INT（2.8 V）、7 GND、8 VOUT（2.8 V）。I2C アドレス 0x28（出荷時）
    'U2': ('Connector_Generic:Conn_02x04_Counter_Clockwise', 'AE-BNO055-BO', 'Package_DIP:DIP-8_W7.62mm', '', 'conn',
           {'1': '3V3_MCU', '2': 'GND', '3': 'I2C_SDA', '4': 'I2C_SCL', '5': None, '6': None, '7': 'GND', '8': None}),
    'LS1': ('BUZZER', 'PKLCS1212E4001', f'{NAME}:Buzzer-PKLCS1212', '', 'ic', {'LEAD+': 'BUZZER', 'LEAD-': 'GND'}),
    'C3': ('Device:C_Small', '0.1uF', C0603, 'C14663', 'passive', {'1': 'BUZZER', '2': 'GND'}),
    'D1': ('Device:LED_Small', 'RED', 'LED_SMD:LED_0603_1608Metric', 'C2286', 'ic', {'1': 'GND', '2': 'PWR_LED'}),
    'R8': ('Device:R_Small_US', '1kΩ', R0603, 'C21190', 'passive', {'1': '3V3_MCU', '2': 'PWR_LED'}),
    'TP1': ('Connector_Generic:Conn_01x01', '3V3_MCU', H254.format(1), '', 'conn', {'1': '3V3_MCU'}),
    'TP2': ('Connector_Generic:Conn_01x01', 'GND', H254.format(1), '', 'conn', {'1': 'GND'}),
}
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

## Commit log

2026-10-06 feat: XIAO ESP32S3 版として分岐 (LCD / M5 / AtomS3R を削除、省電力機能を追加)
    AtomS3R 版 (isolation-sphere-solo) から分岐。コア基板を XIAO ESP32S3 で作り直すのに合わせる。
    - 削除: LCDManager、M5 内蔵 IMU バックエンド (IMUManager_m5imu / MadgwickAHRS)、board_atoms3r.h、
    M5Unified 依存、atoms3r* の env、設定の LCD 項目、LCD / 本体ボタン連動コード
    - 追加: AP の無操作自動停止 (NVS 保存、既定 10 分)、AP の明示 ON/OFF、モデム省電力の切替、
    トリプルシェイクでの AP 切替 (/api/power、シリアル、MQTT system)
    - platformio.ini は xiao_esp32s3 / *_ota / *_lan_ota / native に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
2026-10-08 docs: コアの STL を保存し、基板・セルの収納検討を断面の塊単位でやり直す
    - 評価に使ったコアの STL (core-north-03_fixed / core-south-03_fixed) を docs/cad/ に保存し、由来と SHA-256 を記載
    - fit_check.py を作り直し: 断面の塊を一つずつ障害物として、基板・セルの輪郭の干渉を判定 (従来の包絡による判定は厳しすぎた)
    - セルを 40x40x10mm に更新。基板Aの張り出しはピンソケット 1x6 に合わせた案を算出
    - 結果: 基板Aの張り出しは ±y 向きなら収まる。A↔B 7mm で基板Bの 40mm 角は当たる (37mm 角または隅 7mm 面取りで収まる)。北のセルは x=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
    [core-north-03_fixed.stl, core-south-03_fixed.stl]
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2026-10-08 docs: 基板Bノートの型番の誤記を修正 (BQ28Z610 → BQ28Z620)
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2026-10-08 feat: 基板B 保護部 (BQ28Z620、FS8205A、ヒューズ、シャント、コネクタ) の回路図を作成
    - tools/build_boardB_protection.py: BQ28Z620 データシート Figure 10-1 に従い PROTECTION ページに配置
    (GND=PACK−、BAT_N=セル−、シャントはケルビン、保護 FET は共通ドレインで CHG 側を電池側に)
    - 電池コネクタ XH 2P×2、ヒューズ C108585、基板A 接続 1x6×2 を追加
    - eda_bridge.py: 置き先ページを同じ処理内で開いて確認してから置くように修正
    (アクティブなページが変わり、BoardA に誤配置した不具合の対策)
    - ネットリスト: 65 部品、44 ネット。ページをま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
2026-10-08 feat: 基板A / 基板B の回路図を KiCad 10 の階層回路図に変換 (EasyEDA から自動生成)
    - tools/kicad/kicad_export.py: ページごとに取り出し、親シート + 子シートの KiCad 回路図を生成
    (つながった線の島ごとにラベル、2 ページ以上のネットはグローバルラベル)
    - kicad-cli でネットリストを書き出して EasyEDA と比較: 基板A 23 ネット、基板B 43 ネットとも一致
    - 座標変換・シンボル生成は power-2S-02 の eda2kicad.py を tools/kicad/eda2kicad_core.py として取り込み
    - kicad/README.md に作り直し方と限界 (フットプリントなし、ERC 不可) を記載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
    [boardA.kicad_sch, boardA_LED_IO.kicad_sch, boardA_POWER.kicad_sch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]
2026-10-08 feat: KiCad 版の回路図に LCSC のシンボル・フットプリントを使う (easyeda2kicad)
    - tools/kicad/lcsc_lib.py: LCSC 部品を easyeda2kicad で取得し、3D パスを直して KiCad 10 形式に更新、
    boardA / boardB に lcsc ライブラリを登録 (未取得の部品だけを、間隔を空けて取得)
    - kicad_export.py: 取得したシンボルを、EasyEDA とピン位置が一致する向きで使い、フットプリントを割り当てる
    (合わない部品と未取得の部品は従来の矩形シンボル)。回転した部品の値の文字は横書きのまま
    - 47 種類中 30 種類を取得 (残りは EasyEDA API の 403 で未取得)。111 部品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
    [boardA_LED_IO.kicad_sch, boardA_POWER.kicad_sch, boardB_CHARGER.kicad_sch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]
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2026-10-09 feat: 基板A / B の回路図を 1 枚に統合し、フットプリント・LCSC 品番・テストポイントを入れる
    - 基板B: CHARGER と PROTECTION を手で 1 枚に統合 (KiCad が元データ)
    - 基板A: kicad_flat.py で基板B と同じ書き方の 1 枚に作り直し、I2C プルアップ R9/R10 を削除、テストピン J5〜J10 を追加
    - assign_footprints.py: LCSC 品番からフットプリントを割り当てる
    - testpoints.py: テストパッドを回路図に追加する
    [boardA.kicad_sch, boardA_LED_IO.kicad_sch, boardA_POWER.kicad_sch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]
2026-10-09 feat: 基板A / B の PCB (配置・配線途中) と、配置・自動配線・結び付けの道具
    - 基板B: 40 mm 角・隅 8 mm 面取り、4 層 (In1 = GND)、部品は表面、配線済み
    - 基板A: 40 mm 角 + 左右の張り出し、部品は裏面 (基板B 側)、配線途中
    - A↔B ヘッダの 12 ピンの座標・ネットが一致することを確認
    - pcb_route.py: Freerouting での自動配線、relink.py: フットプリントをシンボルに結び付け直す
    [boardA.kicad_pcb, boardB.kicad_pcb]
2026-10-09 feat: 基板B にテストピン (J10〜J14) を追加し、配線を修正。基板A の設定を更新
    [boardB.kicad_pcb, boardB.kicad_sch]
2026-10-09 feat: 基板B の部品を裏面 (内殻側) に移した版 boardB-reverse を追加
    - 基板B をコピーして全体を裏返し、部品を裏面、GND 面を In2 に
    - 基板A とのヘッダ (J2、J3) は 12 ピンの座標・ネットが基板A の J3、J4 と一致 (ずれ 0)
    - A と B の間には基板A の部品だけが入る。採用するかは、基板B の下の空間を確認してから決める
    - pcb_mirror.py: 裏返しとヘッダの合わせ直しの手順
    [boardB-reverse.kicad_pcb, boardB-reverse.kicad_sch]
2026-10-10 feat: MCU 基板 core-XIAO-04 と北極基板 north-pole-04 の回路図を追加
    - XIAO ESP32S3 に基板A の 3V3_MCU を直接入れる (5V ピンは未使用、JP1 で切り離し可)
    - LED 6 本 (D0〜D5、33 Ω を XIAO の近くに)、ブザー D6、LED_EN D7、I2C D8/D9、PWR_KILL D10
    - mother-ring とは 1×7 ×2 (03 と同じ位置)、北極とは 1×5 (3V3_AON / HALL_WAKE / GND / LED_D6 / 3V3_MCU)
    - IMU は秋月 AE-BNO055-BO を直接実装 (I2C プルアップ内蔵)
    - 北極: DRV5032FC + 動作確認用 LED、北極 LED (6 本目のストリップ、3V3_MCU 給電)
    - 回路図は make_sch.py で生成し、ネットリストを照合する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
    [core-XIAO-04.kicad_sch, north-pole-04.kicad_sch]
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2026-10-10 feat: core-XIAO-04 の PCB (配置) を追加。回路図の BOM 除外と不要な欄を整理
    - make_pcb.py: core-XIAO-03 と同じ外形 (40 mm 角 + 左右の張り出し + XIAO の穴) に配置する
    XIAO は 03 と同じ位置、LED 用 33 Ω は XIAO の 1〜6 番ピンの横、mother-ring ヘッダは右 J2 / 左 J1
    フットプリントは回路図のシンボルに結び付ける (path)。回路図との照合は差分 0
    - make_sch.py: JP1 / TP1 / TP2 を BOM から外し、不要な EasyEDA 欄を消す。名前を指定して一方だけ生成できる
    - north-pole-04 は KiCad で保存された内容 (WS2812 の未接続ピンの扱い、プロジェクト設定)
    Co-Autho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
    [core-XIAO-04.kicad_pcb, core-XIAO-04.kicad_sch, north-pole-04.kicad_sch]
2026-10-10 feat: goldberg (カセット用 FPC) を追加。電源を VDD に統一し、LED を LCSC の WS2812C-2020-V6 に置き換え
    - FPC-isolation-sphere/kiban/FPC_goldberg のコピーを取り込む (製造用の production/ は古いので含めない)
    - 電源ネット +5V を VDD に統一。回路図ではコンデンサだけが +5V、LED は VDD で別ネットだったため、
    回路図と PCB の照合の食い違いが 85 件から 5 件になった (残りは J1 / J2 のピン割り当て)
    - LED を LCSC C55109522 (WS2812C-2020-V6) に置き換え (swap_led_v6.py)
    足型は LCSC のもの (番号 1 DO / 2 GND / 3 DI / 4 VDD、attr smd)。パッド寸法は配線をそのまま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
    [goldberg.kicad_pcb, goldberg.kicad_sch]
2026-10-11 feat: core-XIAO-04 / north-pole-04 の回路図を確定 (J4・J5・TP3・TP4 の追加、PWR_FLAG、注記)
    - KiCad で追加された J4 (3V3) / J5 (5V) / TP3 / TP4 を取り込み。足型 HDR-TH_2P-P2.54-V-M をプロジェクトの lib に追加
    - GND に PWR_FLAG を追加 (ERC のエラー 0 件)。北極側も同様
    - MCU の枠の注記に「5V ピンへ外から 5V を入れるときも JP1 を切るか電池側を OFF にする」を追記
    - make_sch.py: KiCad で保存された回路図は上書きしない (--force で作り直し)。core-XIAO-04 は以後 KiCad が正
    [core-XIAO-04.kicad_sch, north-pole-04.kicad_sch]
2026-10-11 feat: goldberg の LED パッドを LCSC の寸法 (0.8 x 0.8) にして配線を引き直した版
    - LED (C55109522) の足型のパッドを LCSC の原本の寸法にした (ステンシルでのリフローをしやすくするため)
    - 配線を引き直し、クリアランス違反・短絡・未接続を解消 (DRC: 未接続 0、照合の差は J1 / J2 の 5 件のみ)
    - swap_led_v6.py: 入れ替え済みの PCB でもパッド寸法を変えられるようにした (--force)
    [goldberg.kicad_pcb]
2026-10-11 feat: core-XIAO-04 の XIAO のピンを J1 の並びに合わせて入れ替え (配線が交差しない順)
    - D8 (GPIO7) = PWR_KILL、D9 (GPIO8) = I2C_SCL、D10 (GPIO9) = I2C_SDA。LED_EN は D7 のまま
    J1 のピン順 (LED_EN、PWR_KILL、SCL、SDA) と XIAO の並びが揃い、配線が交差しない
    - 回路図のラベル、PCB のパッドのネット、MCU の枠の注記、make_sch.py の表を更新
    - PCB: 外形を基板A に合わせた版 (取り付け穴 4 か所、J1 / J2 を x = ±21.59 に)、J4 / J5 / TP3 / TP4 を取り込み
    - interfaces.md FW-5: I2C のピンと Wire.begin(9, 8) を更新
    [core-XIAO-04.kicad_pcb, core-XIAO-04.kicad_sch]
2026-10-11 feat: core-XIAO-04 の PCB を配線済みにする (自動配線 + 端の手直し、DRC エラー 0)
    - Freerouting で配線 (2 層、未配線 0)。電源 (3V3_MCU / 3V3_XIAO / 5V) は 0.4 mm、信号は 0.25 mm
    - GND のベタを表面と裏面に追加。パッドの付け根にティアドロップ
    - 基板の端から 0.5 mm 未満だった配線とパッドを手直し (最短 0.52 mm)。J1 / J2 側の張り出しを広げた (外形 46.2 x 40.2 mm)
    - ネットクラス Power (0.4 mm) をプロジェクトに追加
    - DRC: エラー 0、警告 23 (シルクのみ)。回路図との照合は IMU の未使用ピン 3 件のみ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
    [core-XIAO-04.kicad_pcb, core-XIAO-04.kicad_sch]
